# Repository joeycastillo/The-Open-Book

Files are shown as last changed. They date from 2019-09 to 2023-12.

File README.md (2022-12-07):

# The Open Book: Project Reboot

**A note from the project creator:** The Open Book was my first real electronics project; the earliest designs date to late 2019. I have learned a lot since those early days, and as such, here three years later, I am hitting reset. At this time the repository contains a version of the Open Book designed around the Raspberry Pi Pico. It's optimized for low part count and easy hand assembly, but it runs on AAA batteries and may not be as svelte as some folks might prefer. At a later date, I hope to design a followup with built-in LiPo charging and a slimmer profile, but at this time, this version of the book is the quickest path to getting hardware in people's hands so that we can start hacking on firmware together.

For details on how to build, test and use Open Book, I've [made documentation available here](https://www.oddlyspecificobjects.com/projects/openbook/).

The original Open Book repository has been archived in a branch called [original](https://github.com/joeycastillo/The-Open-Book/tree/original).

[The Open Book firmware, called libros, is under development here](https://github.com/joeycastillo/libros). It's a goddamn mess in some ways, and in dire need of some documentation, but for the moment it does do the job of presenting a list of books stored on an SD card, and letting you read them. The canonical format for books is plain text with the book title on the first line, OR plain text plus some front matter and some ASCII control codes for chapter breaks and formatting, [as documented here](https://www.oddlyspecificobjects.com/projects/openbook/#advanced-text-formatting).

## Original Introduction

As a society, we need an open source device for reading. Books are among the most important documents of our culture, yet the most popular and widespread devices we have for reading — the Kobo, the Nook, the Kindle and even the iPad — are closed devices, operating as small moving parts in a set of giant closed platforms whose owners' interests are not always aligned with readers'.

The Open Book aims to be a simple device that anyone with a soldering iron can build for themselves. The Open Book should be comprehensible: the reader should be able to look at it and understand, at least in broad strokes, how it works. It should be extensible, so that a reader with different needs can write code and add accessories that make the book work for them. It should be global, supporting readers of books in all the languages of the world. Most of all, it should be open, so that anyone can take this design as a starting point and use it to build a better book.

## State of the Book

At this time, the Pi Pico book is in decent shape if you want to try your hand at building it yourself. You will need to have two custom things fabricated: the **Open Book Main Board** (which you can get as a bare PCB) and the **Castellated E-Paper Driver** module (which you'll want to have done as a PCBA job). All the files you will need to send out for this can be found in the **Fabrication Files** folder in the project root:

* Upload `OSO-BOOK-C1-04-rounded.zip` to your PCB fabrication house of choice. It is designed to be a two-layer, 1 mm thick PCB, and you can use either an ENIG or lead-free HASL finish.
* If you plan to use JLCPCB's economic PCBA service, upload all three files in `OSO-BOOK-C2-01` to JLCPCB. Opt for a 1 mm thick lead-free HASL finish. Note that the board is slightly wider than it needs to be, just to meet the minimum size requirements for this service.
* If you plan to use PCBWay's PCBA service, upload all three files in `OSO-BOOK-C2-02` to PCBWay. Once again, opt for a 1 mm thick lead-free HASL finish. 

Other Parts: 

* Two of these [side mount buttons](https://www.digikey.com/en/products/detail/würth-elektronik/434351045816/5209090)
* One of these [side-mount switches](https://www.digikey.com/en/products/detail/c-k/JS102011SAQN/1640095)
* One [MEM2075 MicroSD card slot](https://www.digikey.com/en/products/detail/gct/MEM2075-00-140-01-A/9859614)
* One [GD25Q16C Flash chip](https://www.digikey.com/en/products/detail/gigadevice-semiconductor-hk-limited/GD25Q16CTIGR/9484675) with SOIC / SOP8 footprint.
* One [Keystone 1022 dual AAA battery holder](https://www.digikey.com/en/products/detail/keystone-electronics/1022/2137859) (you can get clones on Aliexpress for cheap)
* Two P-channel MOSFETS with SOT23 footprint (I use the DMG3415)
* Two 10kΩ resistors with 1206 footprint.
* Two 10µF capacitors with 1206 footprint (rated voltage >=6.3V).
* One 1µF capacitor with 0805 footprint (rated voltage >=6.3V).
* Seven through-hole slim tactile buttons (3mm by 6mm; [TL1107 type](https://www.digikey.com/en/products/detail/e-switch/TL1107AF130WQ/378976))
* One [GDEW042T2 grayscale e-paper display](https://buy-lcd.com/products/42inch-e-inkanel-spi-interface-buy-eaper-display). (Don't get the tri-color version; it'll end in heartbreak)
* And finally, one [Raspberry Pi Pico](https://www.digikey.com/en/products/detail/raspberry-pi/SC0915/13624793) board

The Open Book is open source hardware: you should feel free to build one yourself, order parts for ten and do a workshop at your local maker space, or even buy parts for fifty and sell them as kits. 

Please steal this book.

I plan to add more documentation in the new year, but until then, [this half-hour video walks through building one Open Book board in real-time](https://twitter.com/i/broadcasts/1OyKAVPjrvaGb).

### Forking and tweaking the boards

* Design files for the Open Book main board can be found in the `OSO-BOOK-C1` folder. It's a KiCad project.
* Design files for the castellated e-paper driver module can be found in the `OSO-BOOK-C2` folder. Alas, they are Eagle projects that predate my move to KiCad. There are two versions: an older version that was successfully fabricated with JLCPCB's economic PCBA service (`OSO-BOOK-C2-01`), and a newer version successfully fabricated using PCBWay's PCBA service (`OSO-BOOK-C2-02`). Both work great.

## License

 Different components of the project are licensed differently, see [LICENSE.md](https://github.com/joeycastillo/The-Open-Book/blob/main/LICENSE.md).

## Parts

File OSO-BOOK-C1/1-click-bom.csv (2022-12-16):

References | Qty | Description | Manufacturer | MPN | Digikey | Mouser | RS | Newark | Farnell | LCSC | JLC Assembly
B1, B2, | 2 | Right-angle push button, SPST |  | 434351045816 | 732-7057-1-ND | 710-434351045816
SW1, | 1 | Right-angle slide switch, SPDT |  | JS102011SAQN | 401-1999-1-ND | 611-JS102011SAQN
BT1, | 1 | Battery holder for 2x AAA cells |  | 1022 | 36-1022-ND | 534-1022
Q1, Q2, | 2 | P-MOSFET transistor, gate/source/drain |  | DMG3415U-7 | DMG3415UDIDKR-ND | 621-DMG3415UQ-7
C1, C2, | 2 | 10µF capacitor, 1206 |  | CL31B106KQHNFNE | 1276-3107-1-ND | 187-CL31B106KQHNFNE
C3, | 1 | 1µF capacitor, 0805 |  | CL21B105KAFNNNE | 1276-1066-1-ND | 187-CL21B105KAFNNNF
R3, R4, | 2 | 10KΩ resistor 1206 |  | RMCF1206JT10K0 | RMCF1206JT10K0CT-ND | 652-CR1206FX-1002ELF
U1, | 1 | Raspberry Pi Pico |  | SC0918 | 2648-SC0918CT-ND | 713-102110537
U3, | 1 | MicroSD card slot, push/push |  | MEM2075-00-140-01-A | 2073-MEM2075-00-140-01-ACT-ND | 640-MEM20750014001A
U4, | 1 | 2 MB Flash memory chip |  | GD25Q16CTIGR | 1970-1010-1-ND | 363-GD25Q16CTIGR
B3, B4, B5, B6, B7, B8, B9, | 7 | Through-hole push button, SPST |  | TL1107AF180WQ | EG2511-ND | 612-TL1107
J1, J2, | 2 | STEMMA connector. OPTIONAL |  | S3B-PH-SM4-TB(LF)(SN) | 455-1790-1-ND
J3, | 1 | STEMMA QT connector. OPTIONAL |  | BM04B-SRSS-TB(LF)(SN) | 455-1750-1-ND
R1, R2, | 2 | 1k resistor, 0805. OPTIONAL |  | RC0805JR-071KL | 311-1.0KARCT-ND | 603-RC0805JR-071KL
U2, | 1 | Oddly Specific castellated E-paper driver module |  | OSO-BOOK-C2-01
Display | 1 | 4.2 Inch B&W E-paper Panel |  | GDEW042T2

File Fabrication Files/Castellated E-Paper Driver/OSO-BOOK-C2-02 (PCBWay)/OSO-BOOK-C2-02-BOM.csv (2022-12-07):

Item # | *Designator | *Qty | Manufacturer | *Mfg Part # | Description / Value | *Package/Footprint | Type | Your Instructions / Notes
1 | R1 | 1 | UNI-ROYAL | 0603WAJ047KT5E | 0.47Ω ±1% 1/16W ±800ppm/℃ 0603 Chip Resistor - Surface Mount RoHS | 0603 | SMD
2 | L1 | 1 | microgate | MGFL2012F100MT-LF | 10uH ±20% 500mA 320mΩ 0805 Inductors (SMD) RoHS | 0805 | SMD
3 | C1, C2, C3, C4, C5, C6, C7, C8, C9 | 9 | Samsung Electro-Mechanics | CL21B105KBFNNNE | 1uF ±10% 50V X7R 0805 Multilayer Ceramic Capacitors MLCC - SMD/SMT RoHS | 0805 | SMD
4 | C10 | 1 | Samsung Electro-Mechanics | CL21A475KAQNNNE | 4.7uF ±10% 25V X5R 0805 Multilayer Ceramic Capacitors MLCC - SMD/SMT RoHS | 0805 | SMD
5 | J1 | 1 | JUSHUO | AFC07-S24ECC-00 | Contact,Top 24 0.020"（0.50mm） 0.079"（2.00mm） Slide Lock 24P FFC, FPC Connectors RoHS | FFC | SMD
6 | Q1 | 1 | Infineon Technologies | IRLML0100TRPBF | N-Channel 100V 1.6A 2.5V @ 25uA 220mΩ @ 1.6A,10V 1.3W SOT-23(SOT-23-3) MOSFET RoHS | SOT-23-3 | SMD
7 | D1, D2, D3 | 3 | LRC | LMBR0530T1G | 30V 500mA 450mV @ 500mA SOD-123 Schottky Barrier Diodes (SBD) RoHS | SOD-123 | SMD

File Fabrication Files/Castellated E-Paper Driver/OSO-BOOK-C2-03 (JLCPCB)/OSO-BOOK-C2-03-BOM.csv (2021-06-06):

Qty | Designator | Footprint | Comment | LCSC Part # | Description
1 | R1 | R0402 | 0.47ohm | C423162 | 0.47Ω ±1% 1/16W ±800ppm/℃ 0402 Chip Resistor - Surface Mount RoHS
1 | L1 | L0805 | 10uH | C281113 | 10uH ±20% 500mA 320mΩ 0805 Inductors (SMD) RoHS
9 | C1, C2, C3, C4, C5, C6, C7, C8, C9 | C0805 | 1uF >=25V | C28323 | 1uF ±10% 50V X7R 0805 Multilayer Ceramic Capacitors MLCC - SMD/SMT RoHS
1 | C10 | C0805 | 4.7uF >=25V | C1779 | 4.7uF ±10% 25V X5R 0805 Multilayer Ceramic Capacitors MLCC - SMD/SMT RoHS
1 | J1 | AFC07-S24ECC-00 | Flex connector | C11092 | Contact,Top 24 0.020"（0.50mm） 0.079"（2.00mm） Slide Lock 24P FFC, FPC Connectors RoHS
1 | Q1 | SOT23-3 | IRLML0100 | C53658 | N-Channel 100V 1.6A 2.5V @ 25uA 220mΩ @ 1.6A,10V 1.3W SOT-23(SOT-23-3) MOSFET RoHS
3 | D1, D2, D3 | SOD-123 | MBR0530 | C18863 | 30V 500mA 450mV @ 500mA SOD-123 Schottky Barrier Diodes (SBD) RoHS

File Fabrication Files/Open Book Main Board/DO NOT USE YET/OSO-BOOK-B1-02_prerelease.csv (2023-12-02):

Comment | Designator | Footprint | LCSC
SW_Push | B1,B2 | Button_Switch_SMD:Panasonic_EVQPUJ_EVQPUA | C128539
10µF | C1,C2,C3,C4,C5,C8 | Capacitor_SMD:C_1206_3216Metric | C13585
4.7µF | C10,C11 | Capacitor_SMD:C_0805_2012Metric | C1779
22pF | C6,C7 | Capacitor_SMD:C_0805_2012Metric | C1804
1µF | C9,C12,C13,C14,C15,C16,C17,C18 | Capacitor_SMD:C_0805_2012Metric | C28323
MBR0530 | D1,D2,D3 | Diode_SMD:D_SOD-123 | C475718
MBR120 | D4 | Diode_SMD:D_SOD-123 | C130880
USB_C_Receptacle_USB2.0 | J1 | Connector_USB:USB_C_Receptacle_HRO_TYPE-C-31-M-12 | C2765186
Conn_01x02_MountingPin | J2 | Connector_Molex:Molex_PicoBlade_53261-0271_1x02-1MP_P1.25mm_Horizontal | C668614
Conn_01x24 | J3 | Connector_FFC-FPC:TE_2-1734839-4_1x24-1MP_P0.5mm_Horizontal | C11092
47µH | L1 | Inductor_SMD:L_Taiyo-Yuden_MD-4040 | C341779
DMG3415 | Q1,Q2 | Package_TO_SOT_SMD:SOT-23 | C96616
IRLML0100 | Q3 | Package_TO_SOT_SMD:SOT-23 | C53658
5.1k | R1,R2 | Resistor_SMD:R_0805_2012Metric | C27834
100K | R11,R12,R13,R14,R15 | Resistor_SMD:R_0805_2012Metric | C149504
1k | R3,R9,R10 | Resistor_SMD:R_0805_2012Metric | C17513
200k | R4 | Resistor_SMD:R_0805_2012Metric | C17539
10K | R5 | Resistor_SMD:R_0805_2012Metric | C17414
2.2 | R6 | Resistor_SMD:R_0805_2012Metric | C17521
1M | R7 | Resistor_SMD:R_0805_2012Metric | C17514
XC6220B331MR-G | U1 | Package_TO_SOT_SMD:SOT-23-5 | C3040644
ESP32-S3-WROOM-1 | U2 | RF_Module:ESP32-S3-WROOM-1 | C2913198
MEM2075 | U3 | MEM2075-00-140-01-A:GCT_MEM2075-00-140-01-A | C393941
MCP73831-2-OT | U4 | Package_TO_SOT_SMD:SOT-23-5 | C424093
32768 / 12.5pF | Y1 | Crystal:Crystal_SMD_3215-2Pin_3.2x1.5mm | C32346

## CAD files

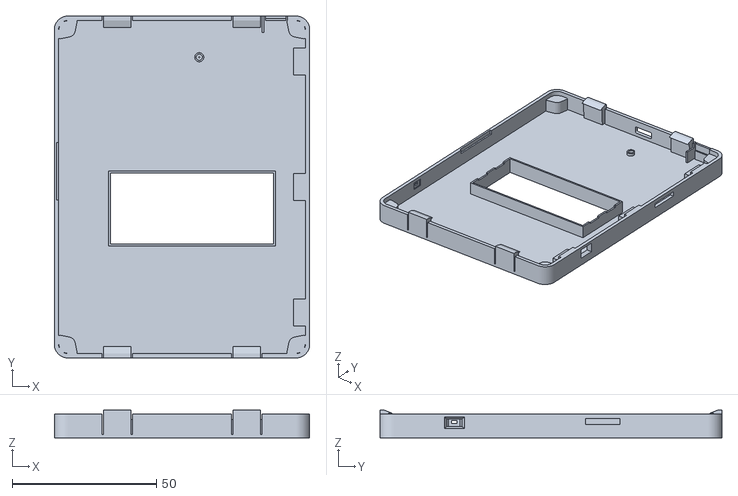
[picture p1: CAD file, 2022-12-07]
3D Printed Case/Open Book Abridged - Minimal Case.stl
88.6 x 118.6 x 9.60

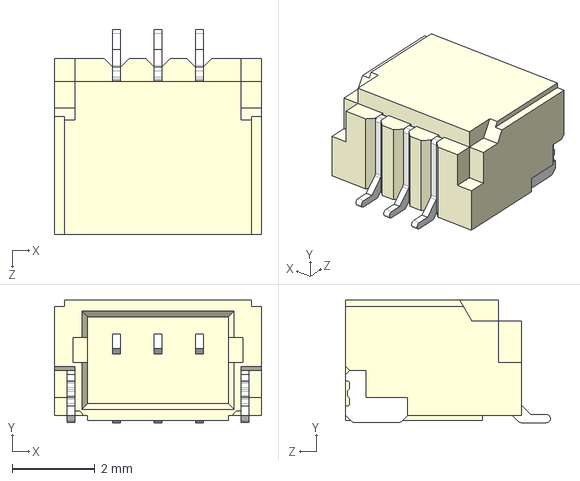
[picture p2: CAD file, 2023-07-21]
OSO-BOOK-B1/SM03B-SRSS-TB(LF)(SN)--3DModel-STEP-56544.STEP
5.00 x 2.96 x 4.95 mm

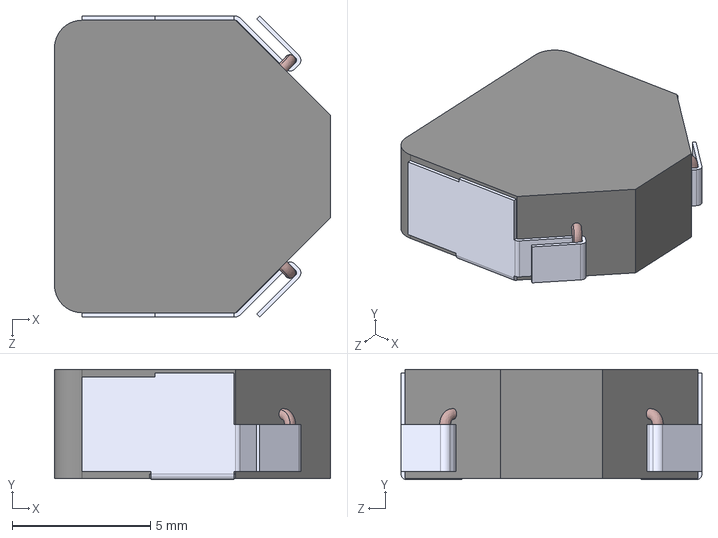
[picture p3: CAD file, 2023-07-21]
OSO-BOOK-B1/DFEG10040D-100M=P3.STEP
10.0 x 4.00 x 10.9 mm

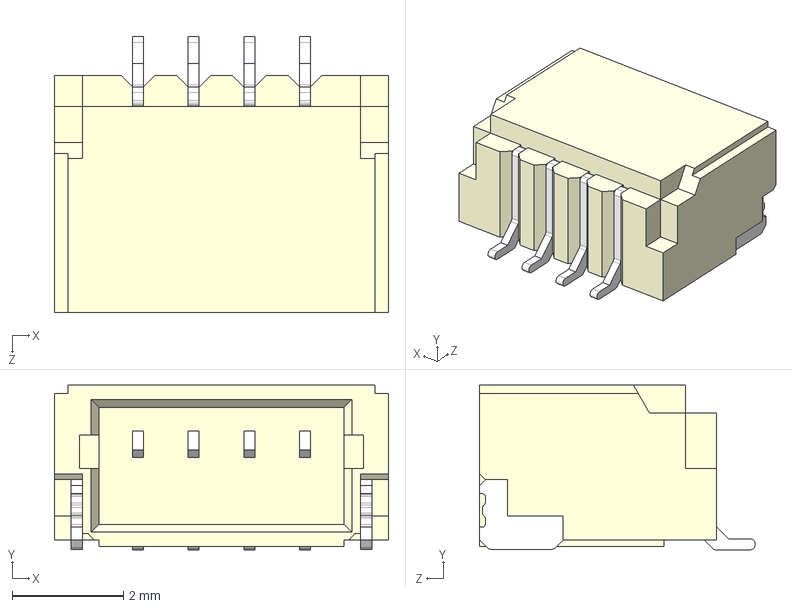
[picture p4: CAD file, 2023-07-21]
OSO-BOOK-B1/SM04B-SRSS-TB(LF)(SN)--3DModel-STEP-56544.STEP
6.00 x 2.96 x 4.95 mm

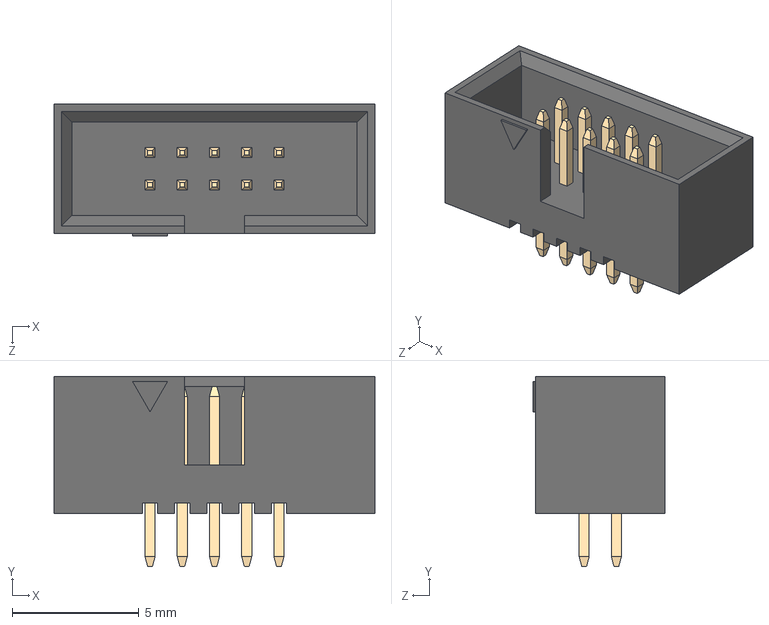
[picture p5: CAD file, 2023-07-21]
OSO-BOOK-B1/CONB127P-2R-10W_TH.STEP
12.7 x 7.50 x 5.20 mm

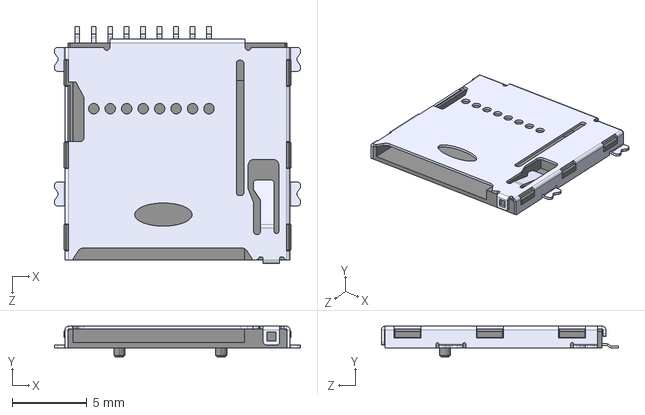
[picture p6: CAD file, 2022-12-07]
OSO-BOOK-B1/MEM2075-00-140-01-A--3DModel-STEP-56544.STEP
16.4 x 2.05 x 15.9 mm

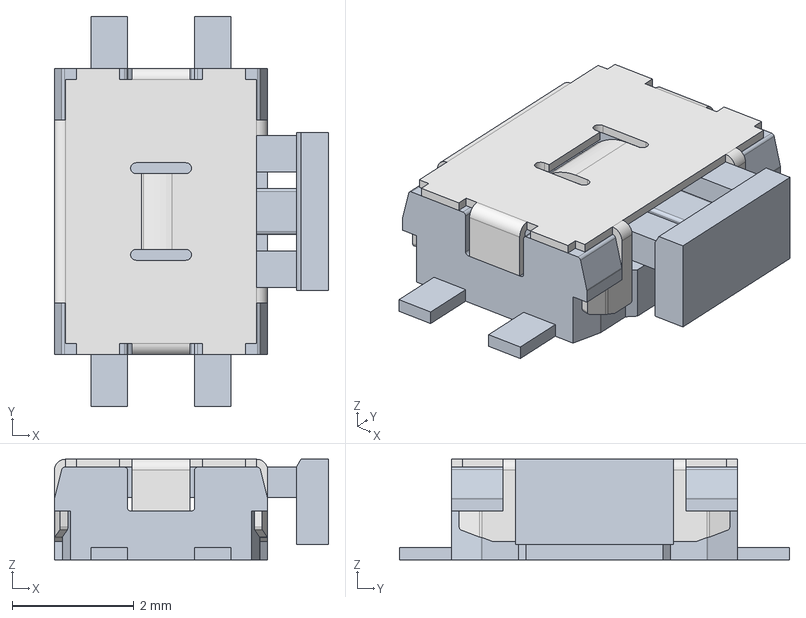
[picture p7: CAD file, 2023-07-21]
OSO-BOOK-B1/434351045816_Download_STP_434351045816_rev1.stp
4.50 x 6.40 x 1.65 mm

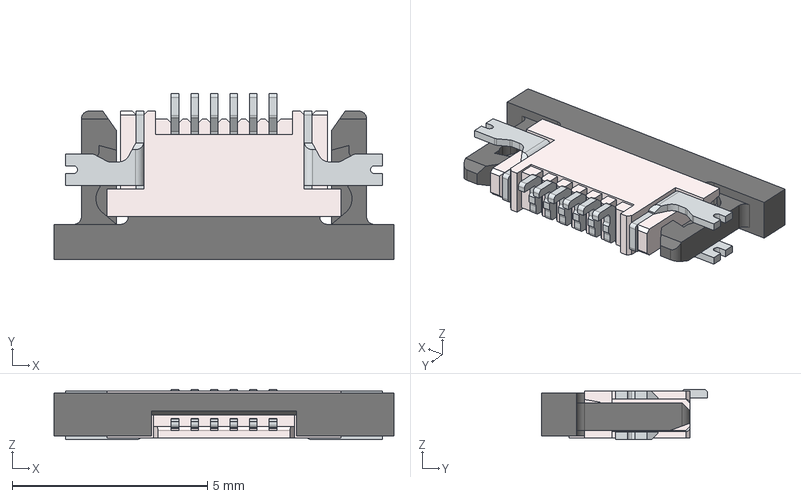
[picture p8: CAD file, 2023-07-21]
OSO-BOOK-B1/687106183622.stp
8.70 x 4.25 x 1.29 mm

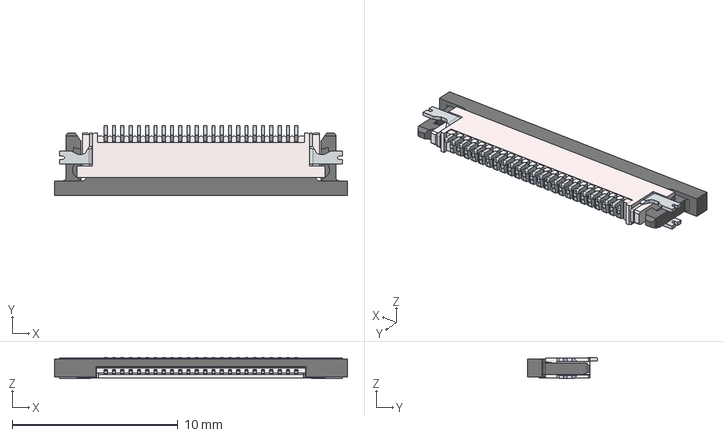
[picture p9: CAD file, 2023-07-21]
OSO-BOOK-B1/687124183622.stp
17.7 x 4.25 x 1.29 mm

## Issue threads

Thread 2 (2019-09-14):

Questions

mistergibson, 2019-09-14:
Dear Mr. Castillo,

1.  Will you use the e-Ink electronic paper at 1200+dpi?

2.  Have you considered using mRuby (embedded Ruby) ( Found Here: https://github.com/mruby/mruby ) in place of the Python selection?

3.  What are the best batteries to use? : I get about 2 weeks out of my Kindle-Paperwhite.

I just also wanted to say Thank You for doing this. I have long wanted an ebook reader unbound to any one corporation. I would spend $150 - $200 to get one that is well designed. I don't need color, and I don't want to watch movies >>> what I want is a high-dpi book-like experience in an ebook reader independent of any one corporation. If you do an at-cost business around this idea please also consider accessorizing with a small USB-based Solar charger for it. You've inspired me just by doing this project. Good Luck to you.

mistergibson

Dragoon91786, 2019-09-14:
Furthermore, if the project decides to use E-Ink/E-Paper, will it use the full color format? httpss://goodereader.com/blog/electronic-readers/e-reader-companies-will-adopt-color-e-paper-in-2018

Dragoon91786, 2019-09-14:
@mistergibson, have you heard about the newer Li batteries that don't wear down over time to any degree as the older ones?

There's also new rechargable alkaline batteries.

I saw in 2012 tech from Northwestern that was using crystals as well. Another possibility would be newer https://en.m.wikipedia.org/wiki/Solid-state_battery as an option if the device uses a universal standard battery plug. One factor with these devices is the lack of universal battery comparability. It would be nice to have a device that could use various sizes and batteries available if necessary. Not necessarily ideal in some minds, but if it could act as a more sophisticated version of the AK-47 in terms of ammo (but from the standpoint of a battery), it would definitely make the devices more universal. Much like how one can run a D battery with adapters using C, B, A, AA, AAA, etc.

joeycastillo, 2019-10-31:
> Will you use the e-Ink electronic paper at 1200+dpi?

At this time I am targeting lower-resolution, inexpensive displays that are widely available. I do not know of a source for 1200dpi screens.

> Have you considered using mRuby (embedded Ruby) ( Found Here: https://github.com/mruby/mruby ) in place of the Python selection?

I have not, currently my experience is in Arduino and CircuitPython, but you're more than welcome to hack on mRuby if you're stoked about it!

> What are the best batteries to use? : I get about 2 weeks out of my Kindle-Paperwhite.

I'm currently using [this battery from Adafruit](https://www.adafruit.com/product/3898) because it fits nicely between the Feather headers. Eventually when an enclosure is built it might make sense to have room for a larger battery, but I have no sense at this time what battery life will be like.

> if the project decides to use E-Ink/E-Paper, will it use the full color format?

I doubt it as I have not seen a source for full-color eInk panels. I have done tests with some tri-color panels, but their refresh rate is far too slow to allow for a good reading experience.

Closed 2019-10-31.

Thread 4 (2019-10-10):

License

sharpaper, 2019-10-10:
What's the license of this project and the PCBs?

Velua, 2019-10-10:
AGPLv3!

sharpaper, 2019-10-10:
I've actually noticed that the PCBs have a cc-by-sa license printed at the bottom. I see no files mentioning AGPL.

joeycastillo, 2019-10-31:
The boards are CC-BY-SA 4.0.

Closed 2019-10-31.

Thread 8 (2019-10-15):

Contribution Guide

hazkaz, 2019-10-15:
Hi @joeycastillo , this is a great effort and idea. It would be nice if you could put up a contribution guide for people like me wanting to work on this project. Thanks.

ech0r, 2019-10-15:
I would like to contribute as well. I came across this project on Hacker News.

titimoby, 2019-10-15:
How do you think we can help you?

To have more code contribution quickly, do you think a simpler device like only a feather M4 with a e-ink wing directly from adafruit could be a first base to help you?

hazkaz, 2019-10-17:
How do we find out what other boards will be compatible with the software? Since the hardware is likely to change in the future, how do we make the code more compatible with other hardware?

titimoby, 2019-10-17:
Don't be sorry, as I can see, there is quite a lot of people interested and you have many questions ;)
I'm sure you need some time to have a proper hardware you are happy with and I will wait.

But in the meantime, I was wondering if existing pieces from Adafruit can be put together to start messing with software: I mean something usable even if it is on a breadboard with plenty of wires.

joeycastillo, 2019-10-17:
Actually yes! Mostly. There are a couple of parts you'd need from elsewhere (namely the [screen](https://zh-tw.buyepaper.com/42inch-e-ink-panel-spi-interface-buy-e-paper-display-p0085.html) and a spare [SPI Flash chip](https://www.digikey.com/product-detail/en/gigadevice-semiconductor-hk-limited/GD25Q16CTIGR/1970-1010-1-ND/9484760) for Babel stuff), but beyond that you can build the equivalent of the wing with:

* 1x [eInk friend](https://www.adafruit.com/product/4224)
* 1x [microSD breakout](https://www.adafruit.com/product/254)
* 1x [MCP23008](https://www.adafruit.com/product/593)
* 1x [mono headphone jack](https://www.adafruit.com/product/4031)
* 1x [SOIC-8 breakout](https://www.adafruit.com/product/1212) (for the Flash chip)
* plus some [buttons](https://www.adafruit.com/product/1489) and a [switch](https://www.adafruit.com/product/805)

But if you're comfortable with the soldering, honestly I'd recommend just building the wing; it's fun to hold and makes hacking on it a joy. If there's enough interest I might make a small run of like 10 of Rev C just to get them out into the world; aside from the 24-pin header, which I could probably reflow here, all the rest of the soldering is pretty doable by hand. It's all SOIC chips and 0805 surface mount, nothing too intimidating.

titimoby, 2019-10-18:
I have no issue with soldering even if I only know hand soldering until now.
This project could be a good first for smd soldering.
Let me know if you decide to launch a batch of Rev C, I'll be glad to buy one and experiment.

liamdawson, 2020-01-02:
I have zero electronics experience, are there any simulators I could try things out in? I was once investigating the possibility of doing firmware for a different SoC (RTL8710AF) in Rust, would be fascinated to see if I could apply that idea in this scenario.

AndersCulverD5, 2020-02-02:
@joeycastillo I came across this project recently and I'm also interested in helping in some way. I'm a junior embedded software engineer and I've been looking for cool projects to contribute to. Is the list of parts needed to do development the same as your previous reply from October? Let me know if there is something that I could try to hack on!

beelzebielsk, 2020-03-08:
I am also interested in this project, and in contributing to it. I recently bought a kindle, and while I like the experience, I want something open that I can hack on. I realized my reading device is a very personal thing, as my reading experience is.

I have no electronics experience, but I am a junior software engineer.

braininahat, 2020-06-20:
I too would like to contribute to this project. I have experience in all sorts of things from embedded to computer vision and can do software architecture design stuff too. Is there a mailing list or something where you discuss the roadmap?

joeycastillo, 2020-06-20:
Hey all and I'm so sorry for dropping the ball on this thread. It's been a strange year.

The situation as it stands: I have PCBs of the E-Book FeatherWing [available on Tindie](https://www.tindie.com/products/joeycastillo/the-e-book-wing-pcb-bare-pcb/); this is a bare PCB that, when assembled, is designed to work with a Feather M4 Express to enable most of the functionality of the Open Book. I chose to make this design available first since it's a simpler build. The BOM is [available on KitSpace](https://kitspace.org/boards/github.com/joeycastillo/the-open-book/), and with their browser extension it's one click to order almost all of the parts on DigiKey.

I also have PCBs of the Open Book that I plan to make available later this week on Tindie; I just want to finish up some documentation and the software necessary for flashing the bootloader and testing the device. The boards will show up [on this page](https://www.tindie.com/stores/joeycastillo/) when available. And the same Open Book library in this repository should work seamlessly on both the E-Book Wing and the Open Book.

While it's not quite a contribution guide, I'm working on some [rather extensive documentation on the Open Book](https://github.com/joeycastillo/The-Open-Book/wiki/Open-Book-Documentation); as of now it's 12,000 words and covers both tips for building the device, and the documentation you would need to start developing for the device. I'll also be making a final BOM with one-click ordering available on Kitspace in the coming days.

I've been focused on getting the PCB's available and writing basic software drivers for things like the e-paper display and the [language support](https://github.com/joeycastillo/babel), but I have not had as much time to dedicate to the e-book reading software. There is [a demonstration sketch called MVBook in this repository](https://github.com/joeycastillo/The-Open-Book/tree/master/Examples/Open_Book_MVBook) that shows a sort of minimum viable prototype for what I hope the software will look like ([video here](https://twitter.com/josecastillo/status/1220433844035297280)). I have some ideas about how I might want to architect the software, and opinions about what texts should look like (plain UTF-8 text with simple YAML or TOML front matter), but no formal roadmap for this.

I am hoping to make moves on this effort in the month of July, including documentation around the software effort and a more formal guide for contributors; I had hoped to be far further along by now, but I'm afraid I've been more scattered this year than I would have liked. In the meantime I welcome any suggestions or contributions in this thread, and will respond here as soon as I have the Open Book PCB's available for folks who want to build their own.

Closed 2022-12-07.

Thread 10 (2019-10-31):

Suggestions: Linux board; larger display of 8 or 9 inches; 3D printed enclosure

casainho, 2019-10-31:
Hi.

Great project, the motivation correct and is strategic!! and I would love to use the final version.

Some ideas:
- some board to run Linux, I guess that would mean much easier and fast development, possible much easier to find developers to join on the software side
-- why not Raspberry Pi Zero W, that is very popular, is very easy to source and should stay long on the market. Includes Wifi and Bluetooth, meaning possible wireless sync of ebooks in future to PC or mobile
- 3D print enclosure: I think you just need to define it and someone on community will design, test, print and share the 3D files
- larger display, I guess at least 8 or 9 inches. Would be nice if user could decide the size and the changes could be mainly on display size + 3D printed enclosure

baconwaifu, 2019-10-31:
The first request is not a goal of this project. The goal is to build a *simple* open ebook reader.

If you want to modify it to work with a pi zero, go ahead. the display is driven by a standard SPI bus, and if you do it right, the board can be flush-mounted without needing headers. you'd need to figure out a different power source though, as the pi does *not* have onboard battery management hardware like the feathers do.

casainho, 2019-10-31:
> The first request is not a goal of this project. The goal is to build a _simple_ open ebook reader.
>
> If you want to modify it to work with a pi zero, go ahead. the display is driven by a standard SPI bus, and if you do it right, the board can be flush-mounted without needing headers. you'd need to figure out a different power source though, as the pi does _not_ have onboard battery management hardware like the feathers do.

When you mean simple, I guess is on hardware, so this can be easy DIY. I must say I don´t have experience with Raspberry Pi Zero and I understand that user should need to do the least possible work with hardware, that is a big barrier.

Here is another Linux board that runs directly from a lithium cell: PocketBeagle -- https://www.adafruit.com/product/4179

_**DESCRIPTION**
Want a powerful 1GHz AM3358 powered Linux single board that's ultra-tiny and open-source? PocketBeagle offers a wealth of computer power in a small footprint (pawprint?). This board is just like the BeagleBone Black but small enough to fit in your wallet. It has a fully-integrated chip that combines the processor and RAM all on one chip, so it's super small. Despite the compact shape, there are 72 total breakout pads, a microSD card slot for your filesystem and OS, and a native USB connection

Compared to other single board Linux computers, what differentiates the BeagleBone is that it has multiple I2C, SPI and UART peripherals (many boards only have one of each), built in hardware PWMs, analog inputs, and two separate 200MHz microcontroller system called the PRU that can handle real-time tasks like displaying to RGB matrix displays or NeoPixels.

It's not too much larger than our Feathers, but comes with 72 expansion pin headers, high-speed USB, 8 analog pins, 44 digital I/Os, and plenty of digital interface peripherals._

JIVS, 2019-10-31:
I dont mind the small display but the biggest problem IMO is the low resolution it has which limits its usability to look graphics in PDFs or read graphic novels.

Many ereaders already offer 300ppi screens at this size, are there any display units for sale with these specs?

danielbarry, 2019-10-31:
I think something like an Allwinner A13 could be appropriate in the TQPF package, which is hand-solderable [1]. Apparently you can pick these up for ~$1 in the right quantities [2]. The hardest part is the DDR2/3 RAM requirement, which (as far as I'm aware) could be solved using laptop RAM and an appropriate connector [3]. That way you've got an open hardware device running Linux that can be soldered in your garage.

Once that hardware is solved, you get a bunch of stuff for free, like tonnes of software stacks and hardware support - and enough processing power to likely be able to support future formats too.

I think whilst the hardware would be a pain in the arse (correctly interfacing with DDR2/3 RAM and compiling the Linux kernel), once it's running Linux the software should be a piece of cake (some front end connecting several existing programs together).

To really accelerate things, you could start with the Olimex A13-SOM-512 [4] and later use their chips [5].

Just an idea :)

[1] https://linux-sunxi.org/A13
[2] https://www.eevblog.com/forum/microcontrollers/the-$1-linux-capable-arm-processor-in-tqfp/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;topicseen
[3] https://nz.mouser.com/Connectors/Memory-Connectors/Memory-Socket-Connectors/DIMM-Connectors/_/N-axja5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
[4] https://www.digikey.com/product-detail/en/olimex-ltd/A13-SOM-512/A13-SOM-512-ND/6580705
[5] https://www.olimex.com/Products/Components/IC/A13/

joeycastillo, 2019-10-31:
Hi and thanks for the suggestions!

>some board to run Linux

I agree with previous commenters that this is a bit beyond the scope of the project, but if you have an interest in this I'd suggest playing with the [Giant Board](https://www.crowdsupply.com/groboards/giant-board) in conjunction with the [eBook FeatherWing](https://github.com/joeycastillo/The-Open-Book/tree/master/eBook%20Feather%20Wing) in this repo. I don't have a Giant Board myself, and I don't know what the state of eInk drivers is on Linux, but that would be a quick way to start hacking on it.

> 3D print enclosure: I think you just need to define it and someone on community will design, test, print and share the 3D files

I had designed a 3D printed enclosure for Rev A, but have not updated it since I think I'm going to end up doing a laser cut enclosure instead. Right now the priority is finalizing the design of the board; making an enclosure for hardware that's still in flux feels like putting the cart before the horse. And anyway. I won't have access to my laser cutter or 3D printer until the end of the month.

> larger display, I guess at least 8 or 9 inches

In theory [this 7.5 inch display](https://zh-tw.buyepaper.com/75-inch-large-e-paper-display-higher-resolution-800x480-spi-interface-black-and-white-gdew075t7-p0217.html) would be drop-compatible, although I have not tested it. The reason I'm sticking with the small display is cost: [$18 for the 4.2 inch](https://zh-tw.buyepaper.com/42inch-e-ink-panel-spi-interface-buy-e-paper-display-p0085.html) versus $52 for the larger panel makes a big difference. [Above 8 inches](https://zh-tw.buyepaper.com/c/80-1248-inch-0388) the cost becomes prohibitive, and anyway you end up needing a more complex interface to drive the screen.

>I dont mind the small display but the biggest problem IMO is the low resolution

I have my eye on this [higher-resolution panel](https://zh-tw.buyepaper.com/43-inch-low-power-consumption-e-paper-p0093.html) for a future revision, but the issue there is that it uses a parallel interface instead of SPI, and I'm not aware of the state of Arduino libraries for that type of display. I'd also need to free up some pins on the SAMD51 because right now all of them are spoken for. 😬
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
justinclift, 2019-11-19:
> Your attempt to avoid using Linux is wrong and counterproductive.

How is it counterproductive?  Really not seeing how this is taking away from the world, instead of contributing.

> I applaud the intent, but you vastly underestimate the scope of software work needed to get where you want to go.

It might turn out ok anyway, as people can figure out some pretty creative solutions when the need arises.  Regardless of that, it's an interesting exercise and (being OSS) provides a base other people can look at + learn from.

joeycastillo, 2019-11-20:
> Your attempt to avoid using Linux is wrong and counterproductive.

Like many things in engineering it’s the result of a compromise. Linux would require a more expensive MPU and more RAM, which means more pins, which (I sense) means a BGA package and maybe even a 4-layer PCB with tighter (read: $$$) manufacturing constraints. For a project that aims to be inexpensive, comprehensible and hand-solderable, this $4.00, 64-pin microcontroller hits a sweet spot.

> internationalization and proper font rendering

This is another area of compromise. We may not have “proper” font rendering, but if we limit ourselves to ≤16x16 bitmapped glyphs, we can [fit the entire basic multilingual plane onto a 2MB flash chip](https://github.com/joeycastillo/babel). It ain’t Caslon and it ain’t libicu, but it gets us readable text, localized case mapping and Arabic shaping for like 50¢.

> to say nothing of features like note taking, bookmarks, and the ability to fetch content over USB or the network, require a modern general purpose OS.

Just to reiterate what was said earlier in the thread: [the Giant Board is real and it’s shipping next month](https://www.crowdsupply.com/groboards/giant-board). Plug it into the ebook wing and you’ve got a solid platform for building the kind of device you’re describing. Add [an AirLift wing](https://www.adafruit.com/product/4264) and you’ve got network connectivity. If you get that working, a Linux Open Book becomes a matter of merging schematics and routing traces (although the SAMA5D2 chip is only available in a BGA package which, again, limits hand-solderability for DIY folks).

> The design as it stands now... vastly underestimate[s] the scope of software work needed to get where you want to go.

I fully recognize that there’s a lot of software work ahead. But folks once _wrote_ books on machines more constrained than this. I sense that we can get there.

liamdawson, 2020-01-02:
Running Linux would have a negative effect on battery life, by necessity. It operates with more overhead than a dedicated software package.

For argument's sake, let's say we do need things that don't exist here, and do in Linux. If we run with something simple like this and find out that it's not enough, at least we'll better understand what we actually need. And because this is being done in the open, everyone can benefit from that knowledge. For that reason, I'm glad it's being done this way.

justinclift, 2020-01-02:
> ... making an enclosure for hardware that's still in flux feels like putting the cart before the horse.

Very much this.  Anything that's done before the "release" version :wink: would just be prototype needing adjustment at the end.  Though if someone wants to iterate on designs for that it's not a bad idea.

For myself, I have access to 3D printers and ~low end CNC machines (3 and 4 axis).  Can't do metal though, so my wish for some nice brushed aluminium case isn't going to happen with the gear here. :roll_eyes:

joeycastillo, 2020-01-02:
An update on the enclosure actually: I designed [something basic here](https://www.tinkercad.com/things/ldEVxcvDpKJ-open-book-3d-printed-enclosure) that's suitable for 3D printing and works with the Open Book. It would need some tweaks to work with the eBook Wing; the positions of the enable switch and headphone jack are a bit different on that board. But you use that same design it to generate laser-cut SVG's that work with both. The laser cut option is open on all sides, and if you rotate the back piece 180 degrees, the cutout for the feather header cutout will line up.

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

Both enclosures are held together with nylon screws, nuts and standoffs; I have [this kit](https://www.adafruit.com/product/3299) and it had parts that worked for me.

justinclift, 2020-01-03:
Awesome. :smile:

Interesting kit.  Generally I've found 2.5mm stuff to be "too small", instead preferring 3mm hardware for MDF.  Maybe I just need to try more 2.5mm hardware. :wink:

Closed 2022-12-07.

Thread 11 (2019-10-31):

Will you be selling these?

nerdguy1338, 2019-10-31:
I love this concept, but is this a design to hack upon, or plans for a final product that is open hardware?

joeycastillo, 2019-11-01:
That's a great question, and one for which I don't have a great answer just yet. I can assemble prototypes myself, but that doesn't scale well enough to sell them in any quantity. I guess my vision is that people would build these themselves — you can do it with a stencil, tweezers and [a toaster oven](https://learn.adafruit.com/ez-make-oven?view=all) — but I'm also willing to look into manufacturing. It's not 100% in my wheelhouse, but then neither was PCB design a year ago :)

nerdguy1338, 2019-11-01:
That's the thing, most of the board you designed is through-hole, except
the feather itself. I've never done surface mount soldering, and I'm not
really comfortable gambling this much money on a kit of parts.

Why is the feather not also through hole?

On Thu, Oct 31, 2019, 10:40 PM joeycastillo <notifications@github.com>
wrote:

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

joeycastillo, 2019-11-01:
Basically because the e-ink screen is fragile glass, and needs to adhere directly to the the front of the PCB for structural support. Most of the board is surface mount actually, specifically so that the front of the PCB can be a smooth and flat surface for the screen to sit on; all the thru-hole pieces are above and below the screen.

Totally sympathize though with your concern... I was also very intimidated by surface mount soldering and had to learn some new skills to make this. FWIW except for two tricky parts (the SAMD51 and the 24-pin connector) I chose wide-pitch SOIC chips and 0805 or larger passives, so that it would be as easy as possible to pick and place by hand. It's not as easy as thru-hole, but it's definitely doable, especially if you practice on some simpler surface mount boards to start with.

AsherGomez, 2019-11-02:
Hey, awesome project! I like that it works with a Feather ecosystem. You should submit it on Hackaday.io for this [contest](https://hackaday.io/contest/168107-take-flight-with-feather) that’s running right now, good luck!

nelsonblaha, 2020-04-14:
Someone willing and able to make these to-order should name their price here. I think they would be pleasantly surprised at the demand.

gromain, 2020-04-20:
I believe those could be made by quantities 100 for between 150-200$ piece (complete assembled with casing and shipping).

1094, 2020-05-07:
I understand the not wanting to sell completed readers, but have you considered selling kits?

joeycastillo, 2020-05-08:
It's not the Open Book per se, but I did have a run of the E-Book Featherwing PCB's made, and as of today [they are available on Tindie](https://www.tindie.com/products/joeycastillo/the-e-book-wing-pcb-bare-pcb/). I started with this board since It's simpler to build than the Open Book, and if you pair it with a Feather M4, it works seamlessly with the Open Book Arduino library. Not quite a kit, but the BOM is included as a spreadsheet you can upload to Digikey, and the only other part you'd need is the e-paper display which is [available from Good Display](https://zh-tw.buyepaper.com/42inch-e-ink-panel-spi-interface-buy-e-paper-display-p0085.html).

I imagine I will likely do a similar run with the Open Book PCB at some point, but this is what I have today :)

Closed 2022-12-07.

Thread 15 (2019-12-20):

Wifi?

jhubbardsf, 2019-12-20:
Hi, it doesn't look like this thing has wifi. Would there be any big issues with switching the main chip to an ESP32 which would have built in wifi and bluetooth?

joeycastillo, 2019-12-20:
Thanks for the suggestion! I sense that it might be possible to build this around an ESP32. The eBook Wing actually works with [an ESP32 Feather](https://www.adafruit.com/product/3591) so I know that this is within the realm of the possible. And a lot of the Arduino code would be totally cross platform. But some of the more advanced use cases, like TensorFlow for voice commands or MP3 playback, use SAMD51-specific timers and registers and whatnot, so in terms of software, trying to switch to the ESP32 would be a pretty big change.

For the moment I'm imagining the main use case as reading books or listening to audiobooks that are stored on a microSD card, and plugging the book into a computer with wifi so you can manage the content on the card. For on-device WiFi, you can add an [AirLift FeatherWing](https://www.adafruit.com/product/4264); it plugs into the Open Book like a backpack. I may eventually add this functionality (ESP32 as wifi coprocessor) to the main board if folks seem to find it useful; it's all just a balance of functionality and cost.

jhubbardsf, 2019-12-20:
I've never programmed for the SAMD51, is its framework RTOS based? The ESP32 uses ESP-IDF (well it can use whatever, but that's the official framework for it) which is based on FreeRTOS and can do almost anything. The ESP32 chip is only about 2 bucks so cost wise it's not a lot more. And it could completely replace the SAMD51 I believe. I'm not sure the time that would take to refactor. I've ported code from Arduino to FreeRTOS/ESP-IDF code a couple times so if you ever decide you wanna add wifi capabilities feel free to ping me. I'd be happy to help in my spare time. Cool project!

5a384507-18ce-417c-bb55-d4dfcc8883fe, 2020-04-12:
I don't want to create a whole separate issue for this since it probably will never be done, or only in a long, long, long time, so I'll ask here.  If wi-fi is implemented with that chip, would it be possible to build a very basic UI that connects to Lichess? It's just I always imagine playing on an e-reader would feel great.

jhubbardsf, 2020-04-12:
I just checked out Lichess because I wasn't familiar with it. I don't see why a basic UI wouldn't be able to be built for the ESP32 that communicates with the Lichess API. So I'd say very possible and fun!

5a384507-18ce-417c-bb55-d4dfcc8883fe, 2020-04-13:
It's fully open source and privacy friendly, it is a great project.  I can imagine the pixel piece set looking awesome on the Open Book, lol.  I like this because I feel that I'm not fully concentrated playing on my PC since there are so many things that can distract me, playing on an e-reader would be perfect, I hope this could be done some day.

jhubbardsf, 2020-04-14:
With the quarantine going on I've been a bit bored lately. Maybe I'll throw some time behind the ESP32 port of this device. Unless someone gets to it before me I'll draw up the schematics and PCB design for the ESP32. I'll keep this thread updated.

joeycastillo, 2020-04-15:
I think this is a great idea! I'd also consider checking out the new [ESP32-S2 module](https://www.espressif.com/en/news/espressif-announces-%E2%80%A8esp32-s2-secure-wi-fi-mcu) if you're looking at porting it over; it's a single core, but the low power stuff seems like a big win for an ebook use case, and it has even more GPIO than the previous ESP32. I sense we're going to see an explosion of gadgets based around this chip soon :)

5a384507-18ce-417c-bb55-d4dfcc8883fe, 2020-04-18:
> With the quarantine going on I've been a bit bored lately. Maybe I'll throw some time behind the ESP32 port of this device. Unless someone gets to it before me I'll draw up the schematics and PCB design for the ESP32. I'll keep this thread updated.

That's really cool, I hope you do that and can implement it, I would love to see something like that and being able to play chess on an e-reader and other cool stuff.

val-storm, 2020-08-18:
Some friends and I are planning to make a wifi port of both the board and the software if necessary. Our interest is based in the fact that we are currently making a very, very large data set of plain text books formatted as json behind a REST api or something similar. Basically, the data set will be used for fun ML projects, but also need a lot of editing due to all the automation in the pipeline. So, we are hoping to have these able to search and query the api like a massive library or wiki. "Volunteers" welcome to "find errors" in our huge "plain text data set".

Any progress on the wifi enabled board?
Is there a specific Feather that is wifi and plug and play with current board?
This device strikes me that it could take an approach similar to the ornament and crime project https://ornament-and-cri.me/user-manual-v1_3/ ...it's an instrument/tool, but has a few open source apps that can be selected... I think it might be interesting to go from say, playing a game of lichess with a friend, to reading streamed content from a 200,000 book plain text archive... to...??

Let me know if this sounds cool and if we could plug in anywhere. Great project!

joeycastillo, 2020-08-18:
Awesome!! For my part I have not made any moves on a wifi version of the board; I've been instead focusing on software support for the existing hardware, as well as some experiments with new screens. In the back of my mind this does feel like a perfect [ESP32-S2](https://www.espressif.com/en/products/socs/esp32-s2) project, but what's stopped me there is that board support for that module is just getting started.

Still, both the Open Book and the E-Book Wing are compatible with the [Adafruit AirLift FeatherWing](https://www.adafruit.com/product/4264), which uses the original ESP32 as a wifi co-processor via the Feather's SPI bus (plus pins 11, 12 and 13). That would get you started with wifi on this device, right now.

It might be a tight squeeze but if you removed the Feather headers and moved some stuff near the lock button, you might be able to fit an ESP32 onto the Open Book board (and maybe even give it its own dedicated SPI bus with the freed-up pins. This is the approach Adafruit takes with their [PyPortal device](https://learn.adafruit.com/adafruit-pyportal?view=all), which uses the well-supported SAMD51 as the main processor, and has the ESP32 available for wifi stuff. This has the added benefit of Adafruit's [really excellent software support](https://learn.adafruit.com/adafruit-airlift-featherwing-esp32-wifi-co-processor-featherwing?view=all) for this use case.

Let me know if there's anything I can do to help! FWIW I think both options are sound, I just haven't had the bandwidth to explore them :)

val-storm, 2020-08-18:
Okay. Great. I guess for simplicity we'll get started with the wifi shield.
and hopefully we don't paint ourselves into a corner.

we have kicad experience and could start building a kicad version for
future use. is the goal to forgo dev boards and have the mcu on the open
book pcb?

We're really excited about the overlap of these two projects. I think the
ability to query an all text internet library--i mean data set--would be a
cool easter egg in the firmware.

oh, and, what state is the voice command stuff? what model were you
planning on using? we might be able to help there if need be, because given
the limited controls we were thinking voice search would be helpful.

Best,

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

joeycastillo, 2020-08-19:
As it stands now the Open Book does have the MCU on the board (SAMD51J19A); the Feather header is there for compatibility with wings so that folks can add functions and test out other use cases. But you could for the most part just remove the wing connectors and replace that area with whatever bits of whichever wing you wanted to use. Although with the ESP32 you'd probably want to have the antenna closer to the edge and add a cutout in the ground pour.

It does sound like an exciting concept! Stoked to see what y'all come up with. As for voice commands, I will say that where last I left off, it's a bit less versatile than what might be required for voice search. The [Open_Book_Heart_Of_Darkness_TensorFlow](https://github.com/joeycastillo/The-Open-Book/tree/master/Examples/Open_Book_Heart_Of_Darkness_TensorFlow) demo uses TensorFlow Lite and a model trained with just three words — "Left", "Right" and "Go" — to navigate a menu of items for turning pages. I haven't touched that example since late last year but [this guide](https://learn.adafruit.com/how-to-train-new-tensorflow-lite-micro-speech-models?view=all) has some notes on training new models. Still I'm not sure that this MCU has the oomph for a full voice recognition model.

val-storm, 2021-01-12:
Hey again,

So I've cleared up some project head space and am getting back to Open Book
(and the secret "Last Book" web archive) and I have some questions.

You were out of the Open Book PCB so I decided to use it as an opportunity
to try out this "JLPCB" business that seems to be everywhere right now. The
boards look okay and were insanely cheap (which has to be bad in some
way...). So I have 5 boards and I was gonna eventually build them all or
pass them off as kits to friends... but here is the first question:

There are a few parts which digikey doesn't have in stock and I was
wondering about them...

Battery Connector
Q1
Q2
D2, D3, D4
FB1, FB2

Would an Octo-Part search to find the exact part numbers be wise? I did
some digging and most of them I was able to find comparable parts. For
instance the Battery Connector at a different angle. The one that gave me
some trouble was Q2 I think... I didn't know what was the limiting agent
there as far as specs go. What am I looking for with that one?

Very excited to get one of these built and start moving on the networked
library aspect! Also thinking about making a larger one... but this size is
really great... its like a phone.

Best,

On Tue, Aug 18, 2020 at 7:30 PM joeycastillo <notifications@github.com>
wrote:

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

Closed 2022-12-07.

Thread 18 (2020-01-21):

Great Job!!!. What about of think on linux?

wkrea, 2020-01-21:
First of all I want to congratulate you for an excellent idea and purpose of your work.

In another hand, i think that is a good time for suggest and offer some help to you on this project, for improve oriented to the final user to future.

Really, make a board and desing all firmware it's a great job for engineering and intelectual purposes, but in long way it's very difficult for manteniance and flexibility, in way to give for give more functionalities to ereader.

Have you think about in more storage, conectivity and compatibility?. there are many boards (open hardware) than should be great for supply this requierements, which need more people workning on firmware for eink display.

For not go far with my idea. What if think on some board that support linux and give conectivity on wifi or bluetooth? and only give mode suport for eink displays in very size and resolutions?.

This give to the final user, more flexibility for have an ereader with an app of your preferences for read. More flexibility for us for think on the Ux/Ui and other funcionalities for pluralize the ereaders in low cost and good quality..

Let me know what you think about this point of view, if your purpose is oriented to this or is different?

one more time, great job men. You are a master!!!

torpak, 2020-01-22:
Disclaimer: I have no connection to this project, (other than finding it awesome) and have not talked to the author.
But, it seems to me that one of the goals was keeping the cost per unit managable. Using powerful hardware (as in powerful enough to run Linux) would significantly increase the price tag for small batches.
Also there is something to be said for Simplicity. An ebook reader that only does what is neccessary for it's purpose is a much simpler system, than one that carries a whole operating system with it. Simpler systems have less failure modes and are easier to get right (especially if you have limited manpower).
The last aspect ist battery usage: a powerful system needs a powerful battery, again driving up costs and consuming resources.

ngsctt, 2020-01-22:
There's some discussion about Linux in #10, including the possibility of using the [Giant Board][gb] and some of the limitations of doing it that way (including cost), about how to add WiFi.

[gb]: https://www.crowdsupply.com/groboards/giant-board

joeycastillo, 2020-01-25:
Thanks for the kind words! I've actually ordered a Giant Board with the specific intent of exploring Linux options with the Wing. I also think it could be interesting to engineer something that pairs with a Raspberry Pi or compute module. For all the reasons outined in #10 though — more expensive, less DIY friendly parts, and more expensive manufacturing processes — I think designing a full Linux board is probably out of scope for this project.

Keep in mind that even at scale, many full-featured Linux-based e-readers [are sold at a loss](https://www.pcworld.com/article/243531/report_79_amazon_kindle_costs_84_to_make.html); the companies that sell them make up the difference by stealing your attention with ads and selling DRM-encumbered content. I want to keep the cost low and avoid all that nonsense, which means making some tradeoffs.

Thanks for the suggestion though, and again I encourage anyone with this kind of interest to fork the repository and play with the design; it's all open source :)

grravity, 2020-07-26:
I world really hope for an ability to just rsync my directory which I already have rsynced between my computers, but also just have it rsync to the open book. If this is possible I'd be happy.

GarkGarcia, 2020-09-04:
> I world really hope for an ability to just rsync my directory which I already have rsynced between my computers, but also just have it rsync to the open book. If this is possible I'd be happy.

I believe you can simply mount the microSD (the one used for storing the books) on your machine and rsync the directories from from there.

grravity, 2020-09-08:
> I world really hope for an ability to just rsync my directory which I already have rsynced between my computers, but also just have it rsync to the open book. If this is possible I'd be happy.
>
> I believe you can simply mount the microSD (the one used for storing the books) on your machine and rsync the directories from from there.

The issue with this is, it would not be possible wirelessly. I can easily copy over files if it's mounted.
But that would require hooking up everytime I add new books.
Interfacing with Calibre wirelessly could be another option.
I know it's not the most preferable feature to always have wireless on though.

wa2mze, 2020-11-11:
The hw cost difference between using a RPi Zero (with wifi/bt) and the samd51 feather actually might favor the RPi (would have to mount the RPi 40 pin header to the BOTTOM of the board so it can plug in to the main board).  The software development effort would involve different skill sets than the Arduino based project, a good working knowledge of GDB would help!  But once you go down the Linux rabbit hole the project WILL end up being more of a PDA or Smart Phone, then an ereader, and the eink display would become a liability because of its slow update rate.  Still, Linux will buy you 'free' OGG music file support (I don't think there is an arduino lib for that yet), and free support for most epub formats (free meaning it's already mostly written).
BUT, I don't think that the current SAMD51 based open book is the wrong approach.  You will get lower power drain, longer batter life, and you CAN build the whole thing yourself.  The Linux approach will require using a pre-built CPU module (RPi Zero, RPi compute module, Beagle Bone submini, Giant Board, etc).  There is room for both (and I have a Pi zero I don't know what to do with at the moment), but I'd like to build the Open Book as is stands, though I hope some PDF or EPUB file support will be ported in eventually.

Closed 2022-12-07.

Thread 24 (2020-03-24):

How to configure/compile library for other hardware

michalsok, 2020-03-24:
Hi. I purchased my EPD (4.2") and Adafruit Feather M0 logger (with SD card socket) to build my simple eBook reader. Then, while searching for libraries to simplify my project, I stumbled across your project and was super excited that I don't have to start from nothing.
My setup is simple: EPD and SD on SPI plus MCP23008 for buttons in I2C
I downloaded the folder and modified the OpenBook.h like so:

`#elif defined(ADAFRUIT_FEATHER_M0) // e-book wing on Feather M0
#define OPENBOOK_DISPLAY_BUS (&SPI)
#define OPENBOOK_SRCS (-1)
#define OPENBOOK_ECS (10)
#define OPENBOOK_EDC (9)
#define OPENBOOK_ERST (6)
#define OPENBOOK_EBSY (5)
#define OPENBOOK_SDCS (4)
#define OPENBOOK_BCS (-1)
#define OPENBOOK_BATTERY_MONITOR (A7)
#define OPENBOOK_BUTTON_INTERRUPT (11)
#define OPENBOOK_BUTTON_LATCH (-1)
#define OPENBOOK_BUTTON_DATA (-1)
#define OPENBOOK_BUTTON_CLOCK (-1)
#define OPENBOOK_BUTTON_LOCK (-1)
#define OPENBOOK_BUTTON_ACTIVE (LOW)
#define OPENBOOK_AUDIO_L (-1)
#define OPENBOOK_AUDIO_R (-1)
#define OPENBOOK_MIC_RAW (-1)
#define OPENBOOK_MIC_AMPLIFIED (-1)
`
Disabled the serial RAM as this waveshare 4.2 BW already has one built in
and I also wanted to disable Flash for Babel.
I am assuming that it is the OPENBOOK_BCS (-1) that does it. (Don't have EAGLE so I can't verify)
I am building a simple external PCB with MCP23008 and buttons to handle buttons.
How do I disable Babel support (can it be disabled?)
When compiling I get an error: "BabelTypesetterGFX.h: No such file or directory"
What is causing it?
Could you help me to modify the library setup to work with my simple reader hardware?
Thank you,
Mike.

joeycastillo, 2020-03-25:
Thanks for bringing up this issue, it's something I hadn't gotten to yet. One of my goals has been to make a "lightweight" version of the Babel library that just includes ASCII glyphs in memory, to allow support a consistent method for typesetting even if you don't have the extra chip installed.

For the moment, if you just install the library ([from here](https://github.com/joeycastillo/babel)), it will silence the errors, but I may need to figure out a better way to do this for folks that want to pick and choose specific bits of functionality.

michalsok, 2020-03-26:
Thank you. I will give it a try.

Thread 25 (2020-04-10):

Photo of board without e-ink display

sdas41395, 2020-04-10:
Hey Joey,

Amazing DIY project! Me and my girlfriend stumbled upon this recently while surfing the internet for a e book reader. We're not that versed in reading electrical schematics and were hoping you could also include a photo of the front without the e-ink display so we can match the connections to the drawn schematics to help understand how to do it.

Thank you so much for this cool project and very excited to see how it goes forward!

Thanks,
Shoham

DCelectronics, 2020-10-18:
Hi Shoham,
The following would help you and others to visualize the display connections and understand how to do it.

Quoting Joey here (from issue #32):
"First, make sure that the gray tabs are open. Then as far as fitting the connector, I've found it helps to kind of gently bend the cable in between the connector area and the ground pour before you thread it through the hole; that gives you some leverage to work it in, like so:"
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
And this short clip is from a twitter post by Joey:
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
As the silkscreen states "... Secure the screen to this area with double sided tape; you don't need this documentation anymore."

The typical bending radius of a two layer flexible board (referring to the amber ribbon that comes out of the display) is about 12 times the thickness of the flexible board (which is about 4mils).
Using a very high bonding double sided tape with a thickness of about 50mils (such as 3M Scotch 5952 or equivalent) should be fine to secure the display on the board.

I am thankful that Joey posted these short clips on the internet.

Closed 2022-12-07.

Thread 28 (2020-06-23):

Slightly larger, high resolution display?

Drizzt321, 2020-06-23:
So love, LOOOOOVE this. Will definitely be making one of these, although my trust PRS-T3 is managing to stay alive. Personally I prefer the size of a 6" display, rather than 4.2". I found https://zh-tw.buyepaper.com/6-inch-1024758high-resolution-epd-display-p0096.html except it's 34-pin parallen, so not a drop-in compatible. Is there any info that, in your research, you've found that could be useful to someone wanting to tweak the design to support these slightly larger displays?

I did just find https://www.waveshare.com/wiki/6inch_HD_e-Paper_HAT which uses IT8591 parallel controller for e-ink displays. Wish they would open-source the design and software. I definitely can see it as more of a v2/advanced.

I suppose I could just go straight to https://zh-tw.buyepaper.com/583-inch-high-resolution-648x480-e-paper-display-black-and-white-e-ink-screen-gdew0583t8-p0363.html which is a 5.48" that still uses the same 24-pin SPI FPC, so probably a drop-in other than mounting differences and changing the resolution/size in the code.

joeycastillo, 2020-06-24:
A screen with a parallel interface is something on my radar screen, though the two panels I'm more interested in are either [Good Display's 4.3 inch high resolution panel](https://zh-tw.buyepaper.com/43-inch-low-power-consumption-e-paper-p0093.html) or, more exciting to me, using a recycled Kindle screen like the [Inkplate 6](https://www.crowdsupply.com/e-radionica/inkplate-6) does. The Inkplate folks' Github repository has [some code related to driving that screen](https://github.com/e-radionicacom/Inkplate-6-Arduino-library) that I want to play with, once I get software support for this iteration of the Open Book further along.

Also, note that those panels, to my understanding, do not have an on-board booster, which means you would likely also need to add a PMIC like the [TPS65185](https://www.ti.com/lit/ds/symlink/tps65185.pdf) or [TPS65186](https://www.ti.com/lit/ds/symlink/tps65186.pdf) to generate the higher voltage rails necessary to drive the screen.

As for the 5.83 inch screen, I've tested it with the Open Book (using the [GxEPD2 library](https://github.com/ZinggJM/GxEPD2)), and it "just works"; the same booster circuit and flex connector gets images displaying on the screen. As you say it would involve some dimension tweaks and a larger cutout, but relatively trivial. Having said that, a couple of reasons I don't think it's a great match:

* at $40 per unit, it's at least twice as expensive as [the 4.2 inch screen](https://zh-tw.buyepaper.com/42inch-e-ink-panel-spi-interface-buy-e-paper-display-p0085.html) in small quantities
* slower screen refresh
* no support for partial refresh or grayscale modes

I think it's rad to be looking at larger and higher-res screens, but be careful to watch out for both price and features in addition to panel size and resolution :)

Drizzt321, 2020-06-24:
No, didn't notice the slower refresh and no partial-refresh. Yea, those are big features for e-books. That plus the cost makes that 4.2" far superior.

Hadn't seen that Inkplate 6, very cool. Nice to see that you should be able to re-use some of the same software. A popular quality screen like for a Kindle definitely is useful to have support for. I've got some other projects, but hoping I might be able to join in this winter after I clear some of them off. And get more Arduino dev experience.

seniorm0ment, 2021-04-14:
Any updates on this?
I'm interested in building an Open Book, that being said the small display is a complete deal breaker for me currently. Of course a larger screen would imply a higher cost, that being said having the option is nice.
I think it's important to try to compete with retail readers such as Kobo and Kindle.

An 8" 1440 × 1920 300 PPI display like the one found in the [Kobo Forma](https://us.kobobooks.com/collections/ereaders/products/kobo-forma) is **ideally what I'm looking for**.
If not that, then _at least_ a 6" 1072 x 1448 300 PPI display similar to the one found in the  [Kobo Clara HD](https://us.kobobooks.com/collections/ereaders/products/kobo-clara-hd).

Closed 2022-12-07.

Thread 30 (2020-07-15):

C2 - missing from Feather BOM

chadvavra, 2020-07-15:
https://github.com/joeycastillo/The-Open-Book/blob/master/eBook%20Feather%20Wing/1-click-bom.csv

C2 is not included in the 1 click BOM

joeycastillo, 2020-07-15:
Oh wow, that is an oversight on my part. I'm shocked I didn't catch it. It's supposed to be a 10µF capacitor identical to C1.

Fixed in 27c5aa9; if you bought parts and are one short, I'd suggest leaving C1 unpopulated and putting the 10µF capacitor in C2's spot, though it might work either way. So sorry about that, and thank you for raising the issue!

chadvavra, 2020-07-15:
no problem.  I did end up one short, but my screen is at least a week out and Amazon has cheap sample packs of 0805 caps available via Prime.

Closed 2020-07-15.

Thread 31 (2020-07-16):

Adafruit Feather STM32F405 Express

chadvavra, 2020-07-16:
https://www.adafruit.com/product/4382

Thoughts on using the STM32 instead of M4 Express?

Adafruit tested this board in Arduino [STM32duino](https://github.com/stm32duino) with all their FeatherWings and only the RFM69/RFM9x libraries did not work

STM32F405 Cortex M4 with FPU and 1MB Flash, 168MHz speed

- 192KB RAM total - 128 KB RAM for general usage + 64 KB program-only/cache RAM
- 3.3V logic, but almost all pins are 5V compliant!
- USB C power and data - our first USB C Feather!
- LiPo connector and charger
- **SD socket on the bottom, connected to SDIO port**
- **2 MB SPI Flash chip**
- Built in NeoPixel indicator
- I2C, UART, GPIO, ADCs, DACs

joeycastillo, 2020-07-17:
Initial thoughts are that it should work! Early on I tested the wing with M0 Feathers as well as the the ESP32 Feather, and at the very least the screen test sketch worked as expected. I have had an STM32 Feather here for a while, but haven't had a chance to test it. If you wanted to try, you could more or less copy over [the hardware definition for the M4 Feather](https://github.com/joeycastillo/The-Open-Book/blob/6232c1c80b1a5533d58d1272009904f260bea406/src/OpenBook.h#L67) since almost all the pin numbering is the same.

The only issue I foresee is that the BCS pin, which has a solder jumper to allow it to connect to the M4's 'Extra' pin, would need to be connected to a different pin since the STM32 Feather uses it to enter bootloader mode. If you planned to use the SD socket on the Feather instead of the SD socket on the wing, you could run a wire from the BCS pad to SDCS, and then use pin 5 to select the language chip.

If you try this, definitely let me know in this thread! And either way I'll likely give it a go in the coming weeks.

chadvavra, 2020-07-17:
Will do!  Thanks.  I'm curious about the chip speed and if it makes any difference.Sounds like it might be hard to try both out on the same board though.On Jul 17, 2020 1:59 PM, joeycastillo <notifications@github.com> wrote:
Initial thoughts are that it should work! Early on I tested the wing with M0 Feathers as well as the the ESP32 Feather, and at the very least the screen test sketch worked as expected. I have had an STM32 Feather here for a while, but haven't had a chance to test it. If you wanted to try, you could more or less copy over the hardware definition for the M4 Feather since almost all the pin numbering is the same.
The only issue I foresee is that the BCS pin, which has a solder jumper to allow it to connect to the M4's 'Extra' pin, would need to be connected to a different pin since the STM32 Feather uses it to enter bootloader mode. If you planned to use the SD socket on the Feather instead of the SD socket on the wing, you could run a wire from the BCS pad to SDCS, and then use pin 5 to select the language chip.
If you try this, definitely let me know in this thread! And either way I'll likely give it a go in the coming weeks.

—You are receiving this because you authored the thread.Reply to this email directly, view it on GitHub, or unsubscribe.

joeycastillo, 2020-07-18:
Yea, if you connected the two sides of the BCS solder jumper, like it suggests in the getting started guide for the M4, it'll probably interfere with things since that pin is pulled down on the Feather; the Flash chip will always be selected in addition to whatever device on the bus you're trying to talk to. You can un-bridge the jumper with some solder wick and run a wire, but then it's a solder job every time you want to switch Feather boards. Not ideal.

nerdguy1338, 2020-07-18:
Make that jumper a pushbutton switch instead?

On Fri, Jul 17, 2020, 10:39 PM joeycastillo <notifications@github.com>
wrote:

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

Closed 2022-12-07.

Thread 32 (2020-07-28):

FPC connector insertion is pretty hard

justinBR, 2020-07-28:
Hi,
Great project! I've been having a really hard time getting the flex cable from the pcb into the FPC connector. I used the fpc connector from the BOM, not the one the that came with the display (I didn't have it when I assembled the board). I can only get it to insert if I push it in from an angle > 30 degrees. because the cable is so short, it does not seem possible to get the cable to this angle when it is threaded through the hole in the PCB. Is there some trick to getting it to insert, or do I need to remove the connector and replace it?

this is on the A1-05 revision.

justinBR, 2020-07-28:
it is doable, just hard. sorry for raising an issue for such a goofy thing.

joeycastillo, 2020-07-28:
No worries, not goofy at all! It's a bit fiddly, for sure, and I should have anticipated that it would be a friction point. First, make sure that the gray tabs are open. Then as far as fitting the connector, I've found it helps to kind of gently bend the cable in between the connector area and the ground pour before you thread it through the hole; that gives you some leverage to work it in, like so:

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

A little bend like this shouldn't damage the flex cable, especially since once it's in, you aren't going to be flexing and unflexing it repeatedly. And then make sure to close the gray tabs once it's in place.

For anyone else using the Good Display connector, the method is the same except that instead of gray tabs it has a black lever on the opposite side from the cable; that lever needs to be flipped up for insertion, and pushed down once the cable is in place.

Closed 2020-07-28.

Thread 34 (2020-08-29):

Testing out an interactive assembly guide on kitspace

kasbah, 2020-08-29:
Hey, we are testing out the interactive assembly guide for Eagle projects on https://github.com/kitspace/kitspace/pull/300 (by converting to KiCad and using the Interactive HTML BOM plugin for that)

Here's what it will look like:

- [Open-Book](http://eagle-ibom.preview.kitspace.org/interactive_bom/?github.com/joeycastillo/The-Open-Book/Open-Book)
- [eBook-Wing](http://eagle-ibom.preview.kitspace.org/interactive_bom/?github.com/joeycastillo/The-Open-Book/eBook-Wing)

This look good to you? Do you see any issues?

joeycastillo, 2020-09-04:
It looks great! One thing is that there are some board features (fiducials, logos) that don't have a part associated with them, but still appear in the list. If there's a way for me to tag them to be excluded, I'd love to do that to make it clearer to folks.

kasbah, 2020-09-05:
Great, we are just trying to improve the silkscreen text placement before we put this up on the main site.

Regarding excluding components, I am not sure. In KiCad you can mark components as "virtual" to exclude them manufacturing outputs. Is there an equivalent for Eagle?

kasbah, 2020-10-15:
It's live now!

https://kitspace.org/interactive_bom/?github.com/joeycastillo/The-Open-Book/eBook-Wing

and

https://kitspace.org/interactive_bom/?github.com/joeycastillo/The-Open-Book/Open-Book

Closed 2020-10-15.

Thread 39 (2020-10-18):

I Cannot Find Directions

darlingtom, 2020-10-18:
I am probably completely missing the link, so please point me in the right direction.

I do a minor amount of DIY but really enjoy it.  I need basics, though, like a list of parts to buy and step-by-step assembly.  If this exists, please point me in the right direction.

I'd like to make one and, if successful, make a few more with middle school students for the classroom.  Any help is appreciated.

DCelectronics, 2020-10-18:
I am glad to hear that you would like to make one.

 Depending on your soldering skills, you have to decide if you are going to build the Open Book Feather or the E-Book FeatherWing.

Most of the parts are wide-pitch components, but there are a few fine-pitched components including the flex connector and two chips (ATSAMD51 and the MAX4468 mic preamp). For a simpler build, the E-Book FeatherWing has fewer fine-pitched parts (flex connector), but it requires a [Feather M4](https://www.adafruit.com/product/3857) to function. Below are the choices for ordering boards and parts:

### Open Book Feather A1 Rev 05
[Purchase the Open Book board on Tindie](https://www.tindie.com/products/20599/)
The Open Book bill of materials is [available on Kitspace](https://kitspace.org/boards/github.com/joeycastillo/the-open-book/open-book/).

### E-Book FeatherWing A1 Rev 05
[Purchase the E-Book FeatherWing board on Tindie](https://www.tindie.com/products/19994/)
The E-Book Wing bill of materials is also [available on Kitspace](https://kitspace.org/boards/github.com/joeycastillo/the-open-book/ebook-wing/).

If the board of your interest is not available on Tindie, you can order boards conveniently through one of the three suppliers listed on Kitspace (AISLER, PCBWay and OSHPARK), or download the Gerber files and use the any other board manufacturer of your choice. If you reside in the United States, AISLER also manufactures boards in the [USA](https://aisler.net/blog/aisler-loves-us-manufacturing) with a 2 day lead time for three prototype boards, which thankfully are not purple, and for almost half of what OSHPARK charges for these boards.

Kitspace has choices for parts suppliers (Digikey, Mouser, RS, and Farnel) and makes a shopping cart for you.
Sometimes, individual parts may be out of stock, and you may have to select alternative part from what is listed in the bill of materials. It is OK to substitute parts with their equivalents.

That last part is the e-paper display. You will need to order it from [Good Display](https://zh-tw.buyepaper.com/42inch-e-ink-panel-spi-interface-buy-e-paper-display-p0085.html). It ships from overseas though so expect to wait a few weeks. If Good Display is sold out, you can also get the same display from [Waveshare](https://www.waveshare.com/4.2inch-e-paper.htm) for a few bucks more.

### Setup Guide and Documentation
[Setup guide for the E-Book Wing](https://github.com/joeycastillo/The-Open-Book/wiki/E-Book-Wing-Setup-Guide)
[Setup guide and documentation for the Open Book](https://github.com/joeycastillo/The-Open-Book/wiki/Open-Book-Documentation)
[Open Book documentation (PDF)](https://github.com/joeycastillo/The-Open-Book/blob/master/Open%20Book%20Feather/Documentation%20Packet/open-book-printout.pdf)

I hope this response helps you with getting started.

joeycastillo, 2020-10-19:
Thanks @DCelectronics for this response! I'd also add that when I send out the boards from Tindie, I include a documentation packet for each board that includes a blown-up version of the silkscreen, a printed BOM and the booklet that was linked above. All the printouts are available in the folder with the PCB design files: [Open Book documentation packet](https://github.com/joeycastillo/The-Open-Book/tree/master/Open%20Book%20Feather/Documentation%20Packet) and [E-Book Wing documentation packet](https://github.com/joeycastillo/The-Open-Book/tree/master/eBook%20Feather%20Wing/Documentation%20Packet).

In addition, I just added [a 25-minute video demonstrating the build process for the E-Book FeatherWing](https://youtu.be/0Bsh1q2tqaU), which I'll be adding to the README momentarily. This covers hand-assembly, as opposed to using a stencil and solder paste, but this is how I imagine most people will want to assemble the wing.

Currently no matching video is available for the Open Book, but I think that if you were looking for something to build in a classroom setting, the E-Book Wing is the better board to build (the Open Book has more parts, and a couple are a bit more finicky).

Closed 2022-12-07.

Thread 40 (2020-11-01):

Adafruit Compatible Stackable Header for the Feather to the FeatherWing Wifi is too thin and falls out of the eBook Wing's Header

lvw5264, 2020-11-01:
In the BOM, the Top feather header and Bottom Feather header are used to allow the Feather to stack solderlessly on top of the eBook Wing, breadboard style. I would have used the cheaper option of just cutting a Raspberry Pi header in half but I didn't want to risk that.

The feather comes with standard male break away header that is square so it fits snug in the breadboard style header on the eBook Wing. However, these would not allow the FeatherWing wifi to stack on top. Just like these:

https://www.adafruit.com/product/3002

So Adafruit provides a $1 thin pin stackable female header set commonly used in the Arduino for the header to connect to other boards, which is of course, able to stack to thin pin stackable female headers like itself just fine.

https://www.adafruit.com/product/2830

Unfortunately, these thin pin stackable female headers are too thin compared to the standard male break away header, and easily fall out of the breadboard style one on the eBook Wing, so I could not use them for the purpose of stacking the FeatherWing Wifi chip atop it. Observe the example shown in this product guide to witness the clear difference between the stackable female header Adafruit uses, vs one using square pins just like the standard male break away header:

https://www.rugged-circuits.com/components/8-pin-stacking-header

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

https://www.rugged-circuits.com/components/6-pin-stacking-header

(buying 2 of the 8 pin and 2 of the 6 pin female stacking header would solve this issue)

How did you stack the FeatherWing Wifi chip atop, and with what stackable female headers? Do I have to buy those square ones as above and not flat? it seems to be harder to find, and if so needs to be noted in the guide.

An alternative cheap option is to use longer square male header, and then solder the thin pin female stackable header (or a non stackable header if its the last in the stack) to the *bottom* of the FeatherWing instead of the top of the feather. Of course this means that the header is now in an unusual nonstandard reversed position, but at least Adafruit doesn't solder down the headers so it could work. Did you do that?

https://www.adafruit.com/product/400

joeycastillo, 2020-11-01:
I used the same stacking Feather headers from Adafruit, product 2830, and I have not experienced an issue with the pins being that loose when paired with the headers in the BOM. Can you post a photo of the headers you are using? The ones I have here look like this, and they do fit securely and stay put even when inverted or shaken.

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

lvw5264, 2020-11-04:
I made a video of how the thin pin female stackable header from Adafruit onto the white socket of the BOM just doesn't make a good electrical connection and easily falls out, but I tried to find somewhere convenient to upload it, but I couldn't find it. No clue how yours fits snugly.

I guess the answer is clear to me anyway, I have to use those thicker square female stackable headers as linked above. Do look into it, I'm sure there must be a female stackable header that is properly square on digikey to recommend for the wifi FeatherWIng instead.

joeycastillo, 2020-11-04:
Thanks for the suggestion and I appreciate the report; will definitely search Digikey and see what I can find. Also plan to order some more stacking Feather headers from Adafruit to see if I can reproduce the issue.

DCelectronics, 2020-11-09:
@lvw5264, If you used the BOM parts: Amphenol ICC / FCI 89898-312LF and 89898-316LF, they do not have the typical fork orientation and retention mechanism, and the budget Adafruit headers are too thin for these sockets (the male portion of the stackable Adafruit headers do not have square cross section area).
The following pictures may help you visualize how the socket engages with the header pins.
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
These two parts should adders the issue.
https://www.samtec.com/products/ssq-112-03-f-s
https://www.samtec.com/products/ssq-116-03-f-s
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

Closed 2022-12-07.

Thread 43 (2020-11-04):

Book title and text not showing in MVBook

jxw5883, 2020-11-04:
I'm having this problem where text does not show in MVBook but it does on Quotes demo. It seems that text rendering is not working on menu.h and readbook.h.

I'm using a Feather M4 Express on the E-Book Feather Wing.

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

joeycastillo, 2020-11-04:
That's very odd. Can you confirm that you are using the latest version of both the Babel library and the OpenBook library? And that the BCS solder jumper is closed (I assume it is since it worked with the quotes demo, but just in case).

[Open Book](https://github.com/joeycastillo/The-Open-Book)

[Babel](https://github.com/joeycastillo/babel)

joeycastillo, 2020-11-09:
@jxw5883 Scratch that — I am able to replicate this issue after updating to the latest version of the Adafruiit_EPD library. It appears to be an issue or incompatibility introduced in version 4.0.0 of the library, though I am unsure as yet whether the problem is in my code or theirs. Either way, I am investigating further and hope to be able to identify a fix shortly.

For now though, you can address this issue by installing version 3.0.0 of the Adafruit_EPD library in the Arduino Library Manager. This should allow text to once again appear in the MVBook menu and book reading UI.

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

joeycastillo, 2020-11-09:
Got it! It was my bug, fixed in commit b0cbc02. Adafruit_EPD 4.0.0 swapped the order of the white and black colors in their color enum. In MVBook, I had neglected to set the typesetter's text color; this had not caused issues in the past, since its default text color of 0 always corresponded to EPD_BLACK. Now that 0 corresponds to EPD_WHITE, the typesetter was rendering white text on a white background.

Commit b0cbc02 updates MVBook to set the typesetter's text color before rendering either menu text or book text. This fixes the issue.

jxw5883, 2020-11-09:
I can confirm this fixed it. Thanks!

Closed 2020-11-09.

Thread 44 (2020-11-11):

Open Book vs Open Book Feather wing

wa2mze, 2020-11-11:
I just ordered two displays ("First rule of government spending, why buy one when you can have two at twice the price?"), couldn't justify spending as much on the shipping as the hardware, the second display was $1 cheaper and free shipping (sorta).  I will order a board once I figure out which one (might get both, see above rule :-) ).
Questions:
1:  Why does the "wing board" have an added serial RAM chip that the "full" board does not?
2: Can I use the SAMD51J20 (twice the memory) instead of the 'J19? (I've got two of them in my parts bin).
3: Will there be a new hardware spin on either board soon (like to add that 'missing' ram chip to the "full" board)?
My SMT solder skills are probably up to the task, I've soldered 0.5mm QFTPs many times with good results.  The first time I tried to use paste, a stencil and hot air it was a disaster! (couldn't remove solder bridges UNDER the legs, removed the chip and lost it when it fell on the floor!).  I'll stick with drag soldering by hand and have wick handy!

joeycastillo, 2020-11-12:
1. The wing has the SRAM chip, at least in theory, for pairing with Feathers with less RAM (like the old school ATmega32u4 Feathers). It's actually not currently used by the Open Book software library, because the SAMD51 has enough RAM to buffer the whole display (and the SRAM chip doesn't seem to play nicely with some of the partial update stuff I'm doing).

2. You should be able to use the SAMD51J20 as it is pin compatible, but you might need to hack around with the software support libraries. The Arduino library specifies the SAMD51J19 in the board definition, and has Flash sizes tailored to that chip. The CircuitPython build also specifies the SAMD51J19, but I don't think you'd get any benefit there as the CircuitPython runtime fits comfortably in 512 KB; all your user code will live on the 2MB Flash chip anyway.

3. I'm not planning a new revision of either board anytime soon, and in particular there is no plan to add the SRAM chip to the Open Book, since the SAMD51 has enough RAM for the screen. The only reason I would consider another revision to the E-Book Wing is that it uses a different style of button for lock and reset than the Open Book, but I'm hesitant to make yet another revision at this time (and both kinds of button work just fine).

DCelectronics, 2020-11-27:
@wa2mze These are great questions.

1. I had the same question during the design conversion to KiCad, but I figured some of the parts can be optionally installed/populated on the board, depending on the desired features (such as connectors for peripherals, QSPI Flash, etc). For example, if you don't care for CircuitPython, you can probably skip installing the QSPI Flash chip on the board.

2. For SAMD51J20, you may consider looking at the libraries developed for [Sparkfun DEV-14713](https://www.sparkfun.com/products/14713) and modify the Arduino SAMD core for the Oddly Specific Objects. One thing with the Open Book Featherwing is that you are not limited to the Adafruit products. You can use the [Sparkfun DEV-14713](https://www.sparkfun.com/products/14713), or get the [Teensy 3.x Feather Adapter](https://www.adafruit.com/product/3200) and try out the [Teensy 4.0](https://www.pjrc.com/store/teensy40.html), which is almost 11 times faster than the SAMD51J19, and that would _ruffle a lot of feathers_.

3. I am thinking of making a variant board. There is plenty of space on the board to add optional features such as RTC (DS3231), WIFI (ESP32), accelerometer, etc. By the way RTC is possible on the Feather M4 Express. Here is the [library](https://github.com/ericbaril72/RTCZero/tree/SAMD51_E54/src) that supports SAMD51 WITH CRYSTAL. If you get issues that the library is old just install the latest from Arduino library manager (current version 1.6.0) and overwrite only the [RTCZero.cpp](https://github.com/ericbaril72/RTCZero/blob/SAMD51_E54/src/RTCZero.cpp). I tried this on the Feather M4, Metro M4, and Grand Central M4, and it worked on all three different boards. This modified library did not work on ItsyBitsy M4 because it is crystal-less. Similarly, I am not expecting this library to work on the Open Book (because it is crystal-less too). It may be possible to add support for crystal-less SAMD51 (SAMD21 crystal-less is supported). So, why bother with separate RTC chip if the SAMD51 can do that? Well the  DS3231is super accurate clock with temperature compensated encapsulated crystal.

wa2mze, 2020-11-29:
I hadn't thought about the 'other' feathers that could be used with the Open Book Feather Wing version.  Adafruit has an STM32F405 board with 1mb flash and 192kb ram, TWO D/A converters (Stereo audio), and a micro SD socket.  Then there is also the ESP32 with BT and WiFi built in.  Rewiring the headphone socket would be required to use the second D/A, don't know if that would be possible.  Can the software support the on board SD socket (eliminating the need to solder one onto the board)?

DCelectronics, 2020-11-30:
@wa2mze I think you can use the STM32F405 on board micro SD socket. I suggest you read issue #31.
I also recommand to give it a try to solder the microSD socket onto the board if you have a fine tip soldering iron (watch this [video](https://youtu.be/0Bsh1q2tqaU?t=878) to see how Joey is doing it). After watching the video, I concluded that soldering the micro SD is not as hard as I originally thought.

wa2mze, 2020-11-30:
I've watched the video.  It doesn't look too bad soldering the SD socket, assuming you have the 'right' socket.  The one Adafruit sells has the card detect pin, but I don't know if the access holes match the one in the video.  I've read #31, sounds like a jumper will be required.  It looks like I can wire the A1 pin to the headphone jack for stereo, but will have to 'dead bug' a second attenuator network for the extra channel.  I would leave out the connectors for A1 and A2 and only attach the external I2C connector (well MAYBE A2 if I can attach a microphone to that).   The Teensy 4.1 also looks interesting.  While longer than the 4.0, it might work on the Feather adapter if the pinout for the 4.0 portion is compatible.  The 4.1 has a FULL micro SD socket connection, not just a simple SPI, and Teensduino has a library that supports it.
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
wa2mze, 2020-12-16:
So I just ordered the parts to build the OpenBook Featherwing.  I'll leave the OpenBook with on board processor for later.  Adafruit had the SMT feather connectors.  I also ordered their "triple-ler" wing adapter which can be added later to add other wings (like for wifi).  I have three possible feather CPU's, the SAMD51, the ST32F405, and the ESP32.  (and now there is a SAME51 too, but I don't think the CAN bus would add much here).  I'll probably try configuring the software for all three of these and see which works best.

joeycastillo, 2020-12-16:
FYI, there was an error on the BOM for the wing... wrong MicroSD slot per conversation in #47. I thought I committed this change the other night but [here's the diff](https://github.com/joeycastillo/The-Open-Book/commit/12a805342cbac59305abd619eb2bfacb47c4c757) and the [correct part on DigiKey](https://www.digikey.com/en/products/detail/würth-elektronik/693071010811/3124583). You can also use [this part from Adafruit](https://www.adafruit.com/product/1660); the footprint is identical for both.

wa2mze, 2020-12-16:
I ordered the Micro SD socket from Adafruit, so I think I'm good here.

wa2mze, 2020-12-16:
I like the idea of the ESP32 based board.   That CPU module will also be easier to solder than a QFTP-64!

DCelectronics, 2020-12-17:
@wa2mze I got (for another application) a SAME51, unfortunately form Adafruit, and I discovered that it is lacking support. So, I am trying to use this [library](https://github.com/Longan-Labs/CANBed_M4_Arduino_Lib) for this [product](https://www.longan-labs.cc/1030013.html), but I still have to adjust a few things.
As far as the ESP32 module being soldered directly on the PCB, "Soldering Pad 39 to the Ground is not necessary for a satisfactory thermal performance." is a nice note on the [datasheet](https://www.mouser.com/datasheet/2/891/esp32-wroom-32d_esp32-wroom-32u_datasheet_en-1365844.pdf).
I don't have a reflow oven, yet, and I had this idea, to place a through hole at the center of pad 39, and melt the solder in the hole from the back side with the soldering iron. It this case, I don't have to solder the ESP32 pad 39.

wa2mze, 2020-12-21:
Adafruit order arrived this morning.  So I should now have all the parts required for the OpenBook Featherwing.  Guess I'll start assembly with the small SMD parts (resistors, capacitors, transistors), and then move on to the more challenging ones (IC's and connectors).

That ESP32 module has 3 or 4 edge pads connected to the same "ground" as pad 39, so the bottom pad isn't needed for power and signal ground common.  Since it doesn't seem to be needed for heat sinking, I guess you can just ignore it, if your board can provide good enough shielding via ground pours.

joeycastillo, 2020-12-21:
> I don't have a reflow oven, yet, and I had this idea, to place a through hole at the center of pad 39, and melt the solder in the hole from the back side with the soldering iron. It this case, I don't have to solder the ESP32 pad 39.

I didn’t see that note, but FWIW, I had success putting some low temperature Maker Paste on the pad, and blowing hot air on the vias from below. In the future, though, I may not bother if it’s not strictly necessary.

wa2mze, 2020-12-21:
I just looked at the pinout diagram for the module and noted the other ground connections.  Since they all have the same netname, I expect them to be all tied together.
Putting a via hole connected to ground directly under the pad and then just melting solder into the hole from the back side of the PCB with a small soldering ion tip should work fine.  Same for solder paste and hot air.  Smear a bit of flux on the back of the module before attaching it to the PCB.  I've attached the bottom contact of an AD9951 to a PC board that way (soldering iron), it works.  If you are paranoid, you could also stick a small bit of wire in the hole to insure electrical contact with the chip pad.  I suspect that pad is mostly for mechanical hold.

DCelectronics, 2020-12-22:
> I didn’t see that note, but FWIW, I had success putting some low temperature Maker Paste on the pad, and blowing hot air on the vias from below. In the future, though, I may not bother if it’s not strictly necessary.

@joeycastillo I am sorry for not providing more details. It is on page 16 of the [datasheet](https://www.mouser.com/datasheet/2/891/esp32-wroom-32d_esp32-wroom-32u_datasheet_en-1365844.pdf) (or page 21 of 28).

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

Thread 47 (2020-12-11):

Incorrect FPC Connector P/N for the ePaper

DCelectronics, 2020-12-11:
The FPC (flexible printed circuit) connector specified in the BOM (for connecting the ePaper flexible cable) is [Amphenol-ICC P/N: SFV24R-4STBE1HLF](https://www.amphenol-icc.com/fpc-ffc-sfv24r4stbe1hlf.html).
According to the [application specification](https://cdn.amphenol-icc.com/media/wysiwyg/files/documentation/bjm-sfv102.pdf) (see page 3), the selected connector is designed for use with FPCs that have cut-out sections.
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
These are some [connecotrs](https://www.digikey.com/en/products/filter/ffc-fpc-flat-flexible-connectors/399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) that could work with the ePaper FPC, but further verification of the footprint is required before selecting one.
The FPC connector supplied with the ePaper screen by [Good Display](https://zh-tw.buyepaper.com/42inch-e-ink-panel-spi-interface-buy-e-paper-display-p0085.html) appears to be an [Omron P/N: XF3M-2425-1B](https://www.mouser.com/ProductDetail/Omron-Electronics/XF3M-2425-1B?qs=vLWxofP3U2xSl4%2FL5wv8NQ%3D%3D)

joeycastillo, 2020-12-12:
Oh wow. This is completely correct, and a mistake that dates back to the first boards I made. I had noticed the tight fit, but since all the contacts worked, and I didn't know any better way back then, it remained on the BOM with a note suggesting to use the one Good Display included.

The good news is that the connector in the BOM is functional, though it sort of bends the flex connector on either side. Once the display is taped down though, I have had no issues with the performance of the screen.

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

I will order some of the connectors in the search you provided and make an update to the BOM next week.

DCelectronics, 2020-12-13:
The FPC is about 12mils (0.30mm), or the thickness of three sheets of a typical printer paper, and it gets wedged there (thus the tight fit).

Attached is a zip file with screenshots of some FPC connectors that I could find their 3D model for checking them on the footprint. Couple of the connectors (0524352471 and SFV24R-2STBE1HLF) have their supporting tabs partially landing outside the area of the footprint pads. The rest seem OK. The filenames in the zip file match the manufacturer part number.
[FPC_Connectors.zip](https://github.com/joeycastillo/The-Open-Book/files/5684204/FPC_Connectors.zip)

A separate issue with the BOM is that the micro SD part number for the eBook Wing is [Molex 5025700893](https://www.digikey.com/en/products/detail/molex/5025700893/1866792) and it should have been [Würth Elektronik 693071010811](https://www.digikey.com/en/products/detail/w%C3%BCrth-elektronik/693071010811/3124583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) or [Molex 0473340001](https://www.digikey.com/en/products/detail/molex/0473340001/2404955?s=N4IgTCBcDaIOoFkDMYAcqAiBpASgWgDkMQBdAXyA). The [Molex 5025700893](https://www.digikey.com/en/products/detail/molex/5025700893/1866792) may work, but I don't know this for sure.

joeycastillo, 2020-12-13:
> A separate issue with the BOM is that the micro SD part number for the eBook Wing is Molex 5025700893 and it should have been Würth Elektronik 693071010811 or Molex 0473340001. The Molex 5025700893 may work, but I don't know this for sure.

Oh no, that is completely wrong. A few months ago I ordered several microSD connectors to check compatibility, and that one specifically had a footprint that didn't match. My intent was to list the Würth Elektronik part for both devices; I don't know how I got the wires crossed but will fix it now.

DCelectronics, 2020-12-17:
@joeycastillo @kasbah How can we update the [BOM changes](https://github.com/joeycastillo/The-Open-Book/commit/12a805342cbac59305abd619eb2bfacb47c4c757) on the [Kitspace](https://kitspace.org/boards/github.com/joeycastillo/the-open-book/ebook-wing/)?
@joeycastillo Joey, did you have a chance to look at the [FPC_Connectors.zip](https://github.com/joeycastillo/The-Open-Book/files/5684204/FPC_Connectors.zip) I posted for the FPC connector?
Except Molex 0524352471, all others ate good choices. My favourite choices are the [Hirose FH12A-24S-0.5SH(55)](https://www.digikey.com/en/products/detail/hirose-electric-co-ltd/FH12A-24S-0-5SH-55/966386) and [Omron XF3M-2425-1B](https://www.mouser.com/ProductDetail/Omron-Electronics/XF3M-2425-1B?qs=vLWxofP3U2xSl4%2FL5wv8NQ%3D%3D).

joeycastillo, 2020-12-17:
I think that Kitspace automatically updated; I'm seeing the Würth Elektronik card slot listed there now.

I did look at the zip file, and I was hoping to order some of these parts just to see how they fit with the screen and the footprint before updating, but if you feel certain that these parts will work, perhaps it's worth updating it now. Between the two I would lean towards the Hirose connector, just because it's the one that's available on Digikey and it makes Digikey a one-stop cart for everything except the display.

DCelectronics, 2020-12-17:
I guess there was a time delay in updating the Kitspace when I looked. Great! The SD socket issue is resolved.

I agree that the Hirose FH12A-24S-0.5SH(55) connector is available on both [Digikey](https://www.digikey.com/en/products/detail/hirose-electric-co-ltd/FH12A-24S-0-5SH-55/966386) and [Mouser](https://www.mouser.com/ProductDetail/Hirose-Connector/FH12A-24S-05SH55/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).

I looked at the connector datasheet, the e-paper screen datasheet and the connector footprint in the KiCad files. I concluded that the Hirose FH12A-24S-0.5SH(55) connector is suitable for the epaper screen FPC, and the connector footprint in the KiCad files meets (bounds) the specifications found on the connector datasheet. You can independently check that, and proceed with this part number.

These part numbers: SFV24R-2STBE1HLF, F32Q-1A7H1-11024, and 0545502471 are also available on both Digikey and Mouser, but the footprint recommendations (for their support pads) I found on their datasheets are not met in the existing layout footprint for the connector - these parts would work, but not optimally.

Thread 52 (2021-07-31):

Dual Display Support

xambu, 2021-07-31:
E-Ink book readers have all been single display. Kind of makes sense because a button press can shift the page. But there is something comforting about two pages. I think a PCB (think two) that can be connected together with fewer components on one of the PCB's will be give this reader a very good unique selling point. The design can be made such that there is an additional ribbon cable (optional) that connects both the PCB's (which are the same as for a single PCB design). When the ribbon is in use, one of the boards with the CPU can handle both the displays. Additionally, the two screens when the books is closed protect each other. So the design change won't increase the cost of the PCB or BOM for the single display model while allowing for the dual display to be made. Seeing two pages can also be useful for students who are doing research and want to read two different thing at the same time. For example, problem and solution.

gustavklopp, 2022-08-13:
The first step is to have a mono display already working (with note taking available). I think assembling the mono display is already quite a challenge.

Closed 2022-12-07.

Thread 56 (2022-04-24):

Dead project?

mcmurphy8097234789, 2022-04-24:
This project has not seen a commit since 2021. Is the project dead? I hope not, it's really cool

nerdguy1338, 2022-04-24:
It's only been a year.

The world's a little crazy right now, give it time he'll come back.

On Sun, Apr 24, 2022, 7:17 PM mcmurphy8097234789 ***@***.***>
wrote:

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

joeycastillo, 2022-04-25:
TL;DR: Not dead. First version had issues as it was my first real electronics project, and last year I chose to focus on simpler projects that could teach me lessons that will serve the book well when I return to it. (also chip shortage has been hard)

It's funny you opened this issue this weekend: I actually spent some time on Friday assembling the ESP32-S2 version of the Open Book (`OSO-BOOK-B1-01`). It's still a project I want to see to completion. But the Open Book that I designed in 2020 was essentially the first electronic gadget I'd designed, and as such it suffered from several issues. First, it's way too complex and has far too many parts. This makes the BOM cost exorbitant, to the point that I'd never be able to manufacture it affordably. I also neglected to include a keepout area for a reasonably sized battery. To make matters worse I also didn't understand low power design, so the book's quiescent current draw was too high to achieve weeks-long battery life on the battery that did fit there. That's to say nothing of the firmware: it's an Arduino sketch, which is a shaky foundation that doesn't lend itself well to community contributions.

These are just a few of the issues, but the common thread to all of them is that I didn't know any better when I started, and I learned these lessons over time. At many points I've come up with changes that could make the Open Book a better gadget; you can check out [these notes](https://twitter.com/josecastillo/status/1375901032660733952) for an example of where my thinking was at this time last year. Still: even at that time I knew there were lessons I still had to learn, especially around manufacturing at a larger scale and delivering firmware that a community can build on, and I knew that even these slimmed down versions were too complex to be the gadgets I cut my teeth on. (there were also shortages of everything from chips to glass for the e-paper display)

ANYWAY. I made a decision last year to focus instead on learning these lessons by building and manufacturing [Sensor Watch](https://github.com/joeycastillo/Sensor-Watch), and I think I'm doing well: I'm figuring out how to do more with fewer parts, really dialing in my understanding of low power design, and building a community firmware that folks are already contributing to. These are all lessons that are going to make the Open Book better when I return to it. Alas, every path one chooses to walk involves choosing not to walk down another, at least for a time.

micnolmad, 2022-07-13:
Thank you for the info. Just found this project and was so hyped and then not when it was "dead".. Glad to hear it is not.
Are you doing everything your self or do you have help? Because I am as many others also a tinkerer and have many projects that are very not complet simply down to the fact that these kinds of workloads are usually too much for one person.. at least it is for me having a family also.

TLDR; Get people to help you :)

Closed 2022-12-07.

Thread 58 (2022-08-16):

I wanted to build one but when i try to order the components it is written that they are retired?

TrueGorOn, 2022-08-16:
I am in need of an ebook reader. I don't want to buy a kindle or that sort. This project is really interesting. So wanted to give it a go. But when i visited the site that are linked here, for the components, it is written that they are retired. I am very sad to see the end of this project. Hoping someday it will come back. So any idea when the board and other components will be available for purchase?

joeycastillo, 2022-08-20:
I'm working on a new board based around the Raspberry Pi Pico even as we speak. it's been a challenging couple of years for making things; the world of early 2020, when you could dream up a design and have the chips within a week, feels far away now, and a project with a BOM the size of the original Open Book's seems a lavish indulgence.

the Pi Pico book will be much simpler and take rechargeable AAA batteries, so it may not be as svelte as the original. but in using the Pi Pico, it gets the BOM down to just over a dozen parts, all widely available. I've been [refining the design](https://twitter.com/josecastillo/status/1549123078411751425) and I hope to have it published later this summer, with at least a few kits available before the year is out. With it will come a complete overhaul of the firmware, which frankly will require some community support to get it over the finish line.

It's more of a project reset: same goals, same form factor and many of the same parts, but starting fresh and incorporating all of the lessons learned over the last two years and change. Once I get there, I plan to archive the old repo in a branch and close all the old issues with an message making clear the new direction; if you remain subscribed to this issue, you'll hear about it as soon as we're ready to make moves.

Closed 2022-12-07.

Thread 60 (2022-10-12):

About The battery

luka177, 2022-10-12:
I am willing to add li-ion/li-po BMS to this board, but have few concerns, firstly modern lithium batteries are no joke, so it should be done the right way. We need to add at least 2 ics, one for charging (possibly MCP73831 or BQ24040) and one to protect battery from over-discharge (MIC2776?). But that would add a lot components to solder, we may do universol board so one have to solder either aaa battery bay or lithium stuff. What do you think?

thargas, 2022-10-12:
Personally, I'd prefer to lose the AA thickness. I'm unsure how a universal
board avoids having to solder the lithium components, but I'm in favor of
minimizing the soldering as this would be my first of any kind. I'm
thinking maybe I should pick up the iron fist and get some practice.

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

luka177, 2022-10-12:
No no you got me wrong. You SHOULD NEVER EVER solder liion. Just dont. battery will be connected with some king of connector and glueed with double sided tape. But you will need more soldering to actually solder components needed to charge that battery properly (so no fire and explosions :D)

thargas, 2022-10-12:
Thanks for the elaboration and warning. I was meaning soldering the components needed for adding lithium batteries, not the batteries, but best to make sure I'm not about to do something stupid. :-)

joeycastillo, 2022-10-12:
You should feel free to do it! But a word of warning, I’m unlikely to want to merge in such a design. I have an idea of several other changes I’d like to make to realize a lipo powered version, and it will likely end up being a fairly different gadget.

It’s open source hardware so you can absolutely do this in a fork and I think it would be rad! But when it comes to the designs in this repository, I do have a particular vision in mind (even if it’s something I may not be able to get to until the first half of 2023).

Closed 2022-10-12.

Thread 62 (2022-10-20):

Cheap PCBA Castellated EPD Driver Module

dronesflier, 2022-10-20:
Hello,
I've come across this project, and decided to try my hand at it. My plan is to build the [reboot](https://github.com/joeycastillo/The-Open-Book/tree/reboot) version, and this requires the Castellated EPD Driver Module to be assembled with PCBA.
Here's my issue: this is really expensive. Even after applying coupons, the board is around 35-40$ at JLCPCB. The main problem is that JLCPCB charges a bit for the PCBA setup fee (9 bucks) and then around 1 euro per solder joint that needs to be done by hand (which, for some reason, is a lot of them).
Does anybody have any tips on getting the price down, and if not, how difficult is this to hand-solder? I've got a bit of experience with soldering SMDs, but I'm nowhere near an expert.

dronesflier, 2022-11-04:
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
Yes, it's possible and not very hard! Closing issue

Closed 2022-11-04.

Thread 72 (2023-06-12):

Boards dimensions to order at JLCPCB?

rodrirochad, 2023-06-12:
First time ordering a PCB service here. Sorry for the dumb question.

I have uploaded the .zip file as indicated in the "State of the Book" section, set to 1 mm and two-layer PCB, but I have no idea what to put in the board dimension field.
Where can I find the board dimension?

Thank you!

besselfunct, 2023-06-12:
By my measurements, the board is 85mm x 115mm, but you should check with your specific Gerber files.

If you have KiCAD, then you can open it up, and then use the "Gerber Viewer" app, and then open the "Edge Cuts" file. Set the scale to something like 1.0mm/div or 0.5mm/div, and then use the measure tool to get the board dimensions. There may be an easier way, but that's what I used.

rodrirochad, 2023-06-13:
Thank you for the help!
I have tried to upload the gerber files again and now it is catching the board dimensions automatically. I don't know what was happening before.

Though, I confirm that the main board is 85 mm x 115 mm and the Castellated E-Paper Driver is about 17 mm x 24 mm

Closed 2023-06-13.

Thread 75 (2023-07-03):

Fail flashing babel.bin

rodrirochad, 2023-07-03:
I have just built The-Open-Book and I am really excited that right in the first try I see things appearing on the screen. However, it seems that I have a problem flashing the language data (babel.bin).

First of all, because the flash chip "GD25Q16C" was out of stock, I am using is the "[Zetta ZD25Q16CTIGT](https://www.lcsc.com/product-detail/_Zetta-_C5160658.html)" instead.
I thought it was compatible, but after everything I have tested, I am starting to think this is the cause.
I am using a 16Gb SD Card and the firmawares were downloaded from the links I found in the [Documentation](https://www.oddlyspecificobjects.com/projects/openbook/)

Please see description of the issue and things I have tried below:

I am facing the following problem:
1- At boot the screen shows the typical message: "Flashing the language chip", but NO progress bar is shown
2- After that, the screen shows only the library icon and battery voltage + battery icon. NO book list is shown (see picture)
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
3- Everytime I reboot the same thing happens.
4- The buttons are responding. The lock button, for instance, locks the book, but the “Slide the power switch to continue” message does NOT appear.

Things I have tried so far whithout success:
1- Removing the babel.bin from the sd card. The book complains that the babel.bin is missing. That is why I think the flashing failed
2- Replacing the flash chip for a new one.
3- Use a new SD card
4- Check electrical continuity or short circuits

I would be glad if you could provide insights on how to proceed or what should I try next.
Let me know if I missed any important information.

Cheers!

joeycastillo, 2023-07-08:
It sounds like this Flash chip may be incompatible.

The lack of progress in the progress bar signals to me that the data never managed to get copied to the Flash chip, although it is interesting that it subsequently makes it to the list of books. Still, once there, the lack of text on the screen signals that it's not getting any data from the Flash chip; all the font data is stored on the chip, so text would fail to show up in this case. The battery voltage is displayed using a smaller character set that's embedded in the Libros application, hence why it shows up even if the other text does not.

rodrirochad, 2023-07-08:
Thanks!
I think so. After testing several SD cards and replacing the chip twice, I still have the same issue.
I have even tried to build a second book only to find the same issue.

Now I am waiting some GD25Q16C flash chip I have ordered from aliexpress to arrive.
I will keep you updated.

**Update on things I have tried and found investigating this issue:**

- Something interesting that adds up to the generic chip beeing the culprit, is that after desoldering the flash chip from the boad the book initializes in the same way.

- I have recently flashed the libros firmware forked from https://github.com/nvts8a/libros
And the openbook.log file output below points out to the problem starting Babel.

 /./_ __   _
///_///_/_\  v0.9.4

[INFO]  Started the SD Card service
[INFO]  Starting Babel
**[ERROR] Failed to start Babel.**
[WARN]  Library version file missing. Creating a new one at: /_LIBRARY/_VERSION
[INFO]  Looking for files in / to copy to /BOOKS...
[WARN]  alex-sese-dear-captain.txt found in the root of the SD card. Moving it to: /BOOKS/alex-sese-dear-captain.txt
[INFO]  Completed looking for and moving files that belong in /BOOKS
[INFO]  Processing new text files...
[INFO]  Processing new BookRecord /BOOKS/alex-sese-dear-captain.txt: ae0d9abd3b5b6ee09237c68a44afd1010b132b791724e92ea2047e2d21edbb5
[INFO]  Completed processing new BookRecord /BOOKS/alex-sese-dear-captain.txt: ae0d9abd3b5b6ee09237c68a44afd1010b132b791724e92ea2047e2d21edbb5
[INFO]  Completed processing new text files.
[INFO]  Writing new BookRecords to disk...
[INFO]  Completed writing new BookRecord files to disk.
[INFO]  Starting pagination of /BOOKS/alex-sese-dear-captain.txt...
[INFO]  Pagination of /BOOKS/alex-sese-dear-captain.txt completed.

rodrirochad, 2023-07-21:
I have managed to flash the library using the GD25Q16CSIG chip that I found in Aliexpress.
This chip has a larger footprint (SOP-8-208mil) but after carefully bending its terminal pins, it will fit in the PCB.

Closing the issue.

Closed 2023-07-21.

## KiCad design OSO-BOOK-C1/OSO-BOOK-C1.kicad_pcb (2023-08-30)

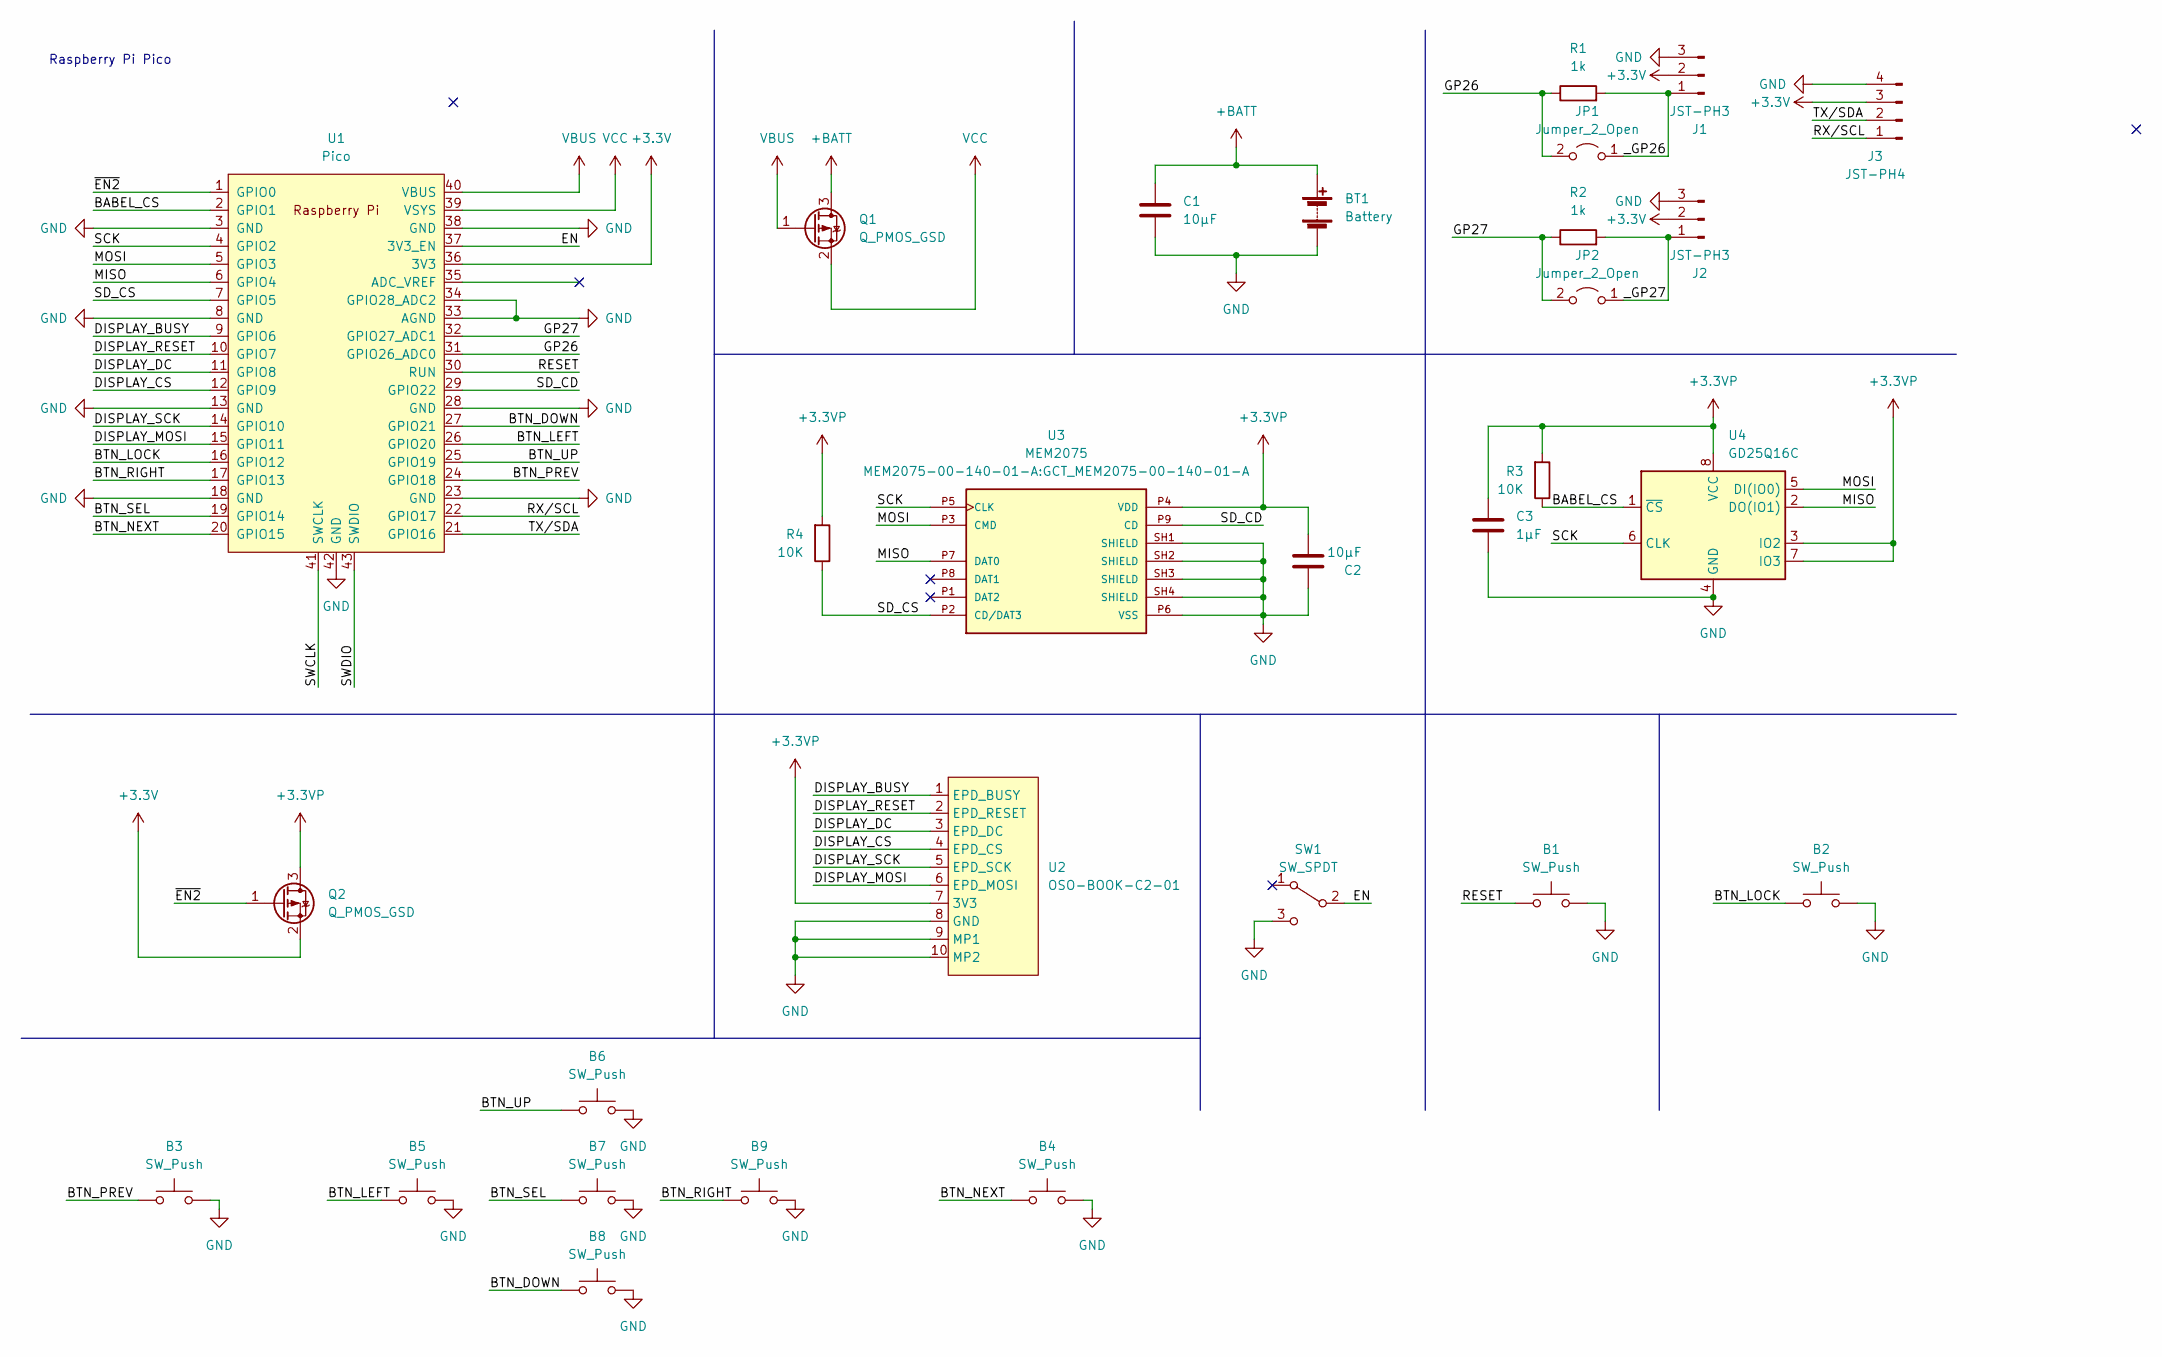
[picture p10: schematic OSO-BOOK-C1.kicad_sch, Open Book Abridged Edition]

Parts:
B1, B2: SW_Push; Panasonic_EVQPUJ_EVQPUA
B3, B4, B5, B6, B7, B8, B9: SW_Push; TACT_PANA-EVQ-BUTTONPAD
BT1: Battery; AAA_SMT
C1, C2: 10µF; C_1206_3216Metric_Pad1.33x1.80mm_HandSolder
C3: 1µF; C_0805_2012Metric_Pad1.18x1.45mm_HandSolder
J1, J2: JST-PH3; JST_PH_S3B-PH-SM4-TB_1x03-1MP_P2.00mm_Horizontal
J3: JST-PH4; JST_SH_SM04B-SRSS-TB_1x04-1MP_P1.00mm_Horizontal
JP1, JP2: Jumper_2_Open; SolderJumper-2_P1.3mm_Open_TrianglePad1.0x1.5mm
Q1, Q2: Q_PMOS_GSD; SOT-23_Handsoldering
R1, R2: 1k; R_0805_2012Metric_Pad1.20x1.40mm_HandSolder
R3, R4: 10K; R_1206_3216Metric_Pad1.30x1.75mm_HandSolder
SW1: SW_SPDT; SW_SPDT_CK-JS102011SAQN
U1: Pico; RPi_Pico_SMD
U2: OSO-BOOK-C2-01
U3: MEM2075; GCT_MEM2075-00-140-01-A; PARTREV A
U4: GD25Q16C; SOIC-8_3.9x4.9mm_P1.27mm

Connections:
+3.3VP: C2.2, C3.1, Q2.3 (D), R3.2, R4.2, U2.7 (3V3), U3.P4 (VDD), U4.3 (IO2), U4.7 (IO3), U4.8 (VCC)
+3V3: J1.2, J2.2, J3.3, Q2.2 (S), U1.36 (3V3)
+BATT: BT1.1 (+), C1.1, Q1.3 (D)
/BABEL_CS: R3.1, U1.2 (GPIO1), U4.1 (~CS)
/BTN_DOWN: B8.1, U1.27 (GPIO21)
/BTN_LEFT: B5.1, U1.26 (GPIO20)
/BTN_LOCK: B2.1, U1.16 (GPIO12)
/BTN_NEXT: B4.1, U1.20 (GPIO15)
/BTN_PREV: B3.1, U1.24 (GPIO18)
/BTN_RIGHT: B9.1, U1.17 (GPIO13)
/BTN_SEL: B7.1, U1.19 (GPIO14)
/BTN_UP: B6.1, U1.25 (GPIO19)
/DISPLAY_BUSY: U1.9 (GPIO6), U2.1 (EPD_BUSY)
/DISPLAY_CS: U1.12 (GPIO9), U2.4 (EPD_CS)
/DISPLAY_DC: U1.11 (GPIO8), U2.3 (EPD_DC)
/DISPLAY_MOSI: U1.15 (GPIO11), U2.6 (EPD_MOSI)
/DISPLAY_RESET: U1.10 (GPIO7), U2.2 (EPD_RESET)
/DISPLAY_SCK: U1.14 (GPIO10), U2.5 (EPD_SCK)
/EN: SW1.2 (B), U1.37 (3V3_EN)
/GP26: JP1.2 (B), R1.1, U1.31 (GPIO26_ADC0)
/GP27: JP2.2 (B), R2.1, U1.32 (GPIO27_ADC1)
/MISO: U1.6 (GPIO4), U3.P7 (DAT0), U4.2 (DO(IO1))
/MOSI: U1.5 (GPIO3), U3.P3 (CMD), U4.5 (DI(IO0))
/RESET: B1.1, U1.30 (RUN)
/RX/SCL: J3.1, U1.22 (GPIO17)
/SCK: U1.4 (GPIO2), U3.P5 (CLK), U4.6 (CLK)
/SD_CD: U1.29 (GPIO22), U3.P9 (CD)
/SD_CS: R4.1, U1.7 (GPIO5), U3.P2 (CD/DAT3)
/SWCLK: U1.41 (SWCLK)
/SWDIO: U1.43 (SWDIO)
/TX/SDA: J3.2, U1.21 (GPIO16)
/_GP26: J1.1, JP1.1 (A), R1.2
/_GP27: J2.1, JP2.1 (A), R2.2
/~EN2: Q2.1 (G), U1.1 (GPIO0)
GND: B1.2, B2.2, B3.2, B4.2, B5.2, B6.2, B7.2, B8.2, B9.2, BT1.2 (-), C1.2, C2.1, C3.2, J1.3, J2.3, J3.4, SW1.3 (C), U1.3 (GND), U1.8 (GND), U1.13 (GND), U1.18 (GND), U1.23 (GND), U1.28 (GND), U1.33 (AGND), U1.34 (GPIO28_ADC2), U1.38 (GND), U1.42 (GND), U2.8 (GND), U2.9 (MP1), U2.10 (MP2), U3.P6 (VSS), U3.SH1 (SHIELD), U3.SH2 (SHIELD), U3.SH3 (SHIELD), U3.SH4 (SHIELD), U4.4 (GND)
VBUS: Q1.1 (G), U1.40 (VBUS)
VCC: Q1.2 (S), U1.39 (VSYS)

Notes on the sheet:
Raspberry Pi Pico

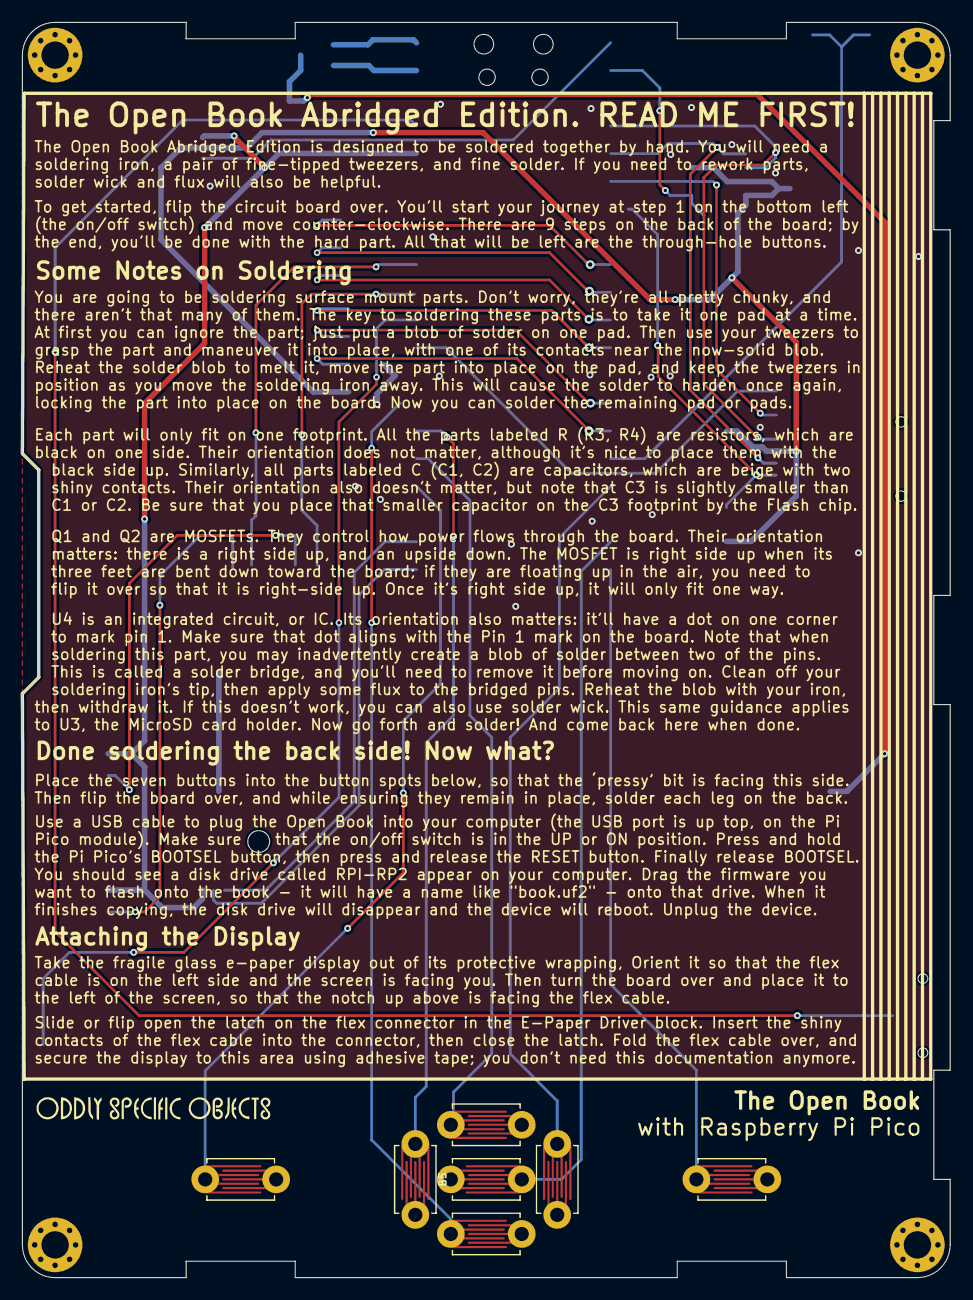
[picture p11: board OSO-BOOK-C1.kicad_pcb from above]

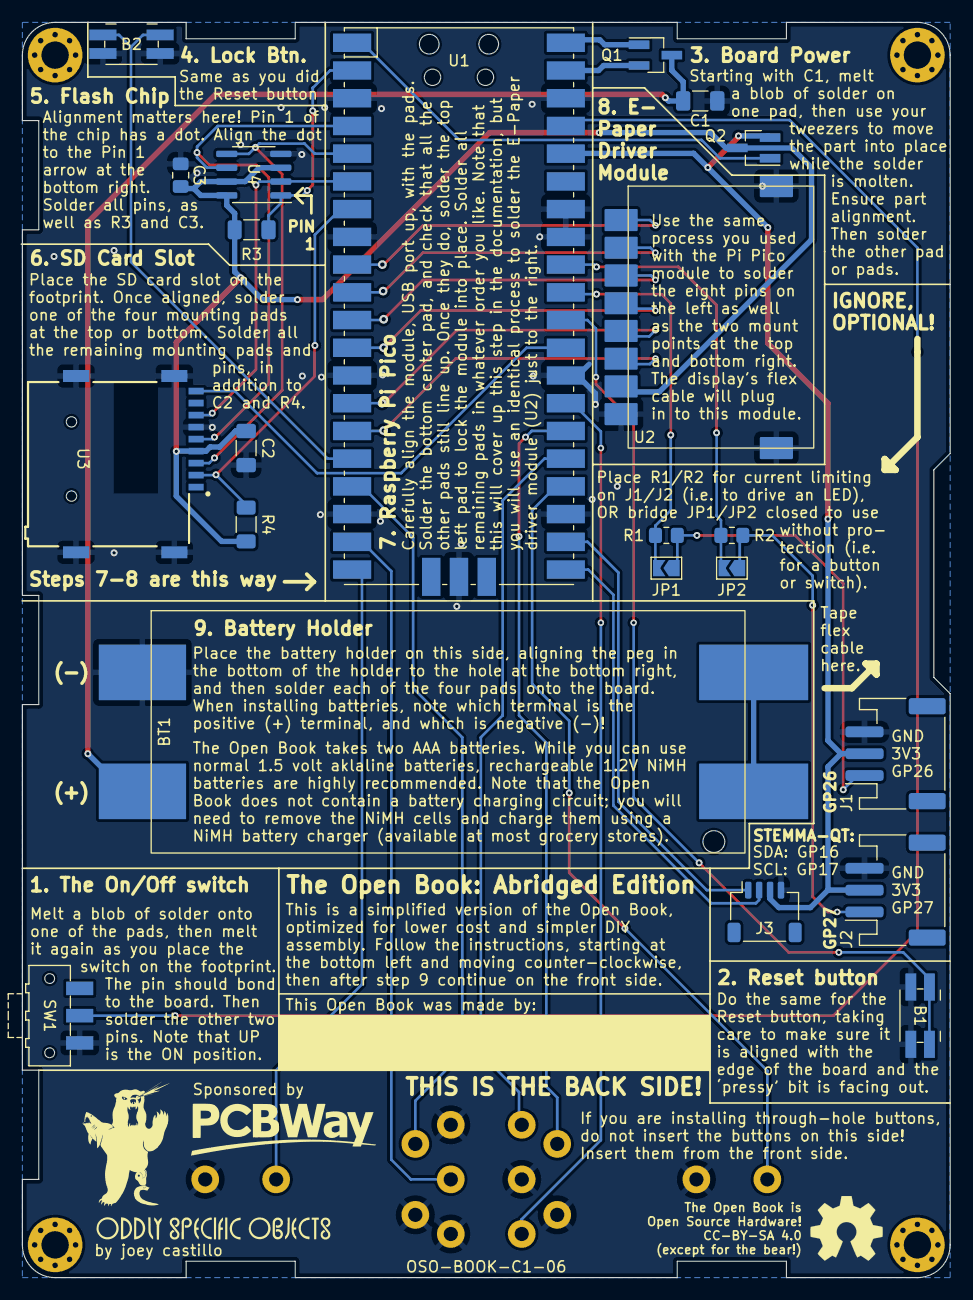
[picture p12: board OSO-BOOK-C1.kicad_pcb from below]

Board: 2 copper layers, 85.0 x 115.0 mm, 29 parts (22 on the bottom side), 35 nets.

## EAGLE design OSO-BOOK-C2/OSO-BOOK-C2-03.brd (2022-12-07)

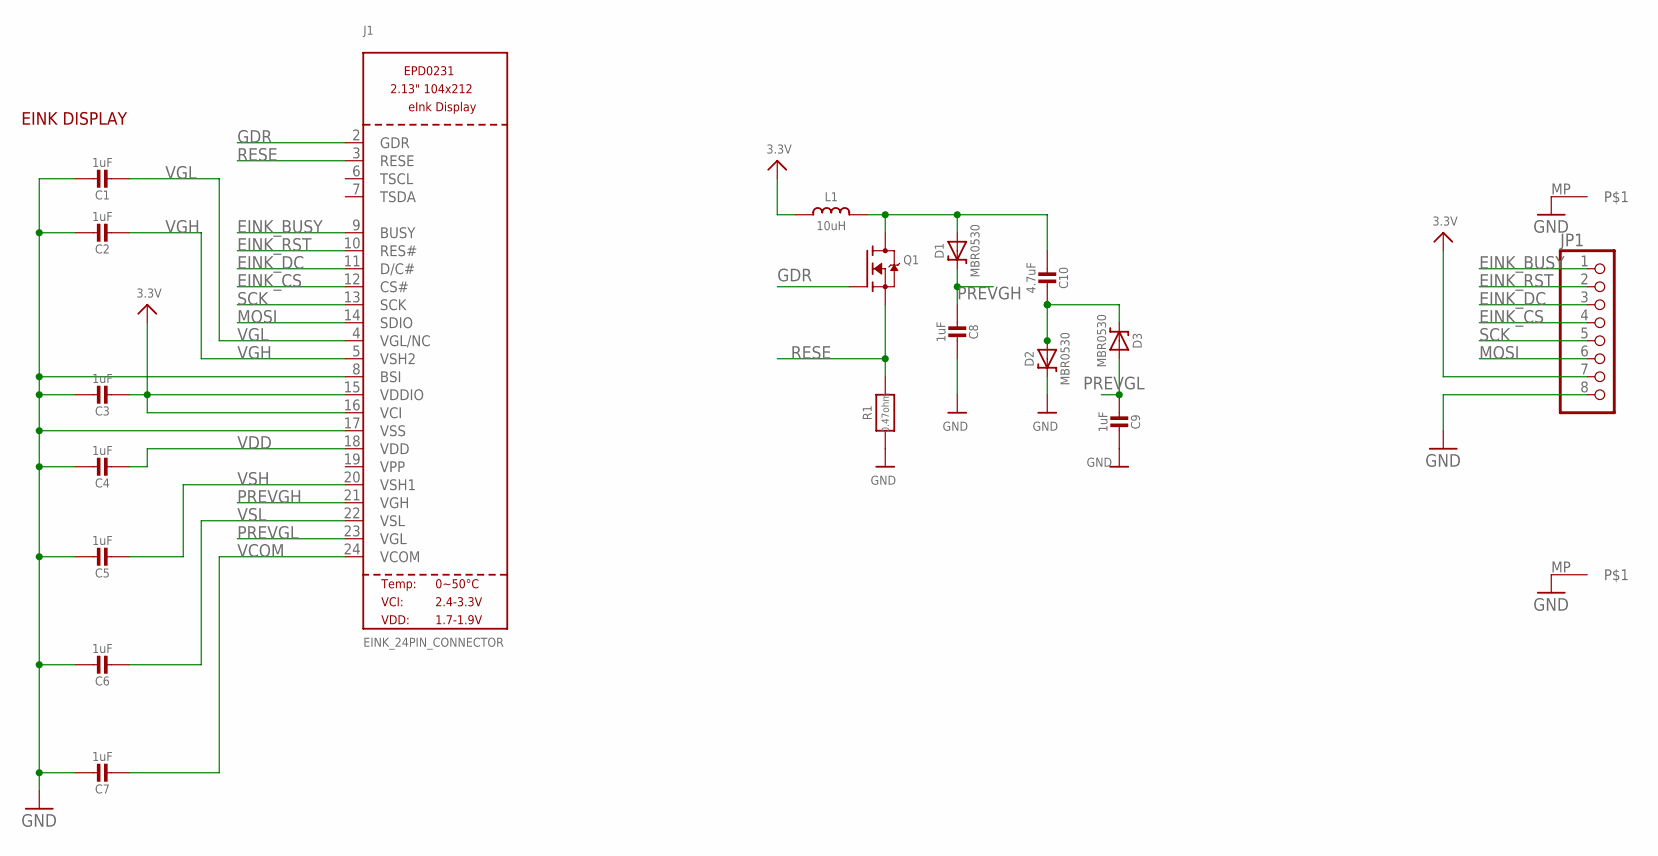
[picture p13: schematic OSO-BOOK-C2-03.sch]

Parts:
C1, C2, C3, C4, C5, C6, C7, C8, C9: 1uF; 0805-NO
C10: 4.7uF; 0805-NO
D1, D2, D3: MBR0530; SOD-123
J1: EINK_24PIN_CONNECTOR; EINK_24PIN
JP1: HEADER-1X8ROUND76; 1X08_ROUND_76
L1: 10uH; MICROBUILDER__0805
Q1: IRLML0100; SOT23-3
R1: 0.47ohm; _0402
U$2, U$3: BIGOVAL

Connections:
3.3V: C3.2, J1.15 (VDDIO), J1.16 (VCI), JP1.7, L1.1
EINK_BUSY: J1.9 (BUSY), JP1.1
EINK_CS: J1.12 (CS#), JP1.4
EINK_DC: J1.11 (D/C#), JP1.3
EINK_RST: J1.10 (RES#), JP1.2
GDR: J1.2 (GDR), Q1.1 (G)
GND: C1.1, C2.1, C3.1, C4.1, C5.1, C6.1, C7.1, C8.2, C9.2, D2.C, J1.8 (BSI), J1.17 (VSS), JP1.8, R1.2, U$2.MP, U$3.MP
MOSI: J1.14 (SDIO), JP1.6
unnamed: C10.2, D2.A, D3.C
unnamed: C10.1, D1.A, L1.2, Q1.3 (D)
PREVGH: C8.1, D1.C, J1.21 (VGH)
PREVGL: C9.1, D3.A, J1.23 (VGL)
RESE: J1.3 (RESE), Q1.2 (S), R1.1
SCK: J1.13 (SCK), JP1.5
VCOM: C7.2, J1.24 (VCOM)
VDD: C4.2, J1.18 (VDD)
VGH: C2.2, J1.5 (VSH2)
VGL: C1.2, J1.4 (VGL/NC)
VSH: C5.2, J1.20 (VSH1)
VSL: C6.2, J1.22 (VSL)

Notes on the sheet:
EINK DISPLAY

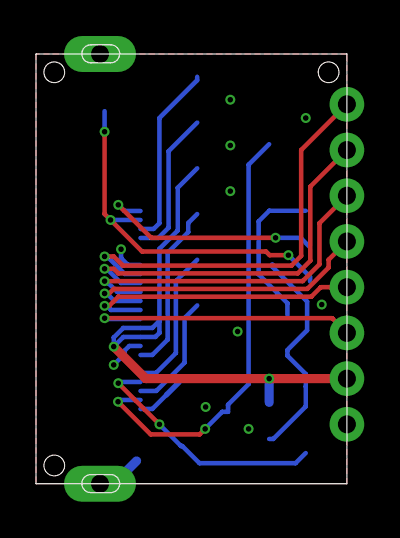
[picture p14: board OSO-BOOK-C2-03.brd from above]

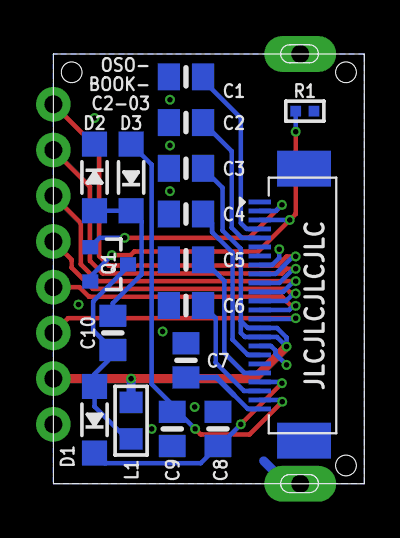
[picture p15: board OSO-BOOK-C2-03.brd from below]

Board: 2 copper layers, 17.3 x 24.9 mm, 20 parts (17 on the bottom side), 20 nets.

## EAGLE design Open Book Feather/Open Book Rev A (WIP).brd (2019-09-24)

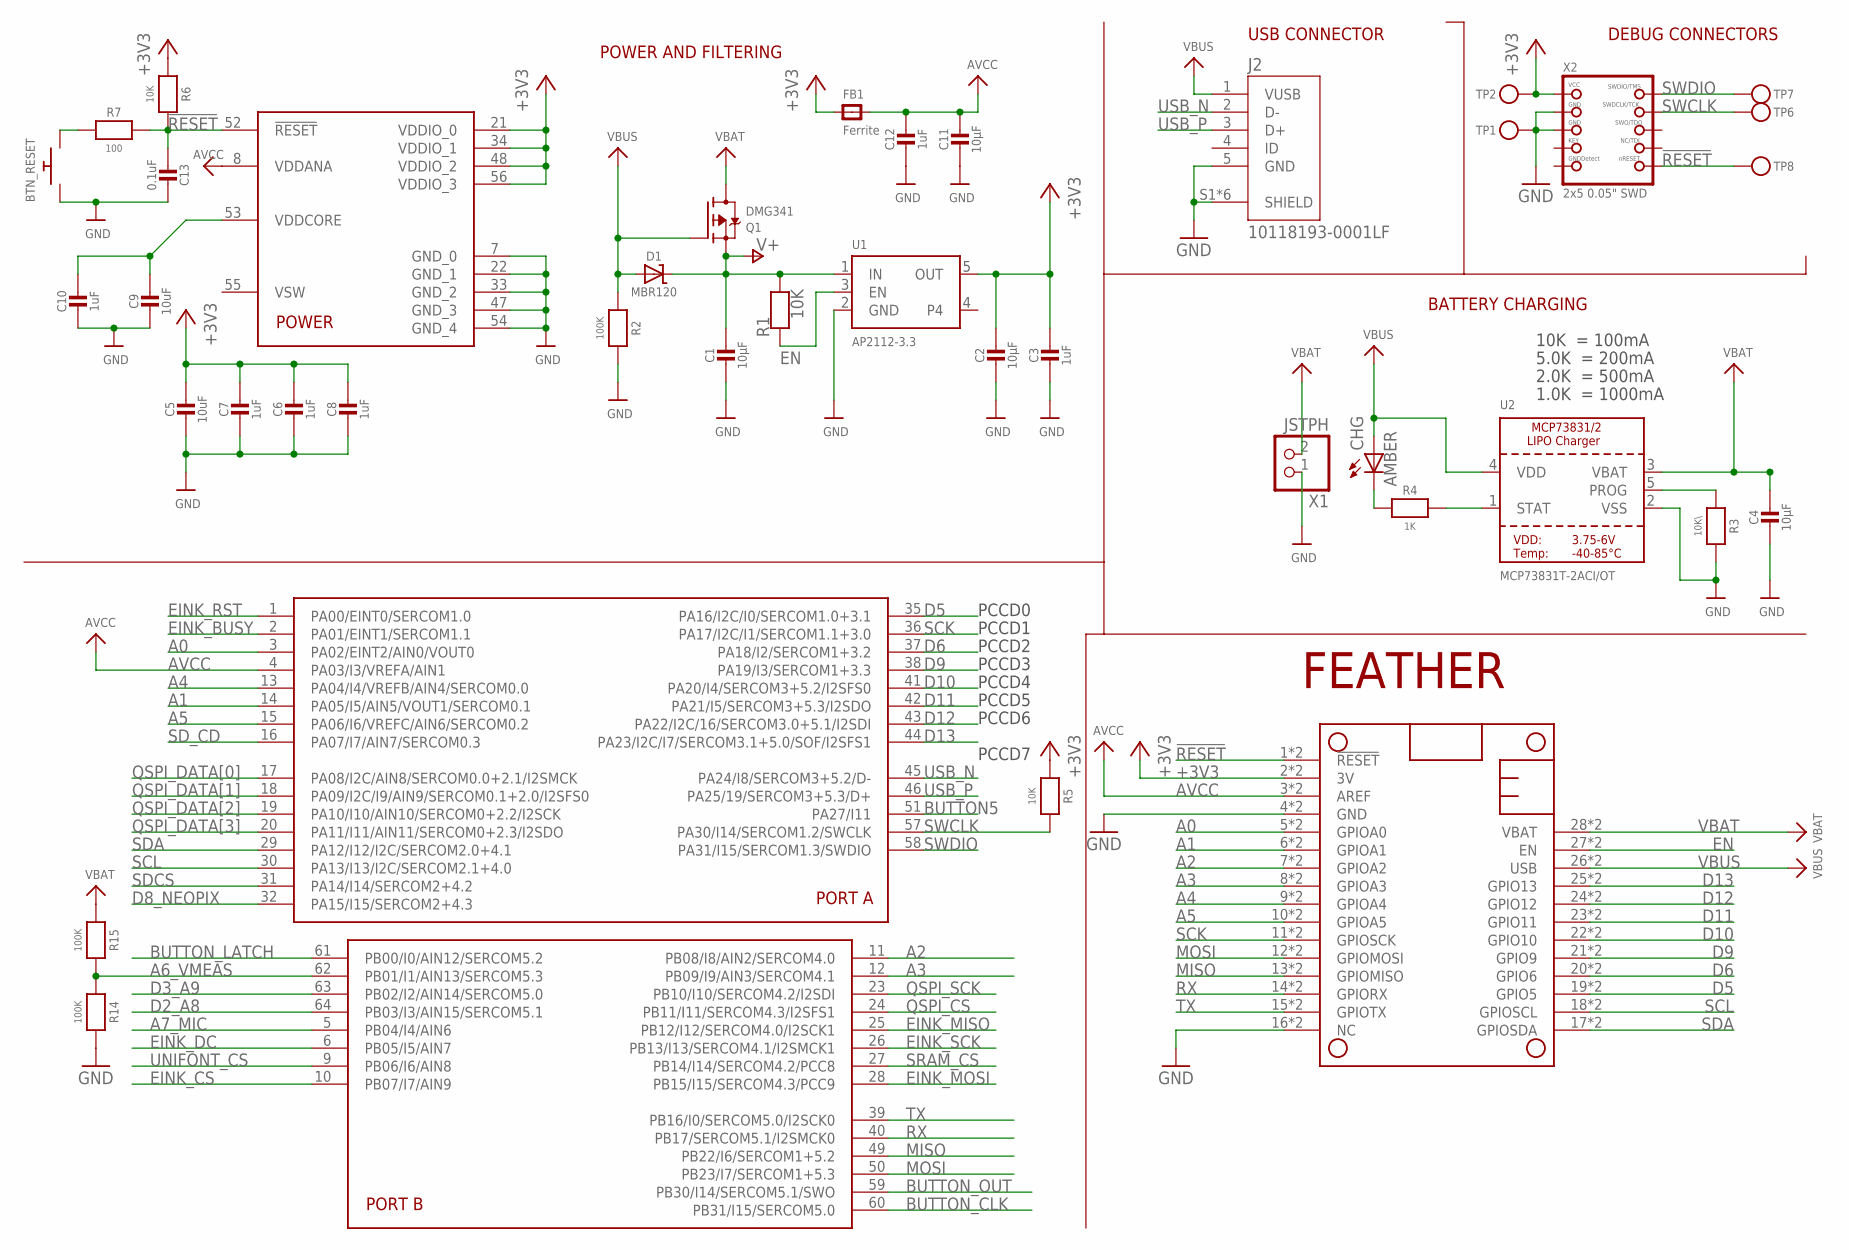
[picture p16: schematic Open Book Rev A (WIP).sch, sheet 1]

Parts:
BTN_RESET: SPST_TACTILE_SWITCHRA; TL3330AF130QG
C1, C2, C4, C11: 10µF; 0805-NO
C3, C7, C12: 1uF; 0805-NO
C5, C9: 10uF; 0805_10MGAP
C6, C8, C10: 1uF; 0805_10MGAP
C13: 0.1uF; 0805_10MGAP
CHG: AMBER; LED3MM
D1: MBR120; SOD-123
FB1: Ferrite; 0805
J2: 10118193-0001LF; FCI_10118193-0001LF
MS2: FEATHERWING_SMTDUAL; FEATHERWING_SMT2
Q1: DMG341; SOT23-R
R1: 10K; 0805-NO
R2, R14, R15: 100K; 0805-NO
R3: 10K\; 0805-NO
R4: 1K; 0805-NO
R5, R6: 10K; 0805_10MGAP
R7: 100; 0805_10MGAP
TP1, TP2, TP6, TP7, TP8: TESTPOINTROUND2MMNO; TESTPOINT_ROUND_2MM_NO
U1: AP2112-3.3; SOT23-5
U2: MCP73831T-2ACI/OT; SOT23-5
U3: ATSAMD51J64-TQFP(10X10); TQFP64-10X10
X1: JSTPH; JSTPH2
X2: 2x5 0.05" SWD; 2X05_1.27MM_BOX_POSTS

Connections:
!RESET: C13.2, MS2.1 (!RESET), MS2.1' (!RESET), R6.2, R7.2, TP8.P$1, U3.52 (!RESET), X2.10 (NRESET)
+3V3: C2.1, C3.1, C5.1, C6.1, C7.1, C8.1, FB1.1, MS2.2 (3V), MS2.2' (3V), R5.1, R6.1, TP2.P$1, U1.5 (OUT), U3.21 (VDDIO_0), U3.34 (VDDIO_1), U3.48 (VDDIO_2), U3.56 (VDDIO_3), X2.1 (VCC); also elsewhere on the board
A0: MS2.5 (GPIOA0), MS2.5' (GPIOA0), U3.3 (PA02/EINT2/AIN0/VOUT0); also elsewhere on the board
A1: MS2.6 (GPIOA1), MS2.6' (GPIOA1), U3.14 (PA05/I5/AIN5/VOUT1/SERCOM0.1); also elsewhere on the board
A2: MS2.7 (GPIOA2), MS2.7' (GPIOA2), U3.11 (PB08/I8/AIN2/SERCOM4.0)
A3: MS2.8 (GPIOA3), MS2.8' (GPIOA3), U3.12 (PB09/I9/AIN3/SERCOM4.1)
A4: MS2.9 (GPIOA4), MS2.9' (GPIOA4), U3.13 (PA04/I4/VREFB/AIN4/SERCOM0.0)
A5: MS2.10 (GPIOA5), MS2.10' (GPIOA5), U3.15 (PA06/I6/VREFC/AIN6/SERCOM0.2)
A6_VMEAS: R14.1, R15.2, U3.62 (PB01/I1/AIN13/SERCOM5.3)
A7_MIC: U3.5 (PB04/I4/AIN6); also elsewhere on the board
AVCC: C11.1, C12.1, FB1.2, MS2.3 (AREF), MS2.3' (AREF), U3.4 (PA03/I3/VREFA/AIN1), U3.8 (VDDANA)
BUTTON5: U3.51 (PA27/I11); also elsewhere on the board
BUTTON_CLK: U3.60 (PB31/I15/SERCOM5.0); also elsewhere on the board
BUTTON_LATCH: U3.61 (PB00/I0/AIN12/SERCOM5.2); also elsewhere on the board
BUTTON_OUT: U3.59 (PB30/I14/SERCOM5.1/SWO); also elsewhere on the board
D2_A8: U3.64 (PB03/I3/AIN15/SERCOM5.1); also elsewhere on the board
D3_A9: U3.63 (PB02/I2/AIN14/SERCOM5.0); also elsewhere on the board
D5: MS2.19 (GPIO5), MS2.19' (GPIO5), U3.35 (PA16/I2C/I0/SERCOM1.0+3.1)
D6: MS2.20 (GPIO6), MS2.20' (GPIO6), U3.37 (PA18/I2/SERCOM1+3.2)
D8_NEOPIX: U3.32 (PA15/I15/SERCOM2+4.3); also elsewhere on the board
D9: MS2.21 (GPIO9), MS2.21' (GPIO9), U3.38 (PA19/I3/SERCOM1+3.3)
D10: MS2.22 (GPIO10), MS2.22' (GPIO10), U3.41 (PA20/I4/SERCOM3+5.2/I2SFS0)
D11: MS2.23 (GPIO11), MS2.23' (GPIO11), U3.42 (PA21/I5/SERCOM3+5.3/I2SDO)
D12: MS2.24 (GPIO12), MS2.24' (GPIO12), U3.43 (PA22/I2C/16/SERCOM3.0+5.1/I2SDI)
D13: MS2.25 (GPIO13), MS2.25' (GPIO13), U3.44 (PA23/I2C/I7/SERCOM3.1+5.0/SOF/I2SFS1); also elsewhere on the board
EINK_BUSY: U3.2 (PA01/EINT1/SERCOM1.1); also elsewhere on the board
EINK_CS: U3.10 (PB07/I7/AIN9); also elsewhere on the board
EINK_DC: U3.6 (PB05/I5/AIN7); also elsewhere on the board
EINK_MISO: U3.25 (PB12/I12/SERCOM4.0/I2SCK1); also elsewhere on the board
EINK_MOSI: U3.28 (PB15/I15/SERCOM4.3/PCC9); also elsewhere on the board
EINK_RST: U3.1 (PA00/EINT0/SERCOM1.0); also elsewhere on the board
EINK_SCK: U3.26 (PB13/I13/SERCOM4.1/I2SMCK1); also elsewhere on the board
EN: MS2.27 (EN), MS2.27' (EN), R1.1, U1.3 (EN); also elsewhere on the board
GND: BTN_RESET.P$1, C1.2, C2.2, C3.2, C4.2, C5.2, C6.2, C7.2, C8.2, C9.2, C10.2, C11.2, C12.2, C13.1, J2.5 (GND), J2.S1 (SHIELD), J2.S2 (SHIELD), J2.S3 (SHIELD), J2.S4 (SHIELD), J2.S5 (SHIELD), J2.S6 (SHIELD), MS2.4 (GND), MS2.4' (GND), MS2.16 (NC), MS2.16' (NC), R2.2, R3.2, R14.2, TP1.P$1, U1.2 (GND), U2.2 (VSS), U3.7 (GND_0), U3.22 (GND_1), U3.33 (GND_2), U3.47 (GND_3), U3.54 (GND_4), X1.1, X2.3 (GND), X2.5 (GND); also elsewhere on the board
MISO: MS2.13 (GPIOMISO), MS2.13' (GPIOMISO), U3.49 (PB22/I6/SERCOM1+5.2); also elsewhere on the board
MOSI: MS2.12 (GPIOMOSI), MS2.12' (GPIOMOSI), U3.50 (PB23/I7/SERCOM1+5.3); also elsewhere on the board
unnamed: BTN_RESET.P$2, R7.1
unnamed: CHG.K (C), R4.1
unnamed: R4.2, U2.1 (STAT)
PROG: R3.1, U2.5 (PROG)
QSPI_CS: U3.24 (PB11/I11/SERCOM4.3/I2SFS1); also elsewhere on the board
QSPI_DATA[0]: U3.17 (PA08/I2C/AIN8/SERCOM0.0+2.1/I2SMCK); also elsewhere on the board
QSPI_DATA[1]: U3.18 (PA09/I2C/I9/AIN9/SERCOM0.1+2.0/I2SFS0); also elsewhere on the board
QSPI_DATA[2]: U3.19 (PA10/I10/AIN10/SERCOM0+2.2/I2SCK); also elsewhere on the board
QSPI_DATA[3]: U3.20 (PA11/I11/AIN11/SERCOM0+2.3/I2SDO); also elsewhere on the board
QSPI_SCK: U3.23 (PB10/I10/SERCOM4.2/I2SDI); also elsewhere on the board
RX: MS2.14 (GPIORX), MS2.14' (GPIORX), U3.40 (PB17/SERCOM5.1/I2SMCK0); also elsewhere on the board
SCK: MS2.11 (GPIOSCK), MS2.11' (GPIOSCK), U3.36 (PA17/I2C/I1/SERCOM1.1+3.0); also elsewhere on the board
SCL: MS2.18 (GPIOSCL), MS2.18' (GPIOSCL), U3.30 (PA13/I13/I2C/SERCOM2.1+4.0); also elsewhere on the board
SDA: MS2.17 (GPIOSDA), MS2.17' (GPIOSDA), U3.29 (PA12/I12/I2C/SERCOM2.0+4.1); also elsewhere on the board
SDCS: U3.31 (PA14/I14/SERCOM2+4.2); also elsewhere on the board
SD_CD: U3.16 (PA07/I7/AIN7/SERCOM0.3); also elsewhere on the board
SRAM_CS: U3.27 (PB14/I14/SERCOM4.2/PCC8); also elsewhere on the board
SWCLK: R5.2, TP6.P$1, U3.57 (PA30/I14/SERCOM1.2/SWCLK), X2.4 (SWDCLK)
SWDIO: TP7.P$1, U3.58 (PA31/I15/SERCOM1.3/SWDIO), X2.2 (SWDIO)
TX: MS2.15 (GPIOTX), MS2.15' (GPIOTX), U3.39 (PB16/I0/SERCOM5.0/I2SCK0); also elsewhere on the board
UNIFONT_CS: U3.9 (PB06/I6/AIN8); also elsewhere on the board
USB_N: J2.2 (D-), U3.45 (PA24/I8/SERCOM3+5.2/D-)
USB_P: J2.3 (D+), U3.46 (PA25/19/SERCOM3+5.3/D+)
V+: C1.1, D1.C, Q1.2 (S), R1.2, U1.1 (IN); also elsewhere on the board
VBAT: C4.1, MS2.28 (VBAT), MS2.28' (VBAT), Q1.3 (D), R15.1, U2.3 (VBAT), X1.2
VBUS: CHG.A, D1.A, J2.1 (VUSB), MS2.26 (USB), MS2.26' (USB), Q1.1 (G), R2.1, U2.4 (VDD)
VDDCORE2: C9.1, C10.1, U3.53 (VDDCORE)

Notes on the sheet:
FEATHER
PCCD0
PCCD1
PCCD2
PCCD3
PCCD4
PCCD5
PCCD6
PCCD7
POWER AND FILTERING
10K = 100mA
5.0K = 200mA
2.0K = 500mA
1.0K = 1000mA
BATTERY CHARGING
DEBUG CONNECTORS
USB CONNECTOR

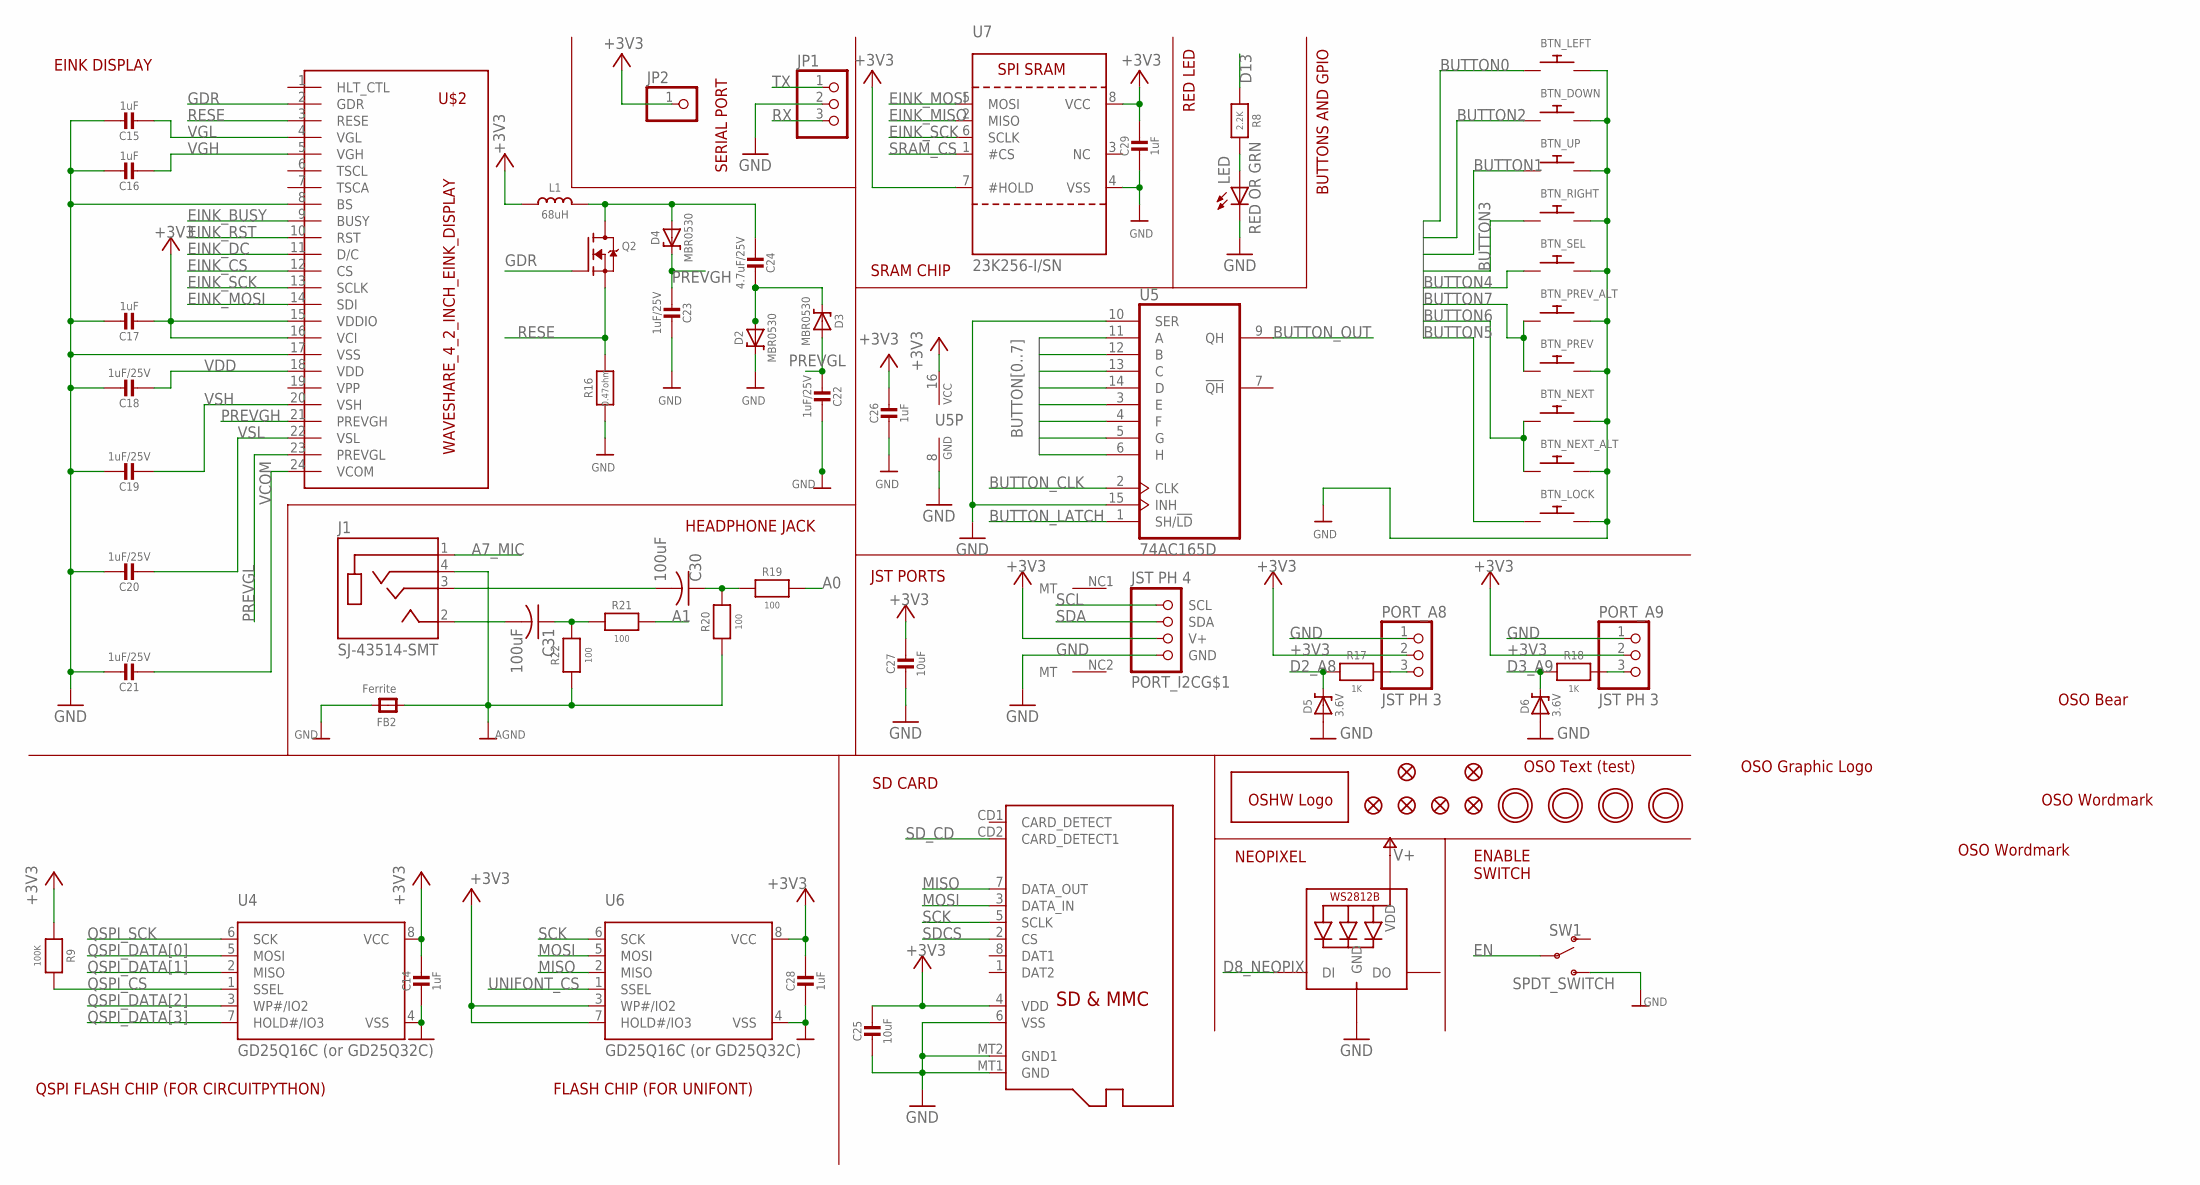
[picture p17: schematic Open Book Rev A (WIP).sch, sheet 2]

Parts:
BTN_DOWN: MJTP1250_SPST_SWITCH; MJTP1250
BTN_LEFT: MJTP1250_SPST_SWITCH; MJTP1250
BTN_LOCK: SPST_TACTILE_SWITCHRA; TL3330AF130QG
BTN_NEXT: MJTP1250_SPST_SWITCH; MJTP1250
BTN_NEXT_ALT: SPST_TACTILE_SWITCHRA; TL3330AF130QG
BTN_PREV: MJTP1250_SPST_SWITCH; MJTP1250
BTN_PREV_ALT: SPST_TACTILE_SWITCHRA; TL3330AF130QG
BTN_RIGHT: MJTP1250_SPST_SWITCH; MJTP1250
BTN_SEL: MJTP1250_SPST_SWITCH; MJTP1250
BTN_UP: MJTP1250_SPST_SWITCH; MJTP1250
C14, C15, C16, C17: 1uF; 0805-NO
C18, C19, C20, C21, C22, C23: 1uF/25V; 0805-NO
C24: 4.7uF/25V; 0805-NO
C25: 10uF; 0805_10MGAP
C26, C28, C29: 1uF; 0805_10MGAP
C27: 10uF; 0805-NO
C30, C31: 100uF; C1210
D2, D3, D4: MBR0530; SOD-123
D5, D6: 3.6V; SOD-123
FB2: Ferrite; 0805
FID1, FID2, FID3, FID4, FID5, FID6: FIDUCIAL_1MM
GOLD_ORB_SM1: OSHWLOGOLOGO5MM; OSHW_5MM
J1: SJ-43514-SMT; CUI_SJ-43514-SMT
JP1: PINHD-1X3; 1X03
JP2: PINHD-1X1; 1X01
L1: 68uH; INDUCTOR_4X4MM_NR401
LED: RED OR GRN; LED3MM
MICROSD: MICROSD
PORT_A8, PORT_A9: JST PH 3; JSTPH3
PORT_I2C: JST PH 4; JSTPH4
Q2: IRLML0100; SOT23-3
R8: 2.2K; 0805-NO
R9: 100K; 0805-NO
R16: 0.47ohm; 0805_10MGAP
R17, R18: 1K; _0805MP
R19, R20, R21, R22: 100; 0805-NO
STATUS: WS2812B; LED5MMRGB
SW1: SPDT_SWITCH; A10767
U4: GD25Q16C (or GD25Q32C); SOIC8_150MIL
U5: 74AC165D; SO16
U6: GD25Q16C (or GD25Q32C); MICROBUILDER_SOIC8_150MIL
U7: 23K256-I/SN; SOIC8_150MIL
U$1, U$4, U$5, U$7: MOUNTINGHOLE2.5; MOUNTINGHOLE_2.5_PLATED
U$2: WAVESHARE_4_2_INCH_EINK_DISPLAY; EINK_DISPLAY_4_2IN
U$23: OSO-TEXT-TEST
U$44: OSO_GRAPHIC
U$45: OSO_BEAR; OSO_BEAR_750MIL
U$47: OSO_TEXT; OSO_TEXT_435MIL
U$48: OSO_TEXTOSO_TEXT_ONELINE_125MIL; OSO_ONELINE_125MIL

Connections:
+3V3: C14.1, C17.2, C25.1, C26.1, C27.1, C28.1, C29.1, JP2.1, L1.P$2 (2), MICROSD.4 (VDD), PORT_A8.2, PORT_A9.2, PORT_I2C.2 (V+), R9.1, U4.8 (VCC), U5.16 (VCC), U6.3 (WP#/IO2), U6.7 (HOLD#/IO3), U6.8 (VCC), U7.7 (#HOLD), U7.8 (VCC), U$2.15 (VDDIO), U$2.16 (VCI); also elsewhere on the board
A0: R19.2; also elsewhere on the board
A1: R21.2; also elsewhere on the board
A7_MIC: J1.1 (SLEEVE); also elsewhere on the board
A8_: PORT_A8.3, R17.1
A9_: PORT_A9.3, R18.1
AGND: FB2.1, J1.4 (RING2), R20.1, R22.1
AUDIO_LEFT: C31.2, J1.2 (TIP)
AUDIO_RIGHT: C30.2, J1.3 (RING1)
BUTTON0: BTN_LEFT.P$1, U5.11 (A)
BUTTON1: BTN_UP.P$1, U5.12 (B)
BUTTON2: BTN_DOWN.P$1, U5.13 (C)
BUTTON3: BTN_RIGHT.P$1, U5.14 (D)
BUTTON4: BTN_SEL.P$1, U5.3 (E)
BUTTON5: BTN_LOCK.P$1, U5.4 (F); also elsewhere on the board
BUTTON6: BTN_NEXT.P$1, BTN_NEXT_ALT.P$1, U5.5 (G)
BUTTON7: BTN_PREV.P$1, BTN_PREV_ALT.P$1, U5.6 (H)
BUTTON_CLK: U5.2 (CLK); also elsewhere on the board
BUTTON_LATCH: U5.1 (SH/!LD); also elsewhere on the board
BUTTON_OUT: U5.9 (QH); also elsewhere on the board
D2_A8: D5.C, R17.2; also elsewhere on the board
D3_A9: D6.C, R18.2; also elsewhere on the board
D8_NEOPIX: STATUS.4 (DI); also elsewhere on the board
D13: R8.1; also elsewhere on the board
EINK_BUSY: U$2.9 (BUSY); also elsewhere on the board
EINK_CS: U$2.12 (CS); also elsewhere on the board
EINK_DC: U$2.11 (D/C); also elsewhere on the board
EINK_MISO: U7.2 (MISO); also elsewhere on the board
EINK_MOSI: U7.5 (MOSI), U$2.14 (SDI); also elsewhere on the board
EINK_RST: U$2.10 (RST); also elsewhere on the board
EINK_SCK: U7.6 (SCLK), U$2.13 (SCLK); also elsewhere on the board
EN: SW1.P$2; also elsewhere on the board
GDR: Q2.1 (G), U$2.2 (GDR)
GND: BTN_DOWN.P$2, BTN_LEFT.P$2, BTN_LOCK.P$2, BTN_NEXT.P$2, BTN_NEXT_ALT.P$2, BTN_PREV.P$2, BTN_PREV_ALT.P$2, BTN_RIGHT.P$2, BTN_SEL.P$2, BTN_UP.P$2, C14.2, C15.1, C16.1, C17.1, C18.1, C19.1, C20.1, C21.1, C22.2, C23.2, C25.2, C26.2, C27.2, C28.2, C29.2, D2.C, D5.A, D6.A, FB2.2, JP1.2, LED.K (C), MICROSD.6 (VSS), MICROSD.MT1 (GND), MICROSD.MT2 (GND1), PORT_A8.1, PORT_A9.1, PORT_I2C.1 (GND), R16.2, STATUS.2 (GND), SW1.P$3 (S), U4.4 (VSS), U5.8 (GND), U5.10 (SER), U5.15 (INH), U6.4 (VSS), U7.4 (VSS), U$2.8 (BS), U$2.17 (VSS); also elsewhere on the board
MISO: MICROSD.7 (DATA_OUT), U6.2 (MISO); also elsewhere on the board
MOSI: MICROSD.3 (DATA_IN), U6.5 (MOSI); also elsewhere on the board
unnamed: C24.2, D2.A, D3.C
unnamed: C24.1, D4.A, L1.P$1 (1), Q2.3 (D)
unnamed: LED.A, R8.2
unnamed: C31.1, R21.1, R22.2
unnamed: C30.1, R19.1, R20.2
PREVGH: C23.1, D4.C, U$2.21 (PREVGH)
PREVGL: C22.1, D3.A, U$2.23 (PREVGL)
QSPI_CS: R9.2, U4.1 (SSEL); also elsewhere on the board
QSPI_DATA[0]: U4.5 (MOSI); also elsewhere on the board
QSPI_DATA[1]: U4.2 (MISO); also elsewhere on the board
QSPI_DATA[2]: U4.3 (WP#/IO2); also elsewhere on the board
QSPI_DATA[3]: U4.7 (HOLD#/IO3); also elsewhere on the board
QSPI_SCK: U4.6 (SCK); also elsewhere on the board
RESE: Q2.2 (S), R16.1, U$2.3 (RESE)
RX: JP1.3; also elsewhere on the board
SCK: MICROSD.5 (SCLK), U6.6 (SCK); also elsewhere on the board
SCL: PORT_I2C.4 (SCL); also elsewhere on the board
SDA: PORT_I2C.3 (SDA); also elsewhere on the board
SDCS: MICROSD.2 (CS); also elsewhere on the board
SD_CD: MICROSD.CD2 (CARD_DETECT1); also elsewhere on the board
SRAM_CS: U7.1 (#CS); also elsewhere on the board
TX: JP1.1; also elsewhere on the board
UNIFONT_CS: U6.1 (SSEL); also elsewhere on the board
V+: STATUS.3 (VDD); also elsewhere on the board
VCOM: C21.2, U$2.24 (VCOM)
VDD: C18.2, U$2.18 (VDD)
VGH: C16.2, U$2.5 (VGH)
VGL: C15.2, U$2.4 (VGL)
VSH: C19.2, U$2.20 (VSH)
VSL: C20.2, U$2.22 (VSL)

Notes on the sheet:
SD CARD
EINK DISPLAY
HEADPHONE JACK
ENABLE SWITCH
BUTTONS AND GPIO
JST PORTS
QSPI FLASH CHIP (FOR CIRCUITPYTHON)
SERIAL PORT
RED LED
FLASH CHIP (FOR UNIFONT)
NEOPIXEL
SRAM CHIP

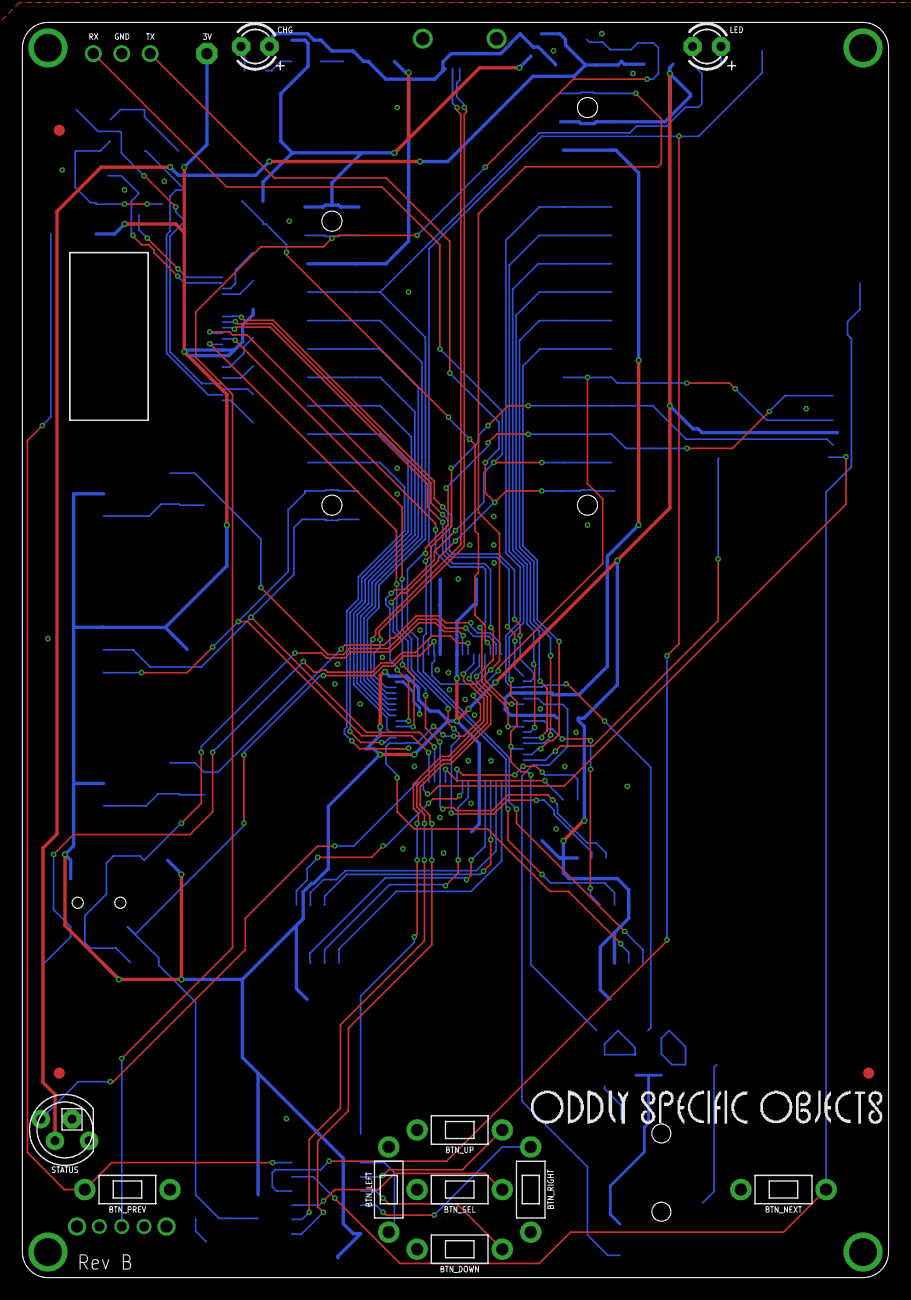
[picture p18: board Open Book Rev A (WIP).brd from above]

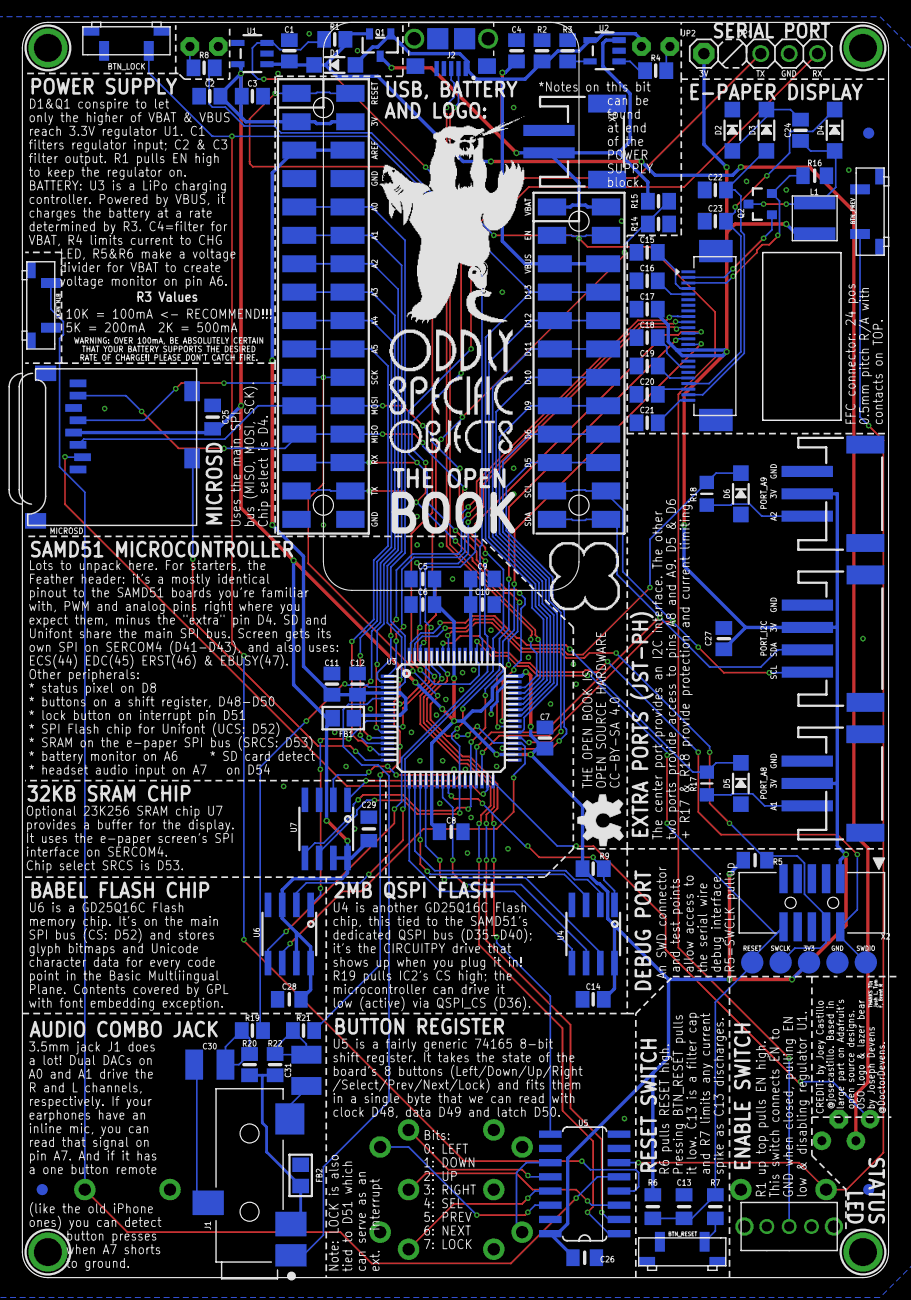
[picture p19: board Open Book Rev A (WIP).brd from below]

Board: 2 copper layers, 77.5 x 112.3 mm, 115 parts (100 on the bottom side), 90 nets.

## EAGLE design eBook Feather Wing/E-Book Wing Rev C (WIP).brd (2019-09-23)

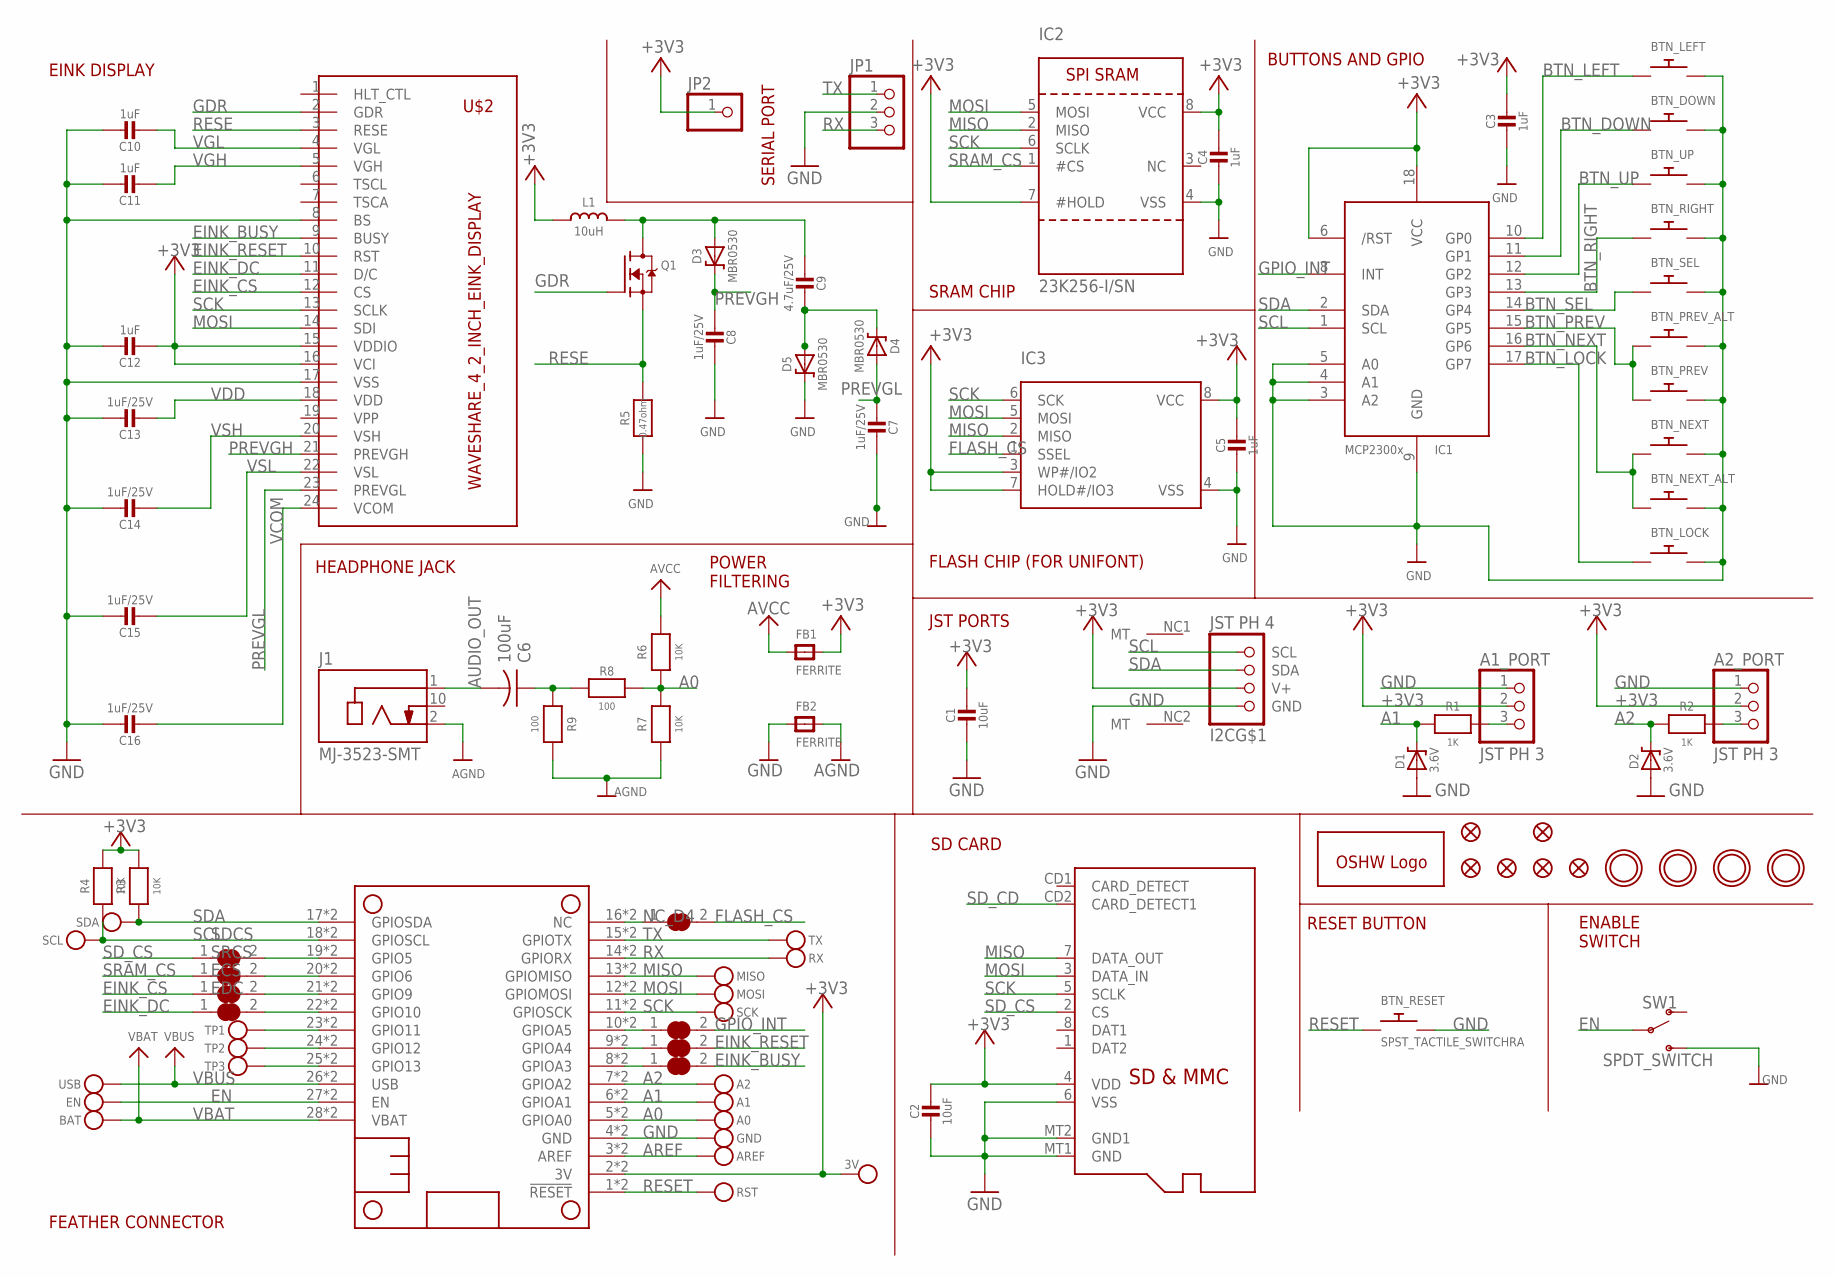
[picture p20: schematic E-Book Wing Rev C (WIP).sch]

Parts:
3V: MICROBUILDER_TESTPOINT1.5X2.0MM_NOCREAM; MICROBUILDER_PAD-1.5X2.0
A0, A1, A2: MICROBUILDER_TESTPOINT1.5X2.0MM_NOCREAM; MICROBUILDER_PAD-1.5X2.0
A1_PORT, A2_PORT: JST PH 3; JSTPH3
AREF: MICROBUILDER_TESTPOINT1.5X2.0MM_NOCREAM; MICROBUILDER_PAD-1.5X2.0
BAT: MICROBUILDER_TESTPOINT1.5X2.0MM_NOCREAM; MICROBUILDER_PAD-1.5X2.0
BTN_DOWN: MJTP1250_SPST_SWITCH; MJTP1250
BTN_LEFT: MJTP1250_SPST_SWITCH; MJTP1250
BTN_LOCK: SPST_TACTILE_SWITCHRA; TL3330AF130QG
BTN_NEXT: MJTP1250_SPST_SWITCH; MJTP1250
BTN_NEXT_ALT: SPST_TACTILE_SWITCHRA; TL3330AF130QG
BTN_PREV: MJTP1250_SPST_SWITCH; MJTP1250
BTN_PREV_ALT: SPST_TACTILE_SWITCHRA; TL3330AF130QG
BTN_RESET: SPST_TACTILE_SWITCHRA; TL3330AF130QG
BTN_RIGHT: MJTP1250_SPST_SWITCH; MJTP1250
BTN_SEL: MJTP1250_SPST_SWITCH; MJTP1250
BTN_UP: MJTP1250_SPST_SWITCH; MJTP1250
C1: 10uF; 0805-NO
C2: 10uF; 0805_10MGAP
C3, C4, C5: 1uF; 0805_10MGAP
C6: 100uF; C1210
C7, C8, C13, C14, C15, C16: 1uF/25V; 0805-NO
C9: 4.7uF/25V; 0805-NO
C10, C11, C12: 1uF; 0805-NO
D1, D2: 3.6V; SOD-123
D3, D4, D5: MBR0530; SOD-123
EBSY: MICROBUILDER_SOLDERJUMPER_CLOSED; MICROBUILDER_SOLDERJUMPER_CLOSEDWIRE
ECS: MICROBUILDER_SOLDERJUMPER_CLOSED; MICROBUILDER_SOLDERJUMPER_CLOSEDWIRE
EDC: MICROBUILDER_SOLDERJUMPER_CLOSED; MICROBUILDER_SOLDERJUMPER_CLOSEDWIRE
EN: MICROBUILDER_TESTPOINT1.5X2.0MM_NOCREAM; MICROBUILDER_PAD-1.5X2.0
ERST: MICROBUILDER_SOLDERJUMPER_CLOSED; MICROBUILDER_SOLDERJUMPER_CLOSEDWIRE
FB1, FB2: FERRITE; 0805
FCS: MICROBUILDER_SOLDERJUMPER_CLOSED; MICROBUILDER_SOLDERJUMPER_CLOSEDWIRE
FID1, FID2, FID3, FID4, FID5, FID6: FIDUCIAL_1MM
GND: MICROBUILDER_TESTPOINT1.5X2.0MM_NOCREAM; MICROBUILDER_PAD-1.5X2.0
GOLD_ORB_SM1: OSHWLOGOLOGO5MM; OSHW_5MM
I2C: JST PH 4; JSTPH4
IC1: MCP23008/SO; SO18W
IC2: 23K256-I/SN; SOIC8_150MIL
IC3: MICROBUILDER_SPIFLASH_SOIC8; MICROBUILDER_SOIC8_150MIL
INT: MICROBUILDER_SOLDERJUMPER_CLOSED; MICROBUILDER_SOLDERJUMPER_CLOSEDWIRE
J1: MJ-3523-SMT; CUI_MJ-3523-SMT
JP1: PINHD-1X3; 1X03
JP2: PINHD-1X1; 1X01
L1: 10uH; INDUCTOR_4X4MM_NR401
MICROSD: MICROSD
MISO: MICROBUILDER_TESTPOINT1.5X2.0MM_NOCREAM; MICROBUILDER_PAD-1.5X2.0
MOSI: MICROBUILDER_TESTPOINT1.5X2.0MM_NOCREAM; MICROBUILDER_PAD-1.5X2.0
MS1: MICROBUILDER_FEATHERWING_SMTDUAL; MICROBUILDER_FEATHERWING_SMT2
Q1: IRLML0100; SOT23-3
R1, R2: 1K; _0805MP
R3, R4, R6, R7: 10K; _0805MP
R5: 0.47ohm; 0805_10MGAP
R8, R9: 100; _0805MP
RST: MICROBUILDER_TESTPOINT1.5X2.0MM_NOCREAM; MICROBUILDER_PAD-1.5X2.0
RX: MICROBUILDER_TESTPOINT1.5X2.0MM_NOCREAM; MICROBUILDER_PAD-1.5X2.0
SCK: MICROBUILDER_TESTPOINT1.5X2.0MM_NOCREAM; MICROBUILDER_PAD-1.5X2.0
SCL: MICROBUILDER_TESTPOINT1.5X2.0MM_NOCREAM; MICROBUILDER_PAD-1.5X2.0
SDA: MICROBUILDER_TESTPOINT1.5X2.0MM_NOCREAM; MICROBUILDER_PAD-1.5X2.0
SDCS: MICROBUILDER_SOLDERJUMPER_CLOSED; MICROBUILDER_SOLDERJUMPER_CLOSEDWIRE
SRCS: MICROBUILDER_SOLDERJUMPER_CLOSED; MICROBUILDER_SOLDERJUMPER_CLOSEDWIRE
SW1: SPDT_SWITCH; A10767
TP1, TP2, TP3: MICROBUILDER_TESTPOINT1.5X2.0MM_NOCREAM; MICROBUILDER_PAD-1.5X2.0
TX: MICROBUILDER_TESTPOINT1.5X2.0MM_NOCREAM; MICROBUILDER_PAD-1.5X2.0
U$1, U$4, U$5, U$7: MOUNTINGHOLE2.5; MOUNTINGHOLE_2.5_PLATED
U$2: WAVESHARE_4_2_INCH_EINK_DISPLAY; EINK_DISPLAY_4_2IN
USB: MICROBUILDER_TESTPOINT1.5X2.0MM_NOCREAM; MICROBUILDER_PAD-1.5X2.0

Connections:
+3V3: 3V.P$1, A1_PORT.2, A2_PORT.2, C1.1, C2.1, C3.1, C4.1, C5.1, C12.2, FB1.2, I2C.2 (V+), IC1.6 (/RST), IC1.18 (VCC), IC2.7 (#HOLD), IC2.8 (VCC), IC3.3 (WP#/IO2), IC3.7 (HOLD#/IO3), IC3.8 (VCC), JP2.1, L1.P$2 (2), MICROSD.4 (VDD), MS1.2 (3V), MS1.2' (3V), R3.1, R4.1, U$2.15 (VDDIO), U$2.16 (VCI)
A0: A0.P$1, MS1.5 (GPIOA0), MS1.5' (GPIOA0), R6.2, R7.1, R8.1
A1: A1.P$1, D1.C, MS1.6 (GPIOA1), MS1.6' (GPIOA1), R1.2
A1_: A1_PORT.3, R1.1
A2: A2.P$1, D2.C, MS1.7 (GPIOA2), MS1.7' (GPIOA2), R2.2
A2_: A2_PORT.3, R2.1
AGND: FB2.2, J1.2, R7.2, R9.1
AREF: AREF.P$1, MS1.3 (AREF), MS1.3' (AREF)
AUDIO_OUT: C6.2, J1.1
AVCC: FB1.1, R6.1
BTN_DOWN: BTN_DOWN.P$1, IC1.11 (GP1)
BTN_LEFT: BTN_LEFT.P$1, IC1.10 (GP0)
BTN_LOCK: BTN_LOCK.P$1, IC1.17 (GP7)
BTN_NEXT: BTN_NEXT.P$1, BTN_NEXT_ALT.P$1, IC1.16 (GP6)
BTN_PREV: BTN_PREV.P$1, BTN_PREV_ALT.P$1, IC1.15 (GP5)
BTN_RIGHT: BTN_RIGHT.P$1, IC1.13 (GP3)
BTN_SEL: BTN_SEL.P$1, IC1.14 (GP4)
BTN_UP: BTN_UP.P$1, IC1.12 (GP2)
EINK_BUSY: EBSY.2, U$2.9 (BUSY)
EINK_CS: ECS.1, U$2.12 (CS)
EINK_DC: EDC.1, U$2.11 (D/C)
EINK_RESET: ERST.2, U$2.10 (RST)
EN: EN.P$1, MS1.27 (EN), MS1.27' (EN), SW1.P$2
FLASH_CS: FCS.2, IC3.1 (SSEL)
GDR: Q1.1 (G), U$2.2 (GDR)
GND: A1_PORT.1, A2_PORT.1, BTN_DOWN.P$2, BTN_LEFT.P$2, BTN_LOCK.P$2, BTN_NEXT.P$2, BTN_NEXT_ALT.P$2, BTN_PREV.P$2, BTN_PREV_ALT.P$2, BTN_RESET.P$2, BTN_RIGHT.P$2, BTN_SEL.P$2, BTN_UP.P$2, C1.2, C2.2, C3.2, C4.2, C5.2, C7.2, C8.2, C10.1, C11.1, C12.1, C13.1, C14.1, C15.1, C16.1, D1.A, D2.A, D5.C, FB2.1, GND.P$1, I2C.1 (GND), IC1.3 (A2), IC1.4 (A1), IC1.5 (A0), IC1.9 (GND), IC2.4 (VSS), IC3.4 (VSS), JP1.2, MICROSD.6 (VSS), MICROSD.MT1 (GND), MICROSD.MT2 (GND1), MS1.4 (GND), MS1.4' (GND), R5.2, SW1.P$3 (S), U$2.8 (BS), U$2.17 (VSS)
GPIO_INT: IC1.8 (INT), INT.2
MISO: IC2.2 (MISO), IC3.2 (MISO), MICROSD.7 (DATA_OUT), MISO.P$1, MS1.13 (GPIOMISO), MS1.13' (GPIOMISO)
MOSI: IC2.5 (MOSI), IC3.5 (MOSI), MICROSD.3 (DATA_IN), MOSI.P$1, MS1.12 (GPIOMOSI), MS1.12' (GPIOMOSI), U$2.14 (SDI)
unnamed: C6.1, R8.2, R9.2
unnamed: C9.2, D4.C, D5.A
unnamed: C9.1, D3.A, L1.P$1 (1), Q1.3 (D)
unnamed: MS1.25 (GPIO13), MS1.25' (GPIO13), TP3.P$1
unnamed: MS1.24 (GPIO12), MS1.24' (GPIO12), TP2.P$1
unnamed: MS1.23 (GPIO11), MS1.23' (GPIO11), TP1.P$1
NC_D4: FCS.1, MS1.16 (NC), MS1.16' (NC)
PREVGH: C8.1, D3.C, U$2.21 (PREVGH)
PREVGL: C7.1, D4.A, U$2.23 (PREVGL)
RESE: Q1.2 (S), R5.1, U$2.3 (RESE)
RESET: BTN_RESET.P$1, MS1.1 (!RESET), MS1.1' (!RESET), RST.P$1
RX: JP1.3, MS1.14 (GPIORX), MS1.14' (GPIORX), RX.P$1
SCK: IC2.6 (SCLK), IC3.6 (SCK), MICROSD.5 (SCLK), MS1.11 (GPIOSCK), MS1.11' (GPIOSCK), SCK.P$1, U$2.13 (SCLK)
SCL: I2C.4 (SCL), IC1.1 (SCL), MS1.18 (GPIOSCL), MS1.18' (GPIOSCL), R4.2, SCL.P$1
SDA: I2C.3 (SDA), IC1.2 (SDA), MS1.17 (GPIOSDA), MS1.17' (GPIOSDA), R3.2, SDA.P$1
SD_CD: MICROSD.CD2 (CARD_DETECT1)
SD_CS: MICROSD.2 (CS), SDCS.1
SRAM_CS: IC2.1 (#CS), SRCS.1
TX: JP1.1, MS1.15 (GPIOTX), MS1.15' (GPIOTX), TX.P$1
VBAT: BAT.P$1, MS1.28 (VBAT), MS1.28' (VBAT)
VBUS: MS1.26 (USB), MS1.26' (USB), USB.P$1
VCOM: C16.2, U$2.24 (VCOM)
VDD: C13.2, U$2.18 (VDD)
VGH: C11.2, U$2.5 (VGH)
VGL: C10.2, U$2.4 (VGL)
VSH: C14.2, U$2.20 (VSH)
VSL: C15.2, U$2.22 (VSL)
_EINK_BUSY: EBSY.1, MS1.8 (GPIOA3), MS1.8' (GPIOA3)
_EINK_CS: ECS.2, MS1.21 (GPIO9), MS1.21' (GPIO9)
_EINK_DC: EDC.2, MS1.22 (GPIO10), MS1.22' (GPIO10)
_EINK_RESET: ERST.1, MS1.9 (GPIOA4), MS1.9' (GPIOA4)
_GPIO_INT: INT.1, MS1.10 (GPIOA5), MS1.10' (GPIOA5)
_SD_CS: MS1.19 (GPIO5), MS1.19' (GPIO5), SDCS.2
_SRAM_CS: MS1.20 (GPIO6), MS1.20' (GPIO6), SRCS.2

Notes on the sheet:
FEATHER CONNECTOR
SD CARD
EINK DISPLAY
HEADPHONE JACK
RESET BUTTON
ENABLE SWITCH
POWER FILTERING
BUTTONS AND GPIO
JST PORTS
SRAM CHIP
FLASH CHIP (FOR UNIFONT)
SERIAL PORT

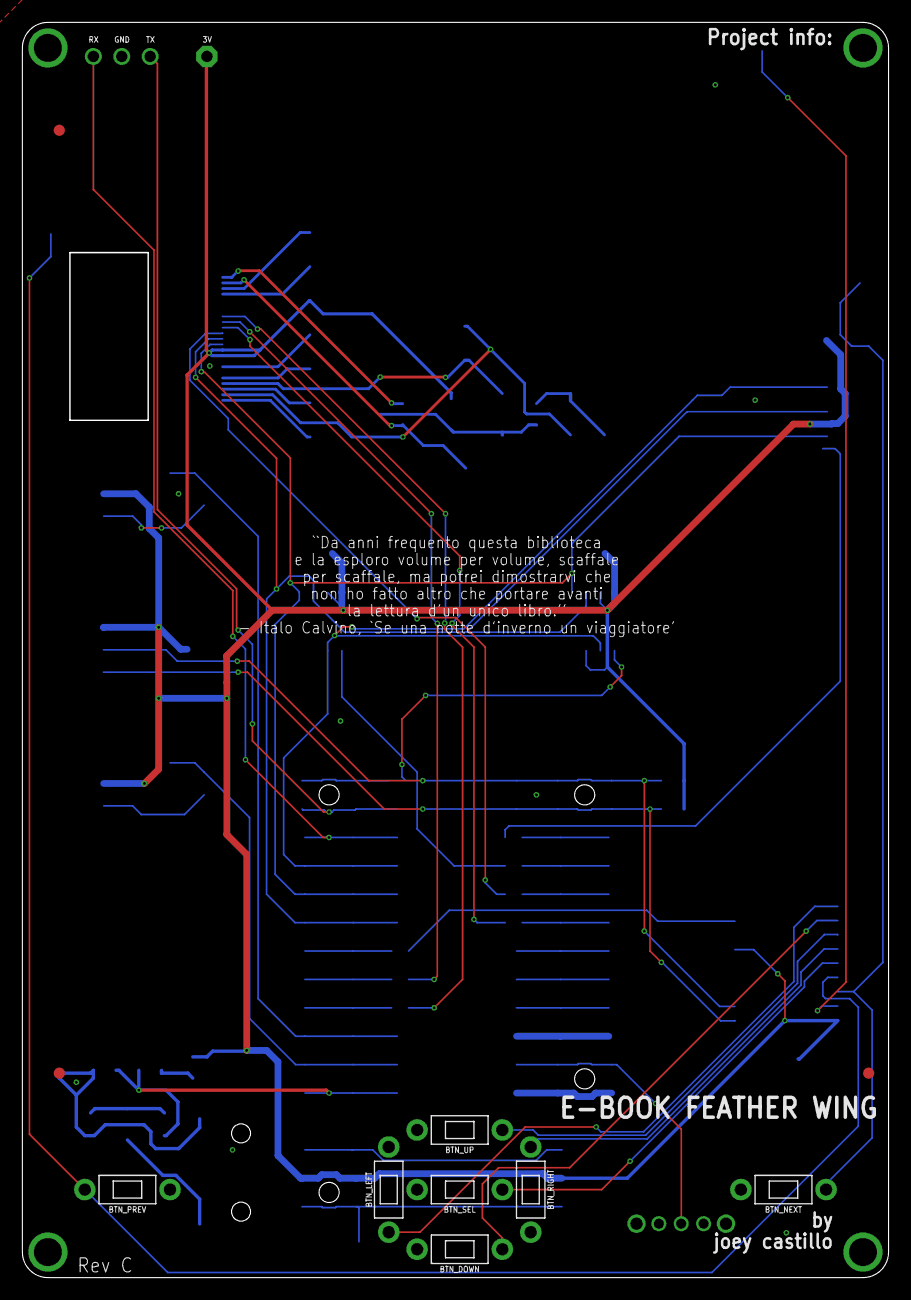
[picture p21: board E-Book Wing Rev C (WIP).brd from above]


Board: 2 copper layers, 77.5 x 112.3 mm, 97 parts (86 on the bottom side), 62 nets.

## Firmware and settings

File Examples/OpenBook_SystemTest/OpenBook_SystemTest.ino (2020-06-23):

#include <OpenBook.h>
#include <Adafruit_SPIFlash.h>
#include <SdFat.h>
#include <Adafruit_NeoPixel.h>
#include <Adafruit_MP3.h>
#include "vivaldi.h" // Violin Concerto in G minor, RV 315

OpenBook *book = new OpenBook();
Adafruit_FlashTransport_QSPI qspiTransport(PIN_QSPI_SCK, PIN_QSPI_CS, PIN_QSPI_IO0, PIN_QSPI_IO1, PIN_QSPI_IO2, PIN_QSPI_IO3);
Adafruit_SPIFlash qspiFlash(&qspiTransport);
Adafruit_FlashTransport_SPI spiTransport(OPENBOOK_BCS, &SPI);
Adafruit_SPIFlash babelFlash(&spiTransport);
SdFat sd;
Adafruit_NeoPixel pixel(1, OPENBOOK_NEOPIXEL, NEO_GRB + NEO_KHZ800);
Adafruit_MP3 player;

uint8_t *currentPtr;
uint32_t thisManyBytesLeft;

void setup() {
  char cmd;
  
  int qspiFlashPassed = -1;
  int babelFlashPassed = -1;
  int cardDetectPassed = -1;
  int sdCardPassed = -1;
  int buttonsPassed = -1;
  int pixelPassed = -1;
  int headphonesPassed = -1;
  int inlineButtonPassed = -1;
  int micAmpPassed = -1;
  
  int startTime;
  int micValue;

  book->configureShiftButtons();
  pinMode(OPENBOOK_MIC_SHUTDOWN, OUTPUT);
  digitalWrite(OPENBOOK_MIC_SHUTDOWN, HIGH);
  
  Serial.begin(115200);
  while(!Serial);

  Serial.println("Open Book System Test");
  Serial.println("=====================");
  Serial.println("This sketch runs interactively in the Arduino serial monitor. \nWhen prompted to take an action, take that action.");
  Serial.println("Some tests reqiure that you answer a question. \nEnter a single letter in response to each prompt.");
  Serial.println();

  Serial.println("Testing power...");
  pinMode(OPENBOOK_BATTERY_MONITOR, INPUT);
  pinMode(OPENBOOK_USB_MONITOR, INPUT);
  int batmonPassed = analogRead(OPENBOOK_BATTERY_MONITOR) > 300;
  int busmonPassed = analogRead(OPENBOOK_USB_MONITOR) > 300;

  Serial.println("Testing internal storage...");
  qspiFlash.begin();
  qspiFlashPassed = qspiFlash.size() == 2097152 || qspiFlash.size() == 4194304;

  babelFlash.begin();
  babelFlashPassed = babelFlash.size() == 2097152 || babelFlash.size() == 4194304;

  Serial.println("-----------------------------------");
  Serial.println("If you have an SD card in the slot, remove it now, then enter 'C' to continue.");
  Serial.println("To skip testing of the SD card, enter 'S'");
  if (waitForAnswer('C') == -1) goto BUTTONS;
  
  cardDetectPassed = book->sdCardState() == OPEN_BOOK_SD_CARD_NOT_PRESENT;
  Serial.println("Now insert the SD card, and enter 'C' to continue.");
  waitForAnswer('C');
  cardDetectPassed &= book->sdCardState() == OPEN_BOOK_SD_CARD_PRESENT;

  sdCardPassed = sd.begin(4, SD_SCK_MHZ(50));

BUTTONS:
  Serial.println("-----------------------------------");
  Serial.println("Do you wish to test the buttons? Enter 'Y' to test, or 'N' to skip.");
  if (waitForAnswer('Y', 'N') != 1) goto PIXEL;
  buttonsPassed = true;
  Serial.println("Press the 'Previous Page' button until you see 'OK' appear on the console. \nIf 'OK' does not appear, enter 'F' in the console to mark the test failed.");
  buttonsPassed &= waitForButton(OPENBOOK_BUTTONMASK_PREVIOUS);
  Serial.println("Press the 'Next Page' button until you see 'OK' appear on the console. \nIf 'OK' does not appear, enter 'F' in the console to mark the test failed.");
  buttonsPassed &= waitForButton(OPENBOOK_BUTTONMASK_NEXT);
  Serial.println("Now, let's move on to the direction pad in the middle.");
  Serial.println("Press the 'Left' button on the D-pad until you see 'OK' appear on the console. \nIf 'OK' does not appear, enter 'F' in the console to mark the test failed.");
  buttonsPassed &= waitForButton(OPENBOOK_BUTTONMASK_LEFT);
  Serial.println("Press the 'Down' button until you see 'OK' appear on the console. \nIf 'OK' does not appear, enter 'F' in the console to mark the test failed.");
  buttonsPassed &= waitForButton(OPENBOOK_BUTTONMASK_DOWN);
  Serial.println("Press the 'Up' button until you see 'OK' appear on the console. \nIf 'OK' does not appear, enter 'F' in the console to mark the test failed.");
  buttonsPassed &= waitForButton(OPENBOOK_BUTTONMASK_UP);
  Serial.println("Press the 'Right' button until you see 'OK' appear on the console. \nIf 'OK' does not appear, enter 'F' in the console to mark the test failed.");
  buttonsPassed &= waitForButton(OPENBOOK_BUTTONMASK_RIGHT);
  Serial.println("Press the 'Select' button until you see 'OK' appear on the console. \nIf 'OK' does not appear, enter 'F' in the console to mark the test failed.");
  buttonsPassed &= waitForButton(OPENBOOK_BUTTONMASK_SELECT);
  Serial.println("Press the 'Lock' button until you see 'OK' appear on the console. \nIf 'OK' does not appear, enter 'F' in the console to mark the test failed.");
  buttonsPassed &= waitForButton(OPENBOOK_BUTTONMASK_LOCK);

PIXEL:
  Serial.println("-----------------------------------");
  Serial.println("Testing Neopixel...");
  pixel.begin();
  pixel.setPixelColor(0, pixel.Color(150, 150, 0));
  pixel.show();
  Serial.println("Is the Neopixel showing a yellow color?");
  Serial.println("Enter 'Y' for Yes, 'N' for No, or 'S' to skip this test.");
  pixelPassed = waitForAnswer('Y', 'N'); // returns -1 if skipped, no need for a goto here.
  pixel.setPixelColor(0, pixel.Color(0, 0, 0));
  pixel.show();

  Serial.println("-----------------------------------");
  Serial.println("If you wish to test audio output, the headset button or the microphone, \nplug a 3.5mm headset in to the headphone jack now.");
  Serial.println("Do you wish to audio output? Enter 'Y' to test, or 'N' to skip.");
  if (waitForAnswer('Y', 'N') != 1) goto INLINE_BUTTON;

  Serial.println("-----------------------------------");
  Serial.println("Testing headphones...");
  analogWrite(OPENBOOK_AUDIO_R, 2048);
  analogWrite(OPENBOOK_AUDIO_L, 2048);
  currentPtr = (uint8_t*)vivaldi_mp3;
  thisManyBytesLeft = sizeof(vivaldi_mp3);
  player.begin();
  player.setSampleReadyCallback(writeDacs);
  player.setBufferCallback(getMoreData);
  player.play();
  startTime = millis();
  while(millis() < startTime + 2000) player.tick();
  player.pause();
  Serial.println("Did you hear audio in both the left and right channels?");
  Serial.println("Enter 'Y' for Yes or 'N' for No.");
  headphonesPassed = waitForAnswer('Y', 'N');

INLINE_BUTTON:
  Serial.println("-----------------------------------");
  Serial.println("Do you wish to test the inline button? Enter 'Y' to test, or 'N' to skip.");
  if (waitForAnswer('Y', 'N') != 1) goto MICAMP;
  pinMode(OPENBOOK_MIC_RAW, INPUT_PULLUP);
  delay(500);
  Serial.println("Tap the inline button on the headset until you see 'OK' appear on the console. \nIf 'OK' does not appear, enter 'F' in the console to mark the test failed.");
  while(digitalRead(OPENBOOK_MIC_RAW) == 1) {
    if (Serial.available()) {
      if (toupper(Serial.read()) == 'F') {
        inlineButtonPassed = false;
        goto MICAMP;
      }
    }
  }
  inlineButtonPassed = true;
  Serial.println("OK\n");

MICAMP:
  Serial.println("-----------------------------------");
  Serial.println("Do you wish to the microphone amplifier?");
  Serial.println("This test will play back the output from the mic amp into the headphones \nfor five seconds, so you can listen for an echo of your voice.");
  Serial.println("Enter 'Y' to test, or 'N' to skip.");
  if (waitForAnswer('Y', 'N') != 1) goto RESULTS;
  pinMode(OPENBOOK_MIC_RAW, INPUT);
  delay(500);
  digitalWrite(OPENBOOK_MIC_SHUTDOWN, LOW);
  pinMode(A10, INPUT);
  Serial.println("Make some sounds and listen for playback in the headphones.");
  startTime = millis();
  while(millis() < startTime + 5000) {
    micValue = analogRead(OPENBOOK_MIC_AMPLIFIED);
    analogWrite(OPENBOOK_AUDIO_R, micValue * 4);
    analogWrite(OPENBOOK_AUDIO_L, micValue * 4);
  }
  digitalWrite(OPENBOOK_MIC_SHUTDOWN, HIGH);
  Serial.println("Did you hear audio from the microphone played back in the headphones?");
  Serial.println("Enter 'Y' for Yes or 'N' for No.");
  micAmpPassed = waitForAnswer('Y', 'N');

RESULTS:
  Serial.println("\n\n\n\n");
  Serial.println("   OPEN BOOK TEST RESULTS");
  Serial.println("============================");
  Serial.print("Battery Monitior......"); printlnResult(batmonPassed);
  Serial.print("VBUS Monitior........."); printlnResult(busmonPassed);
  Serial.print("QSPI Flash Chip......."); printlnResult(qspiFlashPassed);
  Serial.print("Babel Flash Chip......"); printlnResult(babelFlashPassed);
  Serial.print("SD Card Detect........"); printlnResult(cardDetectPassed);
  Serial.print("SD Card..............."); printlnResult(sdCardPassed);
  Serial.print("Buttons..............."); printlnResult(buttonsPassed);
  Serial.print("Neopixel.............."); printlnResult(pixelPassed);
  Serial.print("Headphones............"); printlnResult(headphonesPassed);
  Serial.print("Inline Button........."); printlnResult(inlineButtonPassed);
  Serial.print("Mic Amp..............."); printlnResult(micAmpPassed);
}

void loop() {
}

void printlnResult(int status) {
  switch (status) {
    case -1:
      Serial.println("Skipped");
      break;
    case 0:
      Serial.println("** FAILED **");
      break;
    case 1:
      Serial.println("Passed");
      break;
  }
  
}

int waitForAnswer(char affirmative) {
  return waitForAnswer(affirmative, 0);
}

int waitForAnswer(char affirmative, char negative) {
  char command = 0;
  while (true) {
    while (!Serial.available());
    char cmd = toupper(Serial.read());
    if (cmd == 'S') return -1;
    if (cmd == affirmative) return 1;
    if (negative && cmd == negative) return 0;
  }
}

bool waitForButton(uint8_t button) {
  while(book->readButtons() != button) {
    if (Serial.available()) {
      if (toupper(Serial.read()) == 'F') {
        return false;
      }
    }
  }

  Serial.println("OK\n");
  return true;
}

void writeDacs(int16_t l, int16_t r){
  analogWrite(OPENBOOK_AUDIO_R, map(r, -32768, 32767, 0, 4095));
  analogWrite(OPENBOOK_AUDIO_L, map(l, -32768, 32767, 0, 4095));
}

int getMoreData(uint8_t *writeHere, int thisManyBytes){
  int toWrite = min(thisManyBytesLeft, thisManyBytes);
  memcpy(writeHere, currentPtr, toWrite);
  currentPtr += toWrite;
  thisManyBytesLeft -= toWrite;
  return toWrite;
}

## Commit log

2019-08-14 remove 5V option, more complicated than I thought
    [E-Book Wing Rev B.brd, E-Book Wing Rev B.sch]
2019-08-16 final commit of rev B as submitted to OSH Park
    [E-Book Wing Rev B.brd, E-Book Wing Rev B.sch]
2019-09-02 final tweaks and BOM for rev B
    [E-Book Wing Rev B.brd, E-Book Wing Rev B.sch]
2019-09-03 added a rev C, embiggens the board at top
    [E-Book Wing Rev C (WIP).brd, E-Book Wing Rev C (WIP).sch]
2019-09-09 eink display's tDocu layer was off, scooting it back into line with reality
    [E-Book Wing Rev C (WIP).brd, E-Book Wing Rev C (WIP).sch]
2019-09-13 surface mount part swap, two more fiducials
    [E-Book Wing Rev C (WIP).brd, E-Book Wing Rev C (WIP).sch]
2019-09-13 lol nevermind this thru-hole switch is cheaper
    [E-Book Wing Rev C (WIP).brd, E-Book Wing Rev C (WIP).sch]
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2019-09-16 move traces out of text areas
    [Open Book Rev A (WIP).brd]
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2019-09-24 move leds topside, thru-hole style. other design tweaks
    [Open Book Rev A (WIP).brd, Open Book Rev A (WIP).sch]
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2019-10-15 add these cool right-angle LEDs (that i ordered too many of)
    [Open Book Rev A (WIP).brd, Open Book Rev A (WIP).sch]
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2019-10-15 move surface mount chip away from thru-hole components
    [Open Book Rev A (WIP).brd]
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2019-10-17 final version of open book A1-01 submitted to OSH Park
    [Open Book A1 Rev 01.brd, Open Book A1 Rev 01.sch]
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2019-10-29 rearrange power supply block, power neopixel from regulator
    [Open Book A1 Rev 02 (WIP).brd, Open Book A1 Rev 02 (WIP).sch]
2019-10-29 fix buttons, add pulldown resistors & remove lock btn from shift reg
    [Open Book A1 Rev 02 (WIP).brd, Open Book A1 Rev 02 (WIP).sch]
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2019-11-01 put sd card detect signal on shift register
    [Open Book A1 Rev 02 (WIP).brd, Open Book A1 Rev 02 (WIP).sch]
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2019-11-04 scoot filter caps away from chip (easier for manual rework if needed)
    [Open Book A1 Rev 02 (WIP).brd]
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2019-11-05 improve clearance around C24
    [Open Book A1 Rev 02 (WIP).brd]
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2019-11-05 correct component values
    [Open Book A1 Rev 02 (WIP).brd, Open Book A1 Rev 02 (WIP).sch]
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2019-11-07 fix typo
    [Open Book A1 Rev 02 (WIP).brd]
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2019-11-07 more clearance around resistor arrays
    [Open Book A1 Rev 02 (WIP).brd]
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2019-11-08 restore reset stability circuit
    [Open Book A1 Rev 02 (WIP).brd, Open Book A1 Rev 02 (WIP).sch]
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2019-11-09 space out mic amp section for easier manual placement
    [Open Book A1 Rev 02 (WIP).brd]
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2019-11-09 final version of open book A1-02 submitted to OSH Park
    [Open Book A1 Rev 02.brd, Open Book A1 Rev 02.sch]
2019-11-09 restore calvino quote, final version of wing A1-03 submitted to OSH Park
    [E-Book Wing Rev C.brd, E-Book Wing Rev C.sch]
2019-11-11 revised button footprints and headphone jack, submitted to OSH Park in lieu of rev 3
    [E-Book Wing A1 Rev 04.brd, E-Book Wing A1 Rev 04.sch]
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2019-11-30 typo on the silkscreen, correct pin numbers for button register
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2019-12-03 add board readme, mark rev 03 as WIP
    [Open Book A1 Rev 03 (WIP).brd, Open Book A1 Rev 03 (WIP).sch]
2019-12-03 maybe power and gnd pads shouldn't be so close together
    [Open Book A1 Rev 03 (WIP).brd, Open Book A1 Rev 03 (WIP).sch]
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2019-12-06 rev 3 (not made) just fixes a silkscreen typo
    [Open Book A1 Rev 03.brd, Open Book A1 Rev 03.sch]
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2019-12-06 rev 4: move babel chip into SRAM spot
    [Open Book A1 Rev 04.brd]
2019-12-06 resistor array to monitor both VBAT and VBUS
    [Open Book A1 Rev 04.brd, Open Book A1 Rev 04.sch]
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2019-12-06 fix typo in net name
    [Open Book A1 Rev 04.brd, Open Book A1 Rev 04.sch]
2019-12-09 rename mic amp nets to match rev 3
    [Open Book A1 Rev 04.brd, Open Book A1 Rev 04.sch]
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2020-01-25 better thru-hole button footprints, new right angle buttons
    [OSO-BOOK-A1-05.brd, OSO-BOOK-A1-05.sch]
2020-01-25 connect shield to ground via RC (reduce headphone noise?)
    [OSO-BOOK-A1-05.brd, OSO-BOOK-A1-05.sch]
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2020-01-25 fix silksreen typo (serial is SERCOM5)
    [OSO-BOOK-A1-05.brd]
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2020-01-25 fix new button labels
    [OSO-BOWI-A1-05 (WIP).brd]
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2020-01-28 if i do this again, accessory should be on PA05 to make use of the DAC
    [OSO-TIBO-A1-03.brd, OSO-TIBO-A1-03.sch]
2020-01-28 swapped micraw and accessoory pins, need to route signals
    [OSO-TIBO-A1-03 (WIP - DO NOT USE YET).brd, OSO-TIBO-A1-03 (WIP - DO NOT USE YET).sch]
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2020-01-28 use 4MB flash so babel can live there
    [OSO-TIBO-A1-03 (WIP - DO NOT USE YET).brd, OSO-TIBO-A1-03 (WIP - DO NOT USE YET).sch]
2020-01-28 fix I2C routing snafu
    [OSO-TIBO-A1-03 (WIP - DO NOT USE YET).brd, OSO-TIBO-A1-03 (WIP - DO NOT USE YET).sch]
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2020-02-25 fix one missed number in BOM table
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2020-06-05 last tweaks to A1-05 before sending to fab
    [OSO-BOOK-A1-05.brd, OSO-BOOK-A1-05.sch]
2020-06-12 update BOM and gerbers for final rev of wing
    [1-click-bom.csv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]
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2020-06-27 fix audio pin modes
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2020-07-16 fix R12 reference in the BOM
    [1-click-bom.csv]
2020-07-20 e-book wing: fix one un-tented via
    [OSO-BOWI-A1-05.brd]
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2020-08-16 IL0398 driver: fix shades of gray
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2020-08-22 replace digireel part numbers with cut tape
    [1-click-bom.csv]
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2020-08-30 BOM links on kitspace were the wrong way round
    Link for featherwing took you to open book feather and vice versa. corrected, no other changes made.
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2020-09-13 fix one untented via
    [OSO-BOWI-A1-06.brd]
2020-09-13 book rev 6: pull-ups on SPI devices, headphone bias
    [OSO-BOOK-A1-06.brd, OSO-BOOK-A1-06.sch]
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2020-10-10 Open Book PCB Migration to KiCad
    This is a set of KiCad files from the posted Eagle files.
    For this conversion, the latest version Eagle files were used (OSO-BOOK-A1-06).
    The schematics were imported in three sheets, plus the cover sheet (total four).
    All text, net labels, global net labels, component values and references were adjusted to KiCad’s default size for consistency.
    Some nets were imported with net labels (because they were present only on one sheet) and some with global net labels (because they were used in multiple sheets).
    All duplicate global net labels were deleted from power nets (power nets are global nets by default).
    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
    [OSO-BOOK-A1-06-BOM-DK.xlsx, OSO-BOOK-A1-06-BOM.csv, OSO-BOOK-A1-06.kicad_pcb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]
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2020-10-11 E-Book Feather Wing PCB Migration to KiCad
    For this conversion, the latest version Eagle files were used (OSO-BOWI-A1-06).
    The schematic was imported in a single sheet.
    The converted libraries (symbol and footprints) were examined for accuracy.
    During this conversion, a great deal of effort was put to maintain the original PCB design as feasible, by adjusting the silkscreen size and its locati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
    [OSO-BOWI-A1-06-BOM-DK.xlsx, OSO-BOWI-A1-06-BOM.csv, OSO-BOWI-A1-06.kicad_pcb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]
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2020-10-14 Revised E-Book Wing silkscreen labels.
    Addressing comment for the solder jumpers on the E-Book Wing that had silkscreen labels, such as TX1/RX1/ECS1 etc, where the number 1 was appended after the original name, which was crowding the labe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
    [OSO-BOWI-A1-06.kicad_pcb, OSO-BOWI-A1-06.sch]
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2020-11-01 1-click BOM: fix typo
    [1-click-bom.csv]
2020-12-01 first crack at ESP32-S2 Open Book
    [OSO-BOOK-B1-00.brd, OSO-BOOK-B1-00.sch]
2020-12-16 fix incorrect part number in e-book wing BOM
    [1-click-bom.csv]
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2022-09-28 project reboot
    [1-click-bom.csv, OSO-BOOK-A1-05 Solder Stencil.dxf, OSO-BOOK-A1-05.brd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]
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2022-11-15 shrink outline of JLC module, size minimum no longer applies
    [OSO-BOOK-C2-03.brd, OSO-BOOK-C2-03.sch]
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2022-12-16 Fix capacitor part number
    [1-click-bom.csv]
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2023-12-02 fabrication files from hackaday submission, new screen experiment
    [OSO-BOOK-B1-02_prerelease.csv, OSO-BOOK-B1.kicad_sch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]

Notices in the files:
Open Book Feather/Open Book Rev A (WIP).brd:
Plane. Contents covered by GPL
